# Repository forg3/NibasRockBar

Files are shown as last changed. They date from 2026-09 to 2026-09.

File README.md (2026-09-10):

# NibasRockBar — Pulseira Inteligente de Identificação e Localização

Sistema de pulseira eletrônica (NFC + BLE) para identificação de clientes e localização
indoor no salão, integrado ao sistema de caixa **Deli**. Atendimento continua 100% humano —
garçom tira o pedido, equipe serve bebidas e a cozinha prepara os pratos. A pulseira só
identifica o cliente e ajuda a equipe a localizá-lo mais rápido.

## Fluxo do produto

1. **Check-in** — cliente recebe uma pulseira livre; o sistema abre a comanda no Deli.
2. **Pedido** — garçom lê a pulseira (NFC) e lança o pedido na comanda certa, em qualquer mesa.
3. **Localização** — o app do garçom mostra a área do salão onde cada comanda está (BLE).
4. **Conferência e saída** — caixa fecha a comanda no Deli, cliente paga, pulseira libera
   sozinha para o próximo cliente.

## Estrutura do repositório

| Caminho | Conteúdo |
|---|---|
| `PROPOSTA_SMART_BADGE_PUB_v3.md` | Especificação do produto (hardware, fluxo, fabricação) |
| `proposta_proprietario.html` | Proposta visual para apresentar ao proprietário do pub |
| `modelo_3d_prototipo.html` | Modelo 3D interativo do protótipo (pulseira + disco) |
| `ORCAMENTO_PROTOTIPAGEM.md` | Orçamento detalhado para 5 unidades protótipo |
| `BOM_custos_prototipos.csv` | BOM com custo por unidade (lote de teste) |
| `BOM_smartbadge_v2.csv` | BOM recomendada (módulo BLE certificado) |
| `BOM_discreta_corrigida_nRF52810_QFN32.csv` | BOM alternativa (SoC discreto), pinagem verificada no datasheet Nordic |
| `netlist_conexoes.md` | Tabela de conexões pino a pino, pronta para KiCad |
| `RELATORIO_REVISAO_TECNICA.md` | Revisão técnica completa (matemática de bateria, RF, RSSI, NFC) |
| `firmware/main.c` | Firmware da pulseira (nRF5 SDK) — beacon BLE + leitura de bateria |
| `firmware/nrf/` | Projeto de compilação nRF5 SDK 17.1.0 (pca10040e/s112, nRF52810 + SoftDevice S112 7.2.0) — compila com `make -C firmware/nrf/armgcc` (requer `arm-none-eabi-gcc`) |
| `gateway_esp32/gateway_esp32.ino` | Firmware do gateway de teto (scan BLE + filtro EWMA + MQTT) — compila no Arduino IDE com esquema de partição Huge APP |
| `backend/app.py` | Servidor local (FastAPI) — localização por RSSI + inventário de pulseiras |
| `backend/deli_adapter.py` | Integração real com a API pública do Deli (plataforma Fudo) |
| `integracao_deli/README.md` | Como habilitar e usar a API do Deli |
| `hardware/kicad/docs/decisao_forma_fisica.md` | Decisão da variante A: troca do módulo E73 pelo Fanstel BM832A |
| `hardware/kicad/docs/layout_status.md` | Estado atual dos layouts das placas |
| `hardware/kicad/docs/procedimento_vna.md` | Procedimento de tuning da antena/RF com VNA |
| `hardware/kicad/docs/cotacao_fabricacao.md` | Cotação de fabricação (com GATE — nada submetido ainda) |
| `hardware/kicad/*/exports/fab/` | Pacote de fabricação gerado (Gerbers, furação, BOM, posição) |
| `docs/security-audit/relatorio-auditoria-seguranca.pdf` | Relatório da auditoria de segurança |

## Arquitetura (visão geral)

```
Pulseira (NFC + BLE) ──► Gateway ESP32 (scan BLE) ──► MQTT ──► Backend local (FastAPI)
                                                                      │
                                                                      ├─► Localização por mesa/zona
                                                                      └─► Deli API (abre/monitora comanda)

Garçom (app/tablet) ──► lê NFC da pulseira ──► lança pedido direto no Deli
```

- **Identificação (NFC)**: tag passiva na pulseira, lida pelo garçom para abrir/lançar pedidos.
- **Localização (BLE)**: pulseira transmite beacon; gateways de teto (ESP32) captam RSSI e
  publicam via MQTT; o backend decide a zona mais próxima (vizinho mais próximo com histerese).
- **Caixa/pagamento**: sempre no Deli — este projeto não duplica cardápio, pagamento nem fiscal.

## Como rodar o backend localmente

```bash
cd backend
pip install -r requirements.txt
export DELI_API_KEY="..."
export DELI_API_SECRET="..."
export NIBAS_API_KEY="..."  # exigida em toda chamada via header X-API-Key
uvicorn app:app --host 0.0.0.0 --port 8000
```

Requer um broker MQTT local (ex: Mosquitto) publicando em `pub/telemetria/#`.

## Hardware

- Disco Ø32 mm, cápsula IP67, pulseira esportiva de silicone.
- Identificação: NXP NTAG213 (inlay pronto, 25 mm).
- Localização (variante A): módulo **Fanstel BM832A** (SoC Nordic nRF52810) — substitui o
  Ebyte E73, decisão documentada em `hardware/kicad/docs/decisao_forma_fisica.md`.
- Bateria: CR2032 com suporte **Keystone 1060** (SMD — o 1059 é THM e não serve),
  ~1,5–2 anos de autonomia estimada.
- Fabricação recomendada: PCBWay ou JLCPCB, regime turnkey.

Detalhes completos, matemática de engenharia e decisões de projeto: ver
`RELATORIO_REVISAO_TECNICA.md` e `PROPOSTA_SMART_BADGE_PUB_v3.md`.
Estado dos layouts: `hardware/kicad/docs/layout_status.md`.
Tuning da antena/RF: `hardware/kicad/docs/procedimento_vna.md`.

## Fabricação

- Pacote de fabricação gerado em `hardware/kicad/*/exports/fab/` (Gerbers, furação, BOM, posição).
- Cotação e checklist de submissão em `hardware/kicad/docs/cotacao_fabricacao.md` —
  **GATE: nada submetido a fabricante ainda.**

## Segurança

- O backend exige autenticação em toda chamada via header `X-API-Key` (chave em `NIBAS_API_KEY`).
- Relatório da auditoria de segurança em `docs/security-audit/relatorio-auditoria-seguranca.pdf`.

## Status

Fase de especificação e protótipo — orçamento para lote de 5 unidades de teste em
`ORCAMENTO_PROTOTIPAGEM.md`. Integração com o Deli implementada e documentada, pendente de
credenciais reais (`DELI_API_KEY`/`DELI_API_SECRET`) para teste de ponta a ponta.

## Pendências

- ANATEL: item aberto (não bloqueia bancada; confirmar antes de operar com público).
  Homologação vale só para os radiadores intencionais (BM832A e ESP32, 2,4 GHz) — PCB,
  bateria, NFC passiva, ferrite e cápsula não certificam; se os módulos já forem
  homologados, o produto usa processo simplificado com os laudos do módulo (confirmar com OCD).
- BOM raiz: corrigir Keystone 1059 → 1060.
- Alimentação do BM832A: indutores do DC/DC integrados ao módulo (fonte: página oficial
  Fanstel) — fecha o item aberto #2.

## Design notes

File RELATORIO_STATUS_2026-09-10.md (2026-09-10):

---
title: "2º Relatório de Status do Projeto"
subtitle: "NibasRockBar — Smart Badge Pub (pulseira NFC+BLE + gateway ESP32)"
date: "10 de setembro de 2026"
lang: pt-BR
---

# 1. Contexto e base deste relatório

Este é o 2º relatório de status. Cobre o delta desde o `RELATORIO_TRABALHO_2026-09-09`
(sessões de esquemáticos + layouts + firmware + GitHub).

**Fontes lidas para este relatório:**

- `hardware/kicad/docs/layout_status.md`
- `hardware/kicad/docs/decisao_forma_fisica.md`
- `hardware/kicad/docs/cotacao_fabricacao.md`
- `hardware/kicad/docs/procedimento_vna.md`
- `hardware/kicad/wristband_discreto/exports/audit.md`
- `hardware/kicad/wristband_modulo/exports/audit.md`
- `hardware/kicad/gateway_esp32/exports/audit.md`
- `git log` (HEAD = `d4b8bd6`, sincronizado com `origin/main`; ~50 arquivos modificados/novos no working tree, ainda não commitados)
- JSONs de DRC atuais no working tree (`exports/drc_*.json`), footprints em `hardware/kicad/libs/`, `firmware/nrf/armgcc/_build/`, pacotes `exports/fab/`

**Decisões de negócio seguem fechadas:** sem self-service (garçom tira o pedido, equipe serve tudo);
pulseira só identifica e localiza; Deli é o sistema de registro/pagamento/fiscal; checkout automático
apenas por polling de `saleState` (o projeto nunca fecha comanda por conta própria).

---

# 2. Decisão física: E73 → Fanstel BM832A

**Decidido** (`docs/decisao_forma_fisica.md`, 2026-09-09). A variante A troca o módulo
Ebyte E73-2G4M04S-52810 (17,5 × 28,7 mm, diagonal ≈ 33,5 mm) pelo **Fanstel BM832A**
(nRF52810, **10,2 × 15 × 1,9 mm**, diagonal ≈ 18,2 mm, US$ 3,61 vs US$ 3,59 — paridade de preço).

Por que:

1. **Sem cápsula Ø34–38 no mercado.** Não existe cápsula vazia IP67 redonda Ø34–38 mm à venda.
   O que existe são beacons prontos (Trax10214 Ø35,9 mm; Minew B10 Ø38 mm; Minew E7 Ø39 × 15,5 mm
   IP67 — menor cápsula comprovada, para CR2477). Aumentar a cápsula além de Ø32 mm exigiria
   moldagem custom (ferramental + NRE), inviável para protótipo de 5 unidades.
   Fontes: beacontrax.com, minew.com, takachi-enclosure.com.
2. **Overhang castelado refutado.** JLCPCB e PCBWay exigem furo PTH bissecado pelo contorno +
   pad com extensão ≥ 0,5 mm para dentro do contorno. Os pads das pontas do E73 ficariam fora do
   arco do disco (sagitta ≈ 1,65 mm) — viola a regra nas duas casas. Manter o E73 com overhang
   **não é fabricável**.
3. **BM832A encaixa, custa igual, zero migração de firmware.** Mesmo SoC nRF52810 → SoftDevice S112
   funciona direto. VDD 1,7–3,6 V (CR2032 ok). Antena integrada + certificações FCC/CE/TELEC.
   **Indutores do DC/DC integrados ao módulo** (página oficial Fanstel) — fecha o item aberto #2
   do relatório anterior (dúvida do indutor interno do E73-2G4M04S1A).

**Ressalva honesta (registrada no doc):** diagonal caber no disco não significa layout fechado.
O keepout de antena do BM832A (antena estendida fora do ground plane — verificar dimensões exatas
no manual Fanstel) e a coexistência com BT1 (porta-pilha CR2032) e TAG1 (NTAG213) precisam de
validação geométrica no KiCad antes de considerar a placa resolvida. Impacto previsto: novo
símbolo + footprint do BM832A (transcritos do datasheet Fanstel), troca de U1 no `.kicad_sch`
da variante A, re-layout da placa.

---

# 3. Footprints corrigidos

## 3.1 Porta-pilha: Keystone 1060 (não 1059)

O footprint antigo `Keystone_1059_CR2032_SMT` foi **removido** — e com motivo: **Keystone 1059 é a
variante THM**; a variante SMT correta é a **Keystone 1060** (série Vibra-Fit, low-profile para
CR2032/CR2025). Novo footprint `Keystone_1060_CR2032_SMT` com dimensões do **drawing oficial
Keystone 1060 rev C** (`https://www.keyelco.com/product-pdf.cfm?p=726`, registrado no campo
Datasheet do footprint): pads de montagem 11,00 × 7,01 mm no centro + abas de 2,59 × 3,61 mm,
centros das abas a ±14,655 mm (29,31 mm centro a centro); corpo 28,40 × 22,00 mm, altura 5,51 mm.
Fecha a pendência #1 do relatório anterior (footprint UNVERIFIED causador de 7 dos 12
`courtyards_overlap` da variante B).

## 3.2 Carrier do gateway: ESP32-DevKitC-32E a 27,94 mm

Novo footprint `ESP32-DevKitC-32E_Carrier` em `nibas_gateway.pretty`: dois soquetes fêmea 1×19
para os headers J2/J3, com **27,94 mm entre fileiras** (largura real do módulo DevKitC-32E,
conforme esquemático oficial Espressif DevKitC V4). Fecha a pendência #7 do relatório anterior
(o board antigo usava `PinHeader_2x19` com 2,54 mm entre fileiras — o DevKitC físico não encaixava).
Nota: o esquemático e a lib já apontam para a carrier (módulo 55 × 28); a migração do board
exigiu redimensionamento (ver §4).

---

# 4. Layouts: estado final

Comandos de re-verificação (KiCad 10.0.6): `kicad-cli pcb drc <board>.kicad_pcb
--schematic-parity --refill-zones --severity-error --format json` e `--all-track-errors`.
Números abaixo lidos dos JSONs atuais no working tree.

| Item | Discreta (Var. B, QFN32) | Módulo (Var. A, BM832A) | Gateway (carrier DevKitC) |
|---|---|---|---|
| Edge.Cuts | círculo r=16,000 exato | círculo r=16,000 exato | retângulo **62×36** exato (era 60×32) |
| DRC `--severity-error` | **2 físicos** (`copper_edge_clearance`) — restante do JSON é silk cosmético (16 `silk_overlap` + 16 `silk_over_copper` + 5 `silk_edge_clearance`); era 27 | **28 físicos** (13 `clearance` + 12 `solder_mask_bridge` + 2 `copper_edge_clearance` + 1 `courtyards_overlap`) | **0** |
| Unconnected | **16** (rotas de sinal + stitches GND pendentes) | **0** | **0** |
| Shorting / parity | 0 / 0 | 0 / 0 | 0 / 0 |
| Veredito | Não fabricável — acabamento manual pendente | Não fabricável isolado — física do Ø32 em decisão (ver §2 ressalva) | **Pronto isolado** (ver GATE §6) |

Leitura:

- **Discreta:** caiu de 27 errors/22 unconnected para **2 físicos/16 unconnected**. Os 9 GND sem
  stitch e as 13 rotas de sinal seguem exigindo re-placement dos passivos (afastar caps de
  decoupling/cristal do muro de pads do U1) ou acabamento manual no roteador interativo do
  KiCad 10. Keepout de antena (canto NE, margem ~3 mm da Johanson) segue como regra do gerador,
  sem zona nativa — edit manual não seria bloqueado.
- **Módulo:** 0 unconnected, 0 shorting, punch list de rotas fechada; os 28 errors são a física
  documentada do Ø32 + resíduos de solda/máscara a tratar no re-layout para o BM832A (footprint
  10,2 × 15 mm, bem menor que o E73 — a troca tende a reduzir esses errors, a confirmar no DRC
  do novo board).
- **Gateway:** 0 errors, 0 unconnected, 0 parity; warnings de furo (`hole_to_hole`/
  `holes_co_located`, 13 no estado auditado) fechados ao afastar as vias de stitch GND dos PTHs
  (offsets ≥ 1,6 mm, validação furo-a-furo ≥ 0,6 mm). Board redimensionado de 60×32 para **62×36**
  para acomodar a carrier 55×28 + J1/SW1/R1 sem sobreposição de courtyard.

---

# 5. Firmware e segurança

- **nRF52810 compila.** Toolchain instalada (`arm-none-eabi-gcc` + nRF5 SDK-style em `firmware/nrf/`):
  `firmware/nrf/armgcc/_build/nrf52810_xxaa.hex` gerado (≈ 105 KB, **~37 KB de aplicação**),
  SoftDevice **S112 7.2.0** (`firmware/nrf/softdevice/s112_nrf52_7.2.0_softdevice.hex`).
  Fecha a pendência #4 do relatório anterior ("nRF não compilável localmente"). Correções aplicadas:
  leitura real de bateria via SAADC (fim do placeholder `vbat=3.0f`), símbolos pendentes,
  filtro de Company ID (`0xFFFF`, little-endian), rate-limit por tag, timeouts de 15 s no Wi-Fi/MQTT
  do gateway, bloco CONFIG com TODO de provisioning via Preferences/NVS.
- **ESP32 compila** (arduino-cli + core esp32, partition scheme huge_app), incluindo as mudanças
  de segurança abaixo.
- **Segurança corrigida e pusheada (commit `d4b8bd6`, sincronizado com `origin/main`):**
  autenticação por API key no backend, suporte a credenciais MQTT (antes anônimo/aberto),
  validação de entradas, fim do eco de erro de upstream, cobertura de `.gitignore` (sem risco de
  credenciais Deli — `DELI_API_KEY`/`DELI_API_SECRET` seguem em variáveis de ambiente),
  higiene de dependências (`backend/requirements.txt`). Detalhes em `docs/security-audit/`
  (`relatorio-auditoria-seguranca.pdf` + `gerar_relatorio.py`).

---

# 6. Fabricação: pacotes prontos + cotação com GATE

- **Pacotes fab gerados** via `kicad-cli` (nunca GUI) em `exports/fab/` das 3 placas:
  Gerbers RS-274X (F.Cu, B.Cu, F.Mask, B.Mask, F.SilkS, B.SilkS, Edge.Cuts), Excellon + mapa de
  furos, `bom.csv`, `pos_jlc.csv` (centroide), `*-job.gbrjob`.
- **Cotação** (`docs/cotacao_fabricacao.md`, 2026-09-10, pesquisa web sem login, **nenhum pedido
  submetido**): 3 designs, 2L, ENIG, 5 peças por design. Pulseiras Ø32 0,8 mm; gateway 62×36
  1,6 mm. Estimativas: JLCPCB ~US$ 10–22 (PCBs) / total com 1 stencil + DHL ~US$ 31–69;
  PCBWay ~US$ 21–42 / total ~US$ 54–112. Custo dominante: ENIG + frete, não a placa nua.
  Valores são faixas — o número exato só sai na calculadora oficial com o Gerber anexado.
- **GATE de envio (regra: DRC 0 error E sem pendência física/roteamento):**

| Placa | GATE |
|---|---|
| Gateway 62×36 | [OK] **PRONTO PARA ENVIAR isoladamente** |
| Pulseira discreta | [NAO] NÃO ENVIAR — 2 físicos + 16 unconnected |
| Pulseira módulo | [NAO] NÃO ENVIAR — 28 errors de física + re-layout BM832A pendente |

  **Veredito do lote: LOTE NÃO PRONTO.** Opção: fabricar só o gateway (pedido isolado, 5 unid.)
  enquanto as pulseiras fecham layout — decisão do responsável. **Nada foi enviado**: sem conta,
  sem upload, sem checkout. Antes de qualquer upload: re-rodar DRC 0-error no board final,
  conferir soquete 27,94 mm e dimensão 62×36, revisão visual dos Gerbers.

---

# 7. Verificações

- **DC/DC do BM832A: OK.** Indutores do DC/DC integrados ao módulo (fonte: página oficial
  Fanstel). Sem o DC/DC a autonomia cairia de 1,66 ano para 0,96 ano (cálculo verificado no
  relatório anterior, PS §5.2.1.2) — com o BM832A o DC/DC é condição atendida, não aposta.
- **ANATEL: sem certificado localizado.** A base de consulta pública estava indisponível no dia
  (fora do ar); alternativa registrada: base Qlik / laboratório de homologação no Brasil.
  Status inalterado e honesto: bloqueia operação comercial com público, **não bloqueia
  bancada/laboratório**. Usar módulo certificado mantém o enquadramento como equipamento derivado
  (processo mais simples que homologar design discreto próprio).
- **Procedimento VNA** (`docs/procedimento_vna.md`, rev A): tuning da rede de 2 elementos da
  variante B (C3 0,8 pF shunt + L1 3,9 nH série, ref. Nordic PS v1.3 Fig. 146) com placa de
  sacrifício, bateria + ferrite presentes, critério S11 < −9,5 dB (VSWR < 2) em 2400–2480 MHz,
  tabela de registro + print do VNA no dossiê. L3 (15 nH) é do ladder DC/DC — não mexer.

---

# 8. O que falta (tabela honesta)

| # | Item | Estado | Próximo passo |
|---|---|---|---|
| 1 | Acabamento manual das rotas (discreta: 2 físicos + 16 unconn) | Aberto | Re-placement dos passivos + regenerar, ou roteador interativo no GUI KiCad 10; stitches GND C1/C2/C4–C9, U1.20/29, ANT1.2; rotas XC1/XC2, DEC1/3/4, DCC, SWDCLK/SWDIO, RESET |
| 2 | Re-layout da variante A para o BM832A no Ø32 | Aberto | Novo símbolo + footprint (datasheet Fanstel), troca de U1, re-layout; validar keepout de antena + coexistência BT1/TAG1 geometricamente; DRC até 0 error |
| 3 | Decisão Ø32 documentada | Feita (E73→BM832A) | Registrar no `designator_map.md`/BOM a troca de PN; manter alternativa descartada (cápsula Ø39 custom) fora do plano |
| 4 | Toolchain nRF | **Pronto** (compila, S112 7.2.0) | Integrar `main.c` ao projeto real (pca10040e/blank + S112); corrigir `sd_ble_gap_adv_data_set` → `sd_ble_gap_adv_set_configure`; `JsonDocument` no gateway; `APP_ERROR_CHECK` em `app_timer_create/start` |
| 5 | Gateway 62×36 | Pronto isolado | Decisão: pedido isolado agora vs. aguardar pulseiras; gerar pacote final + cotar na calculadora oficial |
| 6 | ANATEL | Aberto (sem certificado) | Re-tentar consulta pública; alternativa Qlik/laboratório; confirmar com Fanstel antes de operação com público |
| 7 | Bancada RF | Procedimento pronto, não executado | VNA na variante B após fabricação; ajustar S11 da rede C3/L1 |
| 8 | STEP sem corpos 3D | Aberto (cosmético) | Instalar `kicad-packages3d` se a conferência visual exigir |

---

# 9. Histórico git (evidência)

- `d4b8bd6` (2026-09-10) — segurança backend/gateway, **pusheado** (`origin/main` sincronizada)
- `77ed5e1` (2026-09-09) — bugs de firmware (SAADC, timeouts, Company ID, rate-limit)
- `beab01e` (2026-09-09) — esquemáticos, layouts, docs de verificação + 1º relatório
- Working tree atual: ~50 arquivos modificados/novos (footprints Keystone 1060 + BM832A + carrier,
  re-layouts, DRC JSONs, pacotes `fab/`, docs de decisão/cotação/VNA, `firmware/nrf/`,
  `docs/security-audit/`) — **ainda não commitados** no momento deste relatório.

---

# 10. Como verificar tudo

```bash
# DRC (0 error = alvo)
kicad-cli pcb drc <placa>/<placa>.kicad_pcb --schematic-parity --refill-zones \
  --severity-error --format json --output <placa>/exports/drc_<placa>.json
kicad-cli pcb drc <placa>/<placa>.kicad_pcb --all-track-errors \
  --format json --output <placa>/exports/drc_tracks_<placa>.json

# Regenerar boards (idempotente)
python3 hardware/kicad/wristband_discreto/gen_board_v2.py
python3 hardware/kicad/wristband_modulo/gen_board_modulo.py
python3 hardware/kicad/gateway_esp32/gen_board_gateway.py

# Firmware nRF
ls firmware/nrf/armgcc/_build/nrf52810_xxaa.hex firmware/nrf/softdevice/s112_nrf52_7.2.0_softdevice.hex
```

*Relatório gerado em 2026-09-10 a partir de `hardware/kicad/docs/`, `exports/audit.md` ×3,
DRC JSONs atuais, footprints, `firmware/nrf/`, `docs/security-audit/` e histórico git.*

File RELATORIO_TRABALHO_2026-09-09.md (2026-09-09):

---
title: "Relatório Completo da Sessão de Trabalho"
subtitle: "NibasRockBar — Smart Badge Pub (pulseira NFC+BLE + gateway ESP32)"
date: "09 de setembro de 2026"
lang: pt-BR
---

# 1. Contexto do projeto

O NibasRockBar é uma pulseira eletrônica (NFC + BLE) para identificação de clientes e localização indoor no salão do pub, integrada ao sistema de caixa **Deli** (plataforma Fudo, API pública em `api.fu.do`).

**Decisões de negócio já fechadas (não reabrir sem motivo novo):**

- **Sem self-service**: o garçom tira o pedido e a equipe serve tudo. A pulseira só identifica e localiza — não aciona nada fisicamente (sem torneira automática, sem válvula).
- **Forma física**: disco Ø32 mm, cápsula IP67, pulseira esportiva de silicone; bateria CR2032.
- **Rádio**: módulo BLE certificado (nRF52810), não SoC discreto com antena própria — simplifica homologação ANATEL.
- **Identificação**: NXP NTAG213 (inlay pronto), com blindagem de ferrite entre a bobina NFC e a bateria.
- **Fluxo**: check-in (abre comanda no Deli) → pedido (garçom lança no Deli; pulseira só identifica) → localização (BLE, assistência ao garçom) → checkout automático quando o caixa fecha a comanda no Deli (polling de `saleState`; o projeto nunca fecha a comanda por conta própria).
- **Divisão de responsabilidade**: Deli é o sistema de registro de pedido/pagamento/fiscal; este projeto nunca duplica cardápio nem processa pagamento.

A sessão de 2026-09-09 executou dois planos encadeados: **`kicad-esquematicos-verificacao`** (SESSÃO 1 — esquemáticos KiCad + verificação independente) e **`plano_frentes_A_B_C`** (SESSÃO 2 — layouts PCB, correções de firmware e preparação do GitHub).

---

# 2. SESSÃO 1 — Esquemáticos KiCad (plano `kicad-esquematicos-verificacao`, 6 ondas)

## 2.1 O que foi entregue

Três esquemáticos KiCad 10.0.6 gerados por código (S-expression via `kicad-cli`, sem GUI), cada um com **ERC com 0 violações** (error+warning+exclusion), netlist exportada e PDF vetorial:

| Placa | Conteúdo | ERC |
|---|---|---|
| `wristband_modulo` (Variante A) | Módulo BLE **Ebyte E73-2G4M04S-52810** (nRF52810, SoftDevice S112 direto), NTAG213 inlay, Keystone 1059, J1, ferrite SHLD1, C1/C2, TP1–TP4 | 0 violações |
| `wristband_discreto` (Variante B) | **nRF52810-QCAA QFN32** com topologia de referência Nordic Fig. 146: rede RF de 2 elementos (C3 0,8 pF shunt + L1 3,9 nH série), ladder DC/DC (DCC→L2 10 µH→L3 15 nH→DEC4 + C10 1,0 µF), cristal 32 MHz CL=8 pF com 2×12 pF, desacoplos completos | 0 violações |
| `gateway_esp32` | Carrier para **ESP32-DevKitC-32E** (soquete 2×19, entrada 5 V, EN com pull-up 10 k + botão) | 0 violações |

Libs customizadas em `hardware/kicad/libs/` (`nibas_wristband`, `nibas_gateway`): símbolo NTAG213 inlay, footprint Keystone 1059 (SMT, dims UNVERIFIED — ver pendências), SHLD1 ferrite, J1 contato negativo, símbolo ESP32-DevKitC-32E. Receita completa de geração documentada em `docs/kicad10_recipe.md` (8 regras do parser descobertas empiricamente).

## 2.2 Correções da revisão cruzada (o anti-slop funcionando)

A verificação independente (sessões fresh, sem herdar artefatos anteriores como fonte de verdade) pegou erros reais antes que virassem hardware:

- **Pinout E73 errado na pesquisa**: a tabela original citava SWD nos pads 40/41 e nRESET no pad 33. Correto, confirmado em 4 fontes (datasheet oficial E73-2G4M04S1A, símbolo KiCad padrão, esquemático aprovado, manual rev 1.8): **SWDCLK=37, SWDIO=38, nRESET/P0.21=36, P0.18=33**.
- **Alucinação "VDD = pino 25 único" refutada**: o `datasheet_facts_nordic.md` §1.1 afirmava VDD=25 único, DEC4=31, DCC=32 e um "P0.29" que não existe no QFN32 — e ainda invertia o veredito ("pinagem do projeto é INCORRETA"). Refutado por 3 fontes independentes (PS v1.3 Tabela 114, DevZone #53125, símbolo KiCad `MCU_Nordic:nRF52810-QCxx`): **correto é VDD = 9/25/32; DEC4=30; DCC=31**. A pinagem do projeto estava certa; o facts file é que estava errado.
- **Topologia RF: Π de 4 elementos → 2 elementos**: a Fig. 146 do PS v1.3 (extraída vetor a vetor via PyMuPDF) mostra o casamento de referência como **ANT(19) → C3 0,8 pF shunt → L1 3,9 nH série → antena**. L3 15 nH pertence ao ladder DC/DC e C7 100 pF é desacoplo de DEC3 — nenhum dos dois está no caminho de RF. Esquema corrigido e confirmado na netlist as-built.
- **C8/DEC2/DEC3**: o projeto antigo amarrava DEC2+DEC3 com C8 100 nF único ("crítico"). A referência Nordic mostra **DEC3→100 pF, DEC2→posição N.C. (DNP), C8 100 nF no VDD**. Corrigido no esquema e no `designator_map.md`.
- **F1 (doc DEC/DCC da variante A)**: a pesquisa mandava conectar caps DEC e indutor de 10 µH externos ao módulo E73 — o manual oficial rev 1.8 §4.1 e o FAQ Ebyte confirmam que desacoplos e DC/DC são **internos ao módulo**; pads DEC/DCC ficam NC. Corrigido no doc.
- **24 correções visuais** aplicadas ao esquemático da variante B pela conferência do critic/vision (fios, labels, alinhamentos, anotações).

## 2.3 Verificação matemática independente: 27/27 vereditos

Recontagem do zero contra fontes primárias (PS v1.3 lido pino a pino, Energizer CR2032, Johanson, Ebyte, arduino-esp32):

- **21 CONFIRMADOS** (6 com ressalva): I_s 1,5 µA; t_a 3 ms conservador; CR2032 235 mAh nominal/180–200 úteis; TX default 0 dBm; FSPL(10 m)=60 dB; sensibilidade −96 dBm; margem de link ~10–11 dB (apertada); expoente n=2,5–4 + corpo 10–20 dB; assimetria ±6 dB (+58,5 %/−36,9 %); pinagem QFN32 completa; cristal CL=8 pF→2×12 pF; ladder DC/DC; ferrite NFC; EWMA α=0,2; unidades de scan ESP32; MDBT42Q=nRF52832 (incompatível com S112 — resolvido pelo E73); ANATEL por módulo (princípio); aritmética do orçamento (R$ 2.514,00 fecha).
- **4 DIVERGENTES — todos tratados**:
  1. **I_a 5,0 mA → 5,8 mA** (sistema com DC/DC, PS §5.2.1.2; 4,6 mA é pico do rádio): autonomia real = **1,66 anos com DC/DC** vs **0,96 ano em modo LDO** (perde a meta de 12 meses — o DC/DC é condição do resultado).
  2. **Topologia Π** não é a referência Nordic (corrigida para 2 elementos, ver §2.2).
  3. **C8/DEC2/DEC3** — corrigido conforme Fig. 146.
  4. **Mapeamento linear de bateria 3,0→2,0 V** — a curva da CR2032 é plana; o mapa linear lê ~80–90 % durante quase toda a vida. Aceitável só como limiar "ok/fraca"; recomendação: limiar (<2,5 V) + tendência.

## 2.4 Critic final

**ACCEPT**, com 13 resíduos classificados como **documental-cosméticos** (descriptions desatualizadas, citação de tabela divergente entre docs, gap de anotação #PWR0111, fios/labels duplicados sobrepostos, BOM raiz stale) — nenhum elétrico, nenhum bloqueia as fases seguintes. Cross-checks: variante B **10/10 tarefas OK** (~60 itens verificados); variante A + gateway **9/9 OK** (veredito DC/DC do E73: OK condicional, com fonte do fabricante).

---

# 3. SESSÃO 2 — Frentes A/B/C (plano `plano_frentes_A_B_C`)

## 3.A) Layouts PCB ×3

**Abordagem**: script Python via API `pcbnew` (primário) com `tools/board_builder.py` como módulo compartilhado; fallback textual provado no spike. Regra do ambiente: nunca invocar o binário GUI — só `kicad-cli` + `python3+pcbnew`. Comandos DRC/export validados e documentados em `docs/layout_approach.md` (nota: no KiCad 10, `pcb export pdf` exige `--layers`).

**Estado por placa:**

| Item | Discreta (Var. B, QFN32) | Módulo (Var. A, E73) | Gateway (carrier DevKitC) |
|---|---|---|---|
| Edge.Cuts | círculo r=16,000 exato | círculo r=16,000 exato | retângulo 60,00×32,00 exato |
| DRC error | 27 | 26 | **0** |
| Composição | 12 courtyards_overlap (7 envolvem BT1/Keystone 1059 UNVERIFIED) · 8 copper_edge_clearance · 6 clearance · 1 mask | 11 copper_edge_clearance (10 pads físicos do E73 na periferia + 1 resíduo ~0,02 mm) · 6 clearance · 5 courtyards (BT1×U1 — física do Ø32) · 4 mask | — |
| Unconnected | 22 (13 rotas de sinal + 9 GND sem stitch) | **0** (punch list fechada) | **0** |
| Parity | 0 | 0 | 0 |
| Curtos | 0 | 0 | 0 |
| Veredito da auditoria | REPROVADO (estado da auditoria; board regenerado depois) | REPROVADO → punch list FECHADA (restam só erros de física documentada) | APROVADO COM PENDÊNCIAS |

**Keepouts de antena** (valor + fonte): Discreta — canto NE do disco, ~3 mm de margem da Johanson (regra no gerador, sem zona nativa); Módulo — extremidade oeste (NOTA 4 do esquemático, y_local < −8,85 mm), zona nativa presente e confirmada com 0 cobre; Gateway — extremidade leste (antena PCB do DevKitC), 0 cobre verificado nas duas camadas.

**Bugs pegos pelas auditorias (e corrigidos):**

- **Círculo r=130,6 mm ×2**: `SetCenter()` sem `SetEnd()` fazia o raio virar ~130,6 mm em vez de 16 mm (detectado na auditoria da variante B; o mesmo bug existia em potencial no gerador da variante B — padrão de correção `SetCenter`+`SetEnd` portado do `gen_board_modulo.py`). As 3 placas ativas têm Edge.Cuts verificado.
- **Duplo-flip J1**: na variante B, `FLIP_REFS` aplicou ao SHLD1 mas não ao J1 (contato negativo ficou em F.Cu em vez do verso).
- **Pads `<no net>`**: na variante A, ilha VDD_BAT do BT1 colidia com pads sem-net do U1 (mesma causa: sobreposição física BT1×U1).
- **Obstáculos de via**: stitches GND bloqueados por pads/vias vizinhos — resolvido na variante A com offsets 0,6–0,9 mm × 8 direções; na variante B, 9 pads GND seguem sem via.

## 3.B) Firmware

**6 bugs corrigidos** (arquivos permitidos: `firmware/main.c` e `gateway_esp32/gateway_esp32.ino`):

| Bug | Correção |
|---|---|
| B1 | Leitura de bateria real via SAADC (canal 0 = VDD, gain 1/6, ref 0,6 V, oversample 4×, burst) — fim do placeholder `vbat=3.0f` |
| B2 | Símbolos não declarados: `ram_start`, `m_adv_handle`, `APP_BLE_CONN_CFG_TAG` |
| B3 | Bloco CONFIG separado no `.ino` com TODO de provisioning via Preferences/NVS |
| B4 | `connectWiFi()`/`connectMQTT()` com timeout de 15 s (`millis()`) — não travam mais o boot |
| B5 | Filtro de Company ID implementado de verdade (`EXPECTED_COMPANY_ID = 0xFFFF`, little-endian, descarta advertiser desconhecido) |
| B6 | Rate-limit por tag usando `PUBLISH_PERIOD_MS` (antes: publish imediato por pacote) |

Mais 2 fixes de build: cast explícito no `mqttClient.publish` (evita overload com flag retained) e correção do índice mínimo do manufacturer data (6 bytes, não 5).

**Registro honesto de compilação**: ESP32 **compila** (arduino-cli, core esp32, partition scheme huge_app); nRF52810 **não compilável localmente** (sem `arm-none-eabi-gcc`, sem nRF5 SDK 17, sem Makefile/sdk_config — `main.c` é esqueleto de referência por declaração própria).

**Punch list pré-integração (nRF)**: a chamada `sd_ble_gap_adv_data_set` (main.c:128) é da API antiga do SoftDevice — no SDK 17 o correto é `sd_ble_gap_adv_set_configure`; demais itens menores listados na seção 4.

## 3.C) GitHub

- Remote `origin` = `https://github.com/forg3/NibasRockBar.git`; `gh` autenticado como `forg3` (keyring, escopo repo+workflow) → push funcionará.
- `main` sincronizada com origin em `6ff2dfc` (0/0).
- Trabalho pendente de commit: dirty = `.bob/`, `.opencode/`, `hardware/` + modificações em `firmware/main.c` e `gateway_esp32/gateway_esp32.ino`. `.gitignore` já cobre `.env`/`*.env` (sem risco de credenciais Deli). Convenção: commits em inglês, 2 commits (hardware; firmware).

---

# 4. Pendências consolidadas

| # | Item | Impacto | O que precisa para resolver |
|---|---|---|---|
| 1 | **Keystone 1059 UNVERIFIED** | 7 dos 12 courtyards_overlap da variante B podem ser falsos positivos (footprint custom com dims não conferidas) | Baixar o drawing oficial do site Keystone → conferir/corrigir o footprint `nibas_wristband:Keystone_1059_CR2032_SMT` |
| 2 | **DC/DC no E73-2G4M04S1A** | Se não houver indutor interno, habilitar DC/DC degrada o rail de 1,3 V; sem DC/DC a autonomia cai de 1,66 a → 0,96 a | Confirmar em 1 linha com o suporte Ebyte (service@cdebyte.com) que o 1A tem o indutor DC/DC interno (a confirmação atual é por família, via FAQ do 1B) |
| 3 | **ANATEL do módulo** | Bloqueia operação comercial com público (não bloqueia bancada/laboratório) | Consulta na base pública ANATEL / suporte Ebyte — certificado do E73 não localizado online |
| 4 | **nRF não compilável** | Impossível validar firmware da pulseira antes da bancada | Instalar `arm-none-eabi-gcc` + nRF5 SDK 17 + Makefile/sdk_config (ou portar); corrigir `sd_ble_gap_adv_data_set` → `sd_ble_gap_adv_set_configure` |
| 5 | **Discreta: 13 rotas de sinal pendentes** + 9 GND sem stitch | Placa não fabricável no estado atual | Re-placement dos passivos (afastar caps do muro de pads do U1) e regenerar, ou acabamento manual no GUI KiCad 10 com o roteador interativo |
| 6 | **Módulo: E73 não cabe no Ø32** | Pads U1.15/16/27/28 ficam a r=16,24–16,86 mm (fora do disco); BT1×U1 sobrepostos | Decisão de projeto: cápsula maior / módulo menor (checar variantes da família E73) / aceitar overhang na borda |
| 7 | **Gateway: soquete errado** | Fileiras a 2,54 mm vs 27,94 mm reais do DevKitC-32E — o DevKit físico NÃO encaixa | Trocar para footprint custom `ESP32-DevKitC-32E_Carrier` (2× soquete fêmea 1x19 a 27,94 mm) e regenerar antes de fabricar |
| 8 | **RF: tuning em bancada** | Matching final (C3/L1) só se fecha com medição real na placa física | VNA na variante B; ajustar S11 da rede de casamento |
| 9 | **STEP sem corpos 3D** | Conferência visual 3D não mostra componentes | Instalar `kicad-packages3d` (o export STEP funciona, mas só com cobre/board/pads) |
| 10 | **Firmware menor** | Qualidade/compatibilidade | `StaticJsonDocument` deprecated (usar `JsonDocument`); `APP_ERROR_CHECK` faltantes em `app_timer_create/start` |

---

# 5. Próxima sessão (checklist ordenado por prioridade)

1. **Acabamento manual dos layouts no GUI KiCad 10** — variante B: re-placement dos passivos + 13 rotas + 9 stitches GND; variante A: rerotear os 11 copper_edge_clearance (ou aceitar os físicos); gateway: afastar vias de stitch dos PTHs (13 warnings hole_to_hole).
2. **Decisão física Ø32 da variante A** — cápsula maior / módulo menor / overhang (pads fora do disco hoje).
3. **Footprints**: conferir/corrigir Keystone 1059 (drawing oficial) + trocar soquete do gateway para `ESP32-DevKitC-32E_Carrier` (27,94 mm).
4. **Toolchain nRF** — instalar `arm-none-eabi-gcc` + SDK 17 + Makefile/sdk_config; corrigir `sd_ble_gap_adv_set_configure`; integrar `main.c` a projeto real (pca10040e/blank + S112).
5. **Pedidos de fabricação (JLCPCB/PCBWay)** — só após DRC 0 violações error nas 3 placas; incluir cotação formal.
6. **Bancada** — VNA para tuning RF da variante B; confirmar DC/DC do E73 com suporte Ebyte; consulta ANATEL.

---

# 6. Como verificar tudo

**Artefatos por placa** (padrão: `hardware/kicad/<placa>/`):

- Esquemático: `<placa>.kicad_sch` + `<placa>.kicad_pro`; exports em `exports/`: `<placa>.net` (netlist), `<placa>.pdf` (esquemático), `erc_report.json`, `<placa>_layout.pdf`, `<placa>_layout.step`, `drc_<placa>.json`, `drc_tracks_<placa>.json`, `audit.md` (auditoria independente).
- Boards: `wristband_discreto.kicad_pcb`, `wristband_modulo.kicad_pcb`, `gateway_esp32.kicad_pcb` (autocontidos — footprints embutidos; abrem direto no GUI KiCad 10).

**Comandos de re-verificação (KiCad 10.0.6):**

```bash
# ERC do esquemático
kicad-cli sch erc --format json --severity-all \
  -o <placa>/exports/erc_recheck.json <placa>/<placa>.kicad_sch

# Netlist
kicad-cli sch export netlist -o <placa>/exports/<placa>.net <placa>/<placa>.kicad_sch

# DRC do layout (0 violações error = alvo)
kicad-cli pcb drc <placa>/<placa>.kicad_pcb --schematic-parity --refill-zones \
  --severity-error --format json --output <placa>/exports/drc_<placa>.json
kicad-cli pcb drc <placa>/<placa>.kicad_pcb --all-track-errors \
  --format json --output <placa>/exports/drc_tracks_<placa>.json

# Exports
kicad-cli pcb export pdf --layers F.Cu,B.Cu,Edge.Cuts,F.SilkS,B.SilkS,F.Mask,B.Mask \
  --output <placa>/exports/<placa>_layout.pdf <placa>/<placa>.kicad_pcb
kicad-cli pcb export step --output <placa>/exports/<placa>_layout.step <placa>/<placa>.kicad_pcb
```

**Regenerar boards do zero (idempotente):**

```bash
python3 hardware/kicad/wristband_discreto/gen_board_v2.py
python3 hardware/kicad/wristband_modulo/gen_board_modulo.py
python3 hardware/kicad/gateway_esp32/gen_board_gateway.py
python3 hardware/kicad/tools/board_builder.py --selftest   # sanity da API pcbnew
```

**Documentação de referência** (`hardware/kicad/docs/`): `designator_map.md` (ground truth de designators/pinos), `kicad10_recipe.md` (receita de geração de esquemáticos), `layout_approach.md` (API pcbnew + comandos validados), `layout_status.md` (estado dos layouts), `pesquisa_modulo_ble.md`, `pesquisa_gateway_esp32.md`, `datasheet_facts_nordic.md`, `verificacao_matematica.md`, `crosscheck_varianteB.md`, `crosscheck_varianteA_gateway.md`.

**Firmware:** `firmware/main.c` (nRF52810/S112 — esqueleto de referência), `gateway_esp32/gateway_esp32.ino` (compila com arduino-cli + core esp32, huge_app).

---

*Relatório gerado em 2026-09-09 a partir dos artefatos commitados em `hardware/kicad/docs/`, `exports/audit.md` ×3, `.bob/plans/*.md`, código de firmware e histórico git.*

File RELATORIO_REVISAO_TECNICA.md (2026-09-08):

# Smart Badge Pub — Revisão Técnica e Especificação Corrigida (v2)

Revisão feita cruzando o documento original com a documentação oficial Nordic Semiconductor
(nRF52810 Product Specification, pin assignments QFN32 e Reference Circuitry — consultados
diretamente em docs.nordicsemi.com nesta revisão).

## 1. Veredito rápido

O conceito (NFC passivo para comanda + BLE para localização, servidor local) é sólido e é
exatamente como produtos comerciais reais deste tipo funcionam (ex.: pulseiras de festival com
RFID + beacons BLE de mesa). **O problema não é a ideia, é a implementação em 24 mm de diâmetro**
e alguns erros de datasheet que impediriam o circuito de funcionar como desenhado. Nenhum é
inviabilizante do projeto — todos têm correção conhecida — mas nenhum pode ser ignorado.

## 2. Erros críticos encontrados (verificados no datasheet Nordic)

### 2.1 Pinagem do nRF52810 QFN32 está incorreta
O documento original usa números de pino que não existem no encapsulamento QFN32 real (ex.: cita
VDD nos pinos 13/32, DEC1 no pino 31, cristal nos pinos 2/3, ANT no pino 27). A pinagem real do
**QFN32 (variante QCAA)**, confirmada na documentação oficial, é:

| Sinal | Pino real QFN32 | Observação |
|---|---|---|
| DEC1 | 1 | Desacoplo regulador 0.9V digital |
| VDD | 9, 25, 32 | 3 pinos de alimentação, todos devem ser decoupled |
| SWDCLK | 17 | |
| SWDIO | 18 | |
| ANT | 19 | Saída RF single-ended |
| VSS (rádio) | 20 | |
| **DEC2** | **21** | **Desacoplo regulador 1.3V do rádio — pino obrigatório, omitido no doc original** |
| **DEC3** | **22** | **Desacoplo de alimentação — pino obrigatório, omitido no doc original** |
| XC1 / XC2 | 23 / 24 | Cristal 32 MHz (não pino 2/3) |
| VSS | 29 | |
| DEC4 | 30 | Entrada do DC/DC, saída do LDO 1.3V |
| DCC | 31 | Saída do regulador DC/DC |
| Die pad (exposto) | — | VSS, deve ir para o plano de terra com múltiplas vias |

**Impacto se não corrigido:** com DEC2/DEC3 flutuando ou mal decoupled, o rádio 2.4 GHz não
atende as especificações de potência/sensibilidade do datasheet — na prática, alcance BLE
reduzido, instabilidade, ou falha de certificação. Isso teria passado despercebido até os
primeiros testes de bancada.

### 2.2 Rede de casamento de RF — valores corretos, mas peça errada
Os valores de L1/L2/L3 do documento original (10 µH, 15 nH, 3.9 nH) **batem** com o circuito de
referência oficial da Nordic para QFN32 com DC/DC (o que sugere que a fonte usada era legítima,
só foi mal transcrita). Porém:
- O capacitor C7 do doc original ("1.0 pF de casamento") não existe como peça única — o circuito
  de referência usa **dois** capacitores na malha Π: C3 = 0.8 pF e C7 = 100 pF, em posições
  diferentes da rede.
- Essa malha é calibrada para o **layout de referência da Nordic**, não para a antena chip
  Johanson 2450AT18A100 num plano de terra circular de 24–32 mm. **Só serve como ponto de
  partida.** Fabricação turnkey não inclui ajuste de RF — isso é feito em bancada com VNA
  (analisador de rede) medindo S11 e trocando indutores/capacitores até casar em 2.4 GHz. Prever
  isso no cronograma (normalmente 1–3 rodadas de PCB).

### 2.3 NFC + bateria moeda metálica no mesmo disco de 24–28 mm — conflito físico
Uma CR2032 já tem 20 mm de diâmetro. O suporte metálico (Keystone 1059) ocupa área equivalente.
Uma antena de bobina NFC precisa de uma área livre de metal por baixo/dentro do laço para
acoplar com o leitor (ISO 14443 a 13.56 MHz). Colocar o suporte metálico da bateria dentro (ou
sobreposto) à bobina NFC causa correntes de Foucault na peça metálica, que:
- reduzem o Q da bobina e desalinham a frequência de ressonância de 13.56 MHz;
- na prática, isso reduz alcance de leitura de ~3–5 cm para próximo de zero (tag "morta").

Isso não estava endereçado no documento original — era um problema de dia-1 de bancada.
**Correção:** blindagem com folha de ferrite (mesma técnica usada atrás de baterias em NFC de
celular), bobina fora da área ocupada pela bateria, ou — mais simples e barato — comprar o
NTAG213 já pronto como **inlay adesivo com antena própria** (não como die nu) dimensionado para
ficar na borda do disco, com a bateria posicionada no centro/verso protegido por blindagem.

### 2.4 Homologação ANATEL (não mencionada no documento original)
Qualquer equipamento que transmita rádio frequência para uso/comercialização no Brasil precisa de
homologação ANATEL (Lei 9.472/1997 e resoluções correlatas) — isso vale tanto para BLE quanto
para NFC ativo. Homologar um design próprio de RF do zero é caro e lento para um produto de
pequena/média escala. **Recomendação:** usar um **módulo BLE certificado** (que já embute o
SoC Nordic + antena + casamento de RF pré-validado, ex. linhas Fanstel, Raytac, u-blox
baseadas no nRF528xx) — isso reduz o processo de homologação para "homologação por
módulo/derivada", muito mais simples e barato do que homologar uma antena chip discreta.
**Verificar homologação vigente do módulo escolhido na Consulta de Produtos Homologados da
ANATEL antes de fechar o BOM.**

### 2.5 Torneira de self-pour: falta o subsistema de controle de fluxo
O documento resolve "abrir/autorizar" a torneira via NFC, mas não especifica **quem corta o
fluxo de chope**: isso exige válvula solenoide + medidor de vazão (flow meter de pulso, tipo
turbina hall) por torneira, com sua própria placa controladora (relé/MOSFET de potência,
alimentação 12–24V para a válvula) e lógica de "descontar do saldo enquanto verte". Isso é um
subsistema físico separado e não trivial — não pode ser tratado como "detalhe do backend".
Está fora do escopo elétrico da pulseira, mas precisa entrar no orçamento e cronograma do
projeto como um segundo hardware (placa por torneira).

## 3. Decisões de projeto (v2 — realista e fabricável)

| Item | Decisão |
|---|---|
| Forma/tamanho | Disco de **Ø32 mm** (comparável a uma Apple AirTag, 31.9 mm — não menor, fisicamente não dá para ser menor com bateria moeda + 2 antenas) |
| Rádio | **Módulo BLE certificado** com nRF52810/52832 embutido (elimina ajuste de RF em bancada e simplifica homologação ANATEL) |
| NFC | NTAG213 como **inlay pronto** (antena + chip), diâmetro ~25 mm, anel na borda do disco |
| Bateria | CR2032 no verso, com **disco de ferrite** entre bateria e bobina NFC |
| Empilhamento (stack-up) | PCB 2 camadas, FR4, 0.8 mm, acabamento **ENIG** (contato de bateria e solda confiáveis) |
| Vedação | Anel O-ring + cápsula usinada/SLA, IP67 — mantém-se do doc original, está correto |
| Firmware | nRF5 SDK (S112 SoftDevice) — mais leve que Zephyr para um único produto (beacon), controle direto do DCDC |
| Backend | Mosquitto (MQTT) + servidor local Python (FastAPI) + SQLite/Postgres — mantém-se do doc original |
| Gateways | ESP32, scan BLE passivo, filtro EWMA de RSSI, publica via MQTT |
| Torneira self-pour | **Fora do escopo desta placa** — subsistema à parte (válvula + flow meter), a especificar em projeto dedicado |

## 4. Matemática de engenharia

### 4.1 Autonomia de bateria (CR2032)
Ciclo: acorda a cada T = 1500 ms, ativo por t_a = 3 ms (TX + processamento em 3 canais de
advertising), dorme o resto do tempo.

- Corrente ativa (TX 0 dBm + CPU): I_a ≈ 5 mA
- Corrente em sono (System ON, RTC ativo): I_s ≈ 1.5 µA
- Duty cycle: D = t_a / T = 3/1500 = 0.2%
- Corrente média: I_avg = D·I_a + (1-D)·I_s ≈ 0.002×5000 µA + 0.998×1.5 µA ≈ **11.5 µA**
- Capacidade útil CR2032 (com margem de queda de tensão sob pulso e autodescarga): ~180–200 mAh
  úteis (nominal 220 mAh, deratado)
- Autonomia = 190.000 µAh / 11.5 µA ≈ **16.500 h ≈ 1,9 anos**

Conclusão: a meta de "6 a 12 meses" do documento original é **conservadora e alcançável** — dá
margem inclusive para aumentar a frequência de advertising (ex. 1s) sem comprometer a meta.

### 4.2 Link budget BLE (a rádio-frequência não é o gargalo)
Perda de espaço livre: FSPL(dB) = 20·log10(d) + 20·log10(f_MHz) − 27.55

Para d = 10 m, f = 2400 MHz → FSPL ≈ 60 dB. Em ambiente interno cluttered, adicionar 15–25 dB de
margem (paredes, corpos, refletores metálicos do balcão). Com TX em 0 dBm e sensibilidade do
nRF52810 de aprox. −96 dBm (PHY 1M), sobra **> 10 dB de margem** mesmo no pior caso — ou seja,
o alcance de conexão não é o problema real.

### 4.3 Por que a localização por RSSI é o elo fraco (e como mitigar)
Modelo log-distância: RSSI(d) = RSSI(d0) − 10·n·log10(d/d0) + X_σ

Em pub cheio, o expoente de perda n fica entre 2.5 e 4 (multipercurso + absorção por corpos —
o corpo humano sozinho atenua 10–20 dB em 2.4 GHz). Um erro de apenas ±6 dB na leitura de RSSI
já gera ±58% de erro na distância estimada (com n=3). **Trilateração (x,y) não é realista** com
uma única antena onidirecional por gateway. Recomendação prática, factível com o hardware
proposto:
- Tratar como problema de **classificação de zona** (mesa/grupo de mesas mais próximo), não de
  posição cartesiana — o algoritmo de "vizinho mais próximo com histerese" do doc original já
  está no caminho certo, é a abordagem certa para esse hardware;
- Suavizar leitura com EWMA (ver 4.4) antes de comparar entre gateways;
- Se no futuro for necessário sub-metro de precisão, migrar para nRF52811/nRF5340 com suporte a
  **Direction Finding (AoA)** — fora do escopo do nRF52810.

### 4.4 Filtro de suavização de RSSI (implementado no gateway)
EWMA (média móvel exponencial), simples e barata em CPU (roda tranquilo no ESP32):

RSSI_filt[n] = α·RSSI_raw[n] + (1−α)·RSSI_filt[n−1], com α ≈ 0.15–0.25

Ver implementação real em `gateway_esp32/gateway_esp32.ino`.

### 4.5 Por que a bateria detona o NFC (intuição física)
Acoplamento NFC depende do fator k = M/√(L1·L2) entre a bobina do leitor e a bobina da tag. Uma
peça metálica maciça (suporte da bateria) dentro do campo magnético da bobina se comporta como
uma "espira em curto": por Lenz, ela induz uma corrente que **se opõe** ao campo, derrubando a
indutância efetiva e o Q da bobina, e desloca a frequência de ressonância para longe de
13.56 MHz. Na prática: alcance de leitura cai de ~3–5 cm para ~0. É por isso que celulares e
cartões contactless sempre mantêm a bateria/chip fora do "miolo" da bobina, ou usam uma folha de
ferrite entre os dois.

## 5. O que este pacote entrega vs. o que ainda depende de bancada/humano

**Entregue neste pacote:** BOM corrigida, tabela de conexões (pino a pino, pronta para digitar
no KiCad), firmware da pulseira (esqueleto nRF5 SDK), firmware do gateway ESP32 (completo,
compilável), backend de localização (completo, executável), adaptador de integração com o
sistema de caixa.

**Não é possível/responsável entregar às cegas, sem ferramenta de EDA gráfica e bancada de RF:**
- Arquivo `.kicad_pcb` com roteamento final — layout de RF exige olho humano e, idealmente, o
  layout de referência do fabricante do módulo BLE escolhido (eles fornecem o desenho da área de
  antena pronto, é só copiar).
- Ajuste fino da rede de casamento de antena — depende de medição com VNA na placa física.
- Processo de homologação ANATEL — depende do módulo final escolhido e de laboratório
  credenciado.

Esses três pontos são normais em qualquer projeto de RF real; nenhum fabricante (JLCPCB, PCBWay,
Seeed) os resolve por você — eles fabricam o que você desenhar.

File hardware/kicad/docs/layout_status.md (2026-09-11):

# Status dos layouts PCB — KiCad 10.0.6

**Data:** 2026-09-09 · **Fontes:** `exports/audit.md` das 3 placas, JSONs de DRC commitados (`drc_*.json`, `drc_tracks_*.json`), geradores (`gen_board_v2.py`, `gen_board_modulo.py`, `gen_board_gateway.py`), `docs/layout_approach.md`.

---

## 1. Decisão de abordagem

**Script Python via API `pcbnew` (primário), com `tools/board_builder.py` como módulo compartilhado.** O fallback textual (`.kicad_pcb` escrito à mão) também foi provado no spike (`_spike/minimal_textual_filled.kicad_pcb`, DRC 0 violações), mas o caminho primário elimina o risco de rejeição do parser e garante integridade geométrica (coords em nm pela API). Regra do ambiente: **nunca** invocar o binário `kicad` (GUI) para gerar — só `kicad-cli` e `python3 + pcbnew`.

Comandos `kicad-cli` validados no 10.0.6 (detalhes em `layout_approach.md` §4):

- `kicad-cli pcb drc <board>.kicad_pcb --schematic-parity --refill-zones --severity-error --format json --output <out>.json` (com `--save-board` quando se quer gravar o refill)
- `kicad-cli pcb drc <board>.kicad_pcb --all-track-errors --format json --output <out>.json`
- `kicad-cli pcb export pdf --layers F.Cu,B.Cu,Edge.Cuts,F.SilkS,B.SilkS,F.Mask,B.Mask --output <out>.pdf <board>.kicad_pcb`
- `kicad-cli pcb export step --output <out>.step <board>.kicad_pcb`

**Correção ao comando do plano:** no KiCad 10, `kicad-cli pcb export pdf` **exige** `--layers` — sem ele falha com exit 1 ("Pelo menos uma camada deve ser definida"). A forma aprovada é a do bloco acima.

**Bug corrigido nos geradores (Edge.Cuts):** `SetCenter()` sozinho no círculo de borda deixa o ponto `end` em (16,0) absoluto e o raio vira ~130,6 mm em vez de 16 mm (detectado na auditoria da variante B). Correção: `SetCenter` + `SetEnd(CENTER+16,0)` na mesma escala (`bb._nm`) — padrão portado do `gen_board_modulo.py` para o `gen_board_v2.py`. As 3 placas ativas hoje têm Edge.Cuts verificado (raio 16,000 / retângulo 60×32 exatos).

---

## 2. Estado por placa

| Item | **Discreta** (Variante B, nRF52810 QFN32) | **Módulo** (Variante A, E73-2G4M04S) | **Gateway** (carrier DevKitC-32E) |
|---|---|---|---|
| Edge.Cuts | ✅ círculo r=16,000 em (100,100) | ✅ círculo r=16,000 em (100,100) | ✅ retângulo 60,00×32,00 em (100,100) |
| DRC error (`--severity-error`) | **27** | **26** | **0** |
| Composição dos errors | 12 courtyards_overlap (7 envolvem BT1 — footprint Keystone 1059 com dims UNVERIFIED; 5 outros pares: ANT1×C3, C10×C6, C8×X1, L2×L3, L2×U1) · 8 copper_edge_clearance (pads/trilhas na borda) · 6 clearance · 1 solder_mask_bridge | 11 copper_edge_clearance (10 pads físicos do E73 na periferia + 1 resíduo ~0,02 mm no stub VDD_BAT→U1.16) · 6 clearance · 5 courtyards_overlap (BT1×U1 — física do Ø32) · 4 solder_mask_bridge | — |
| Unconnected | **22** | **0** | **0** |
| — rotas de sinal pendentes | **7** (com 4L, GND e VDD_BAT saíram dos corredores F.Cu/B.Cu — ver §4a) | 0 | 0 |
| — GND sem stitch livre | **9** (pads GND em F.Cu sem via para a zona B.Cu; gerador registra 8 pads sem direção livre: C2.2/C4.2/C5.2/C6.2/C7.2/C8.2/U1.20/U1.29) | 0 (punch list fechada: C1.2/C2.2 com via de costura) | 0 |
| Parity (`--schematic-parity`) | 0 | 0 | 0 |
| Curtos | 0 (0 `shorting_items` no estado atual) | 0 | 0 |
| Warnings (all-track-errors) | 54 warning (silk sobre cobre/sobreposição, texto, 2 track_dangling) — não bloqueiam | 36 warning (silk/texto, 1 padstack) — não bloqueiam | **0** (fechado: os 13 warning de furo — 12× `hole_to_hole` + 1× `holes_co_located` — foram eliminados ao afastar as vias GND de stitch dos PTHs; offset inicial 1,6 mm validado furo-a-furo ≥0,6 mm contra todos os PTHs) |
| Veredito da auditoria | REPROVADO (estado da auditoria; desde então o Edge.Cuts foi corrigido e o board regenerado — ver JSONs atuais) | REPROVADO → punch list FECHADA (restam só os 11 errors de física documentada) | APROVADO COM PENDÊNCIAS |

Nota de rastreabilidade: a auditoria da Discreta registrou 284 errors no board com o bug de raio (83 curtos reais de VDD_BAT, 116 mask, 71 clearance, J1 não flipado). O board atual (regenerado em `gen_run_4`, 18:21) tem 27 errors / 22 unconnected / 0 curtos — os JSONs commitados refletem o board atual (verificado por re-execução DRC nas auditorias).

---

## 3. Keepouts de antena (valor + fonte)

| Placa | Keepout (frame do board) | Fonte |
|---|---|---|
| Discreta | x∈[8,14], y∈[8,14] mm rel. ao centro (canto NE do disco) — ~3 mm de margem da antena chip Johanson | Regra do gerador `gen_board_v2.py` (`rf_nets` isentos: NET_RF/NET_ANT + GND de retorno C3/ANT1). **Observação:** a regra vive só no gerador — não há zona keepout nativa no board; um edit manual no KiCad não seria bloqueado |
| Módulo | x∈[-15,5,-8,85], y∈[-9,9] mm rel. ao centro (extremidade oeste) | NOTA 4 do esquemático (y_local < -8,85 do footprint E73), rotacionada 90° — mapeamento verificado pelos pads reais (U1.16/U1.37). **Keepout nativo do footprint E73 confirmado no pour:** varredura de cobre na faixa = 0 cobre (zona keepout F.Cu+B.Cu presente no board; zona desenhada ~1,15 mm mais estreita a oeste que o retângulo da NOTA 4 — cobre real respeita o retângulo completo) |
| Gateway | x∈[124,130], y∈[84,116] (extremidade leste, antena PCB do DevKitC) | NOTA do gerador `gen_board_gateway.py`; isenção de 1,0 mm para pads do próprio U1 (J2-19/J3-19 em x≈122,86). Verificado: 0 cobre de rota na faixa, ambas as camadas |

---

## 4. Pendências honestas (e o que é preciso para resolver)

### a) Discreta — 7 rotas de sinal pendentes + courtyards BT1
Após a migração para 4 camadas (§6), GND e VDD_BAT saíram dos corredores F.Cu/B.Cu para planos internos, liberando espaço para o A* router. As 7 rotas restantes (NET_XC2, NET_DCC, NET_DEC4, NET_DEC3, NET_SWDCLK, NET_SWDIO, NET_RESET) ainda dependem de **re-placement dos passivos** (afastar caps de decoupling/cristal do muro de pads do U1) e regenerar, **ou** acabamento manual no GUI KiCad 10 com o roteador interativo. Os 9 GND sem stitch precisam de vias em direções hoje bloqueadas — mesmo tratamento. Os 12 courtyards_overlap: conferir o drawing oficial da **Keystone 1059** (footprint custom `nibas_wristband:Keystone_1059_CR2032_SMT` está marcado **UNVERIFIED** no símbolo) antes de tratar como erro real de placement.

### b) Módulo — E73 não cabe no Ø32
Os pads U1.15/16/27/28 ficam a r=16,24–16,86 mm do centro — **fisicamente fora do disco Ø32** (módulo 17,5×28,7 mm + holder CR2032 15,24×30,48 mm não cabem lado a lado). É decisão de projeto, não de rota: (1) cápsula maior que Ø32; (2) módulo menor — verificar variante do E73 (ex. E73-2G4M04S é 17,5×28,7; checar se existe variante menor da família E73 que atenda); ou (3) aceitar overhang do módulo na borda. A sobreposição BT1×U1 (5 courtyards + 6 clearance + 4 mask) tem a mesma causa raiz. Os 11 `copper_edge_clearance` restantes são todos essa física documentada.

### c) Gateway — footprint do soquete errado + hole-to-hole
O U1 usa `PinHeader_2x19_P2.54mm_Vertical` com **2,54 mm entre fileiras**, mas o DevKitC-32E real tem as fileiras de header a **27,94 mm** (largura do módulo). O board atual NÃO encaixa o DevKitC físico. Antes de fabricar: trocar por footprint custom `ESP32-DevKitC-32E_Carrier` (27,94 mm entre fileiras, soquete fêmea 1x19) e regenerar placement/rotas. **PENDÊNCIA ATIVA:** o esquemático e a lib já apontam para a carrier (módulo 55×28), mas o board 60×32 não acomoda o módulo físico + J1/SW1/R1 sem sobreposição de courtyard — a migração exige redimensionar o board (decisão de projeto). O gerador (`gen_board_gateway.py`) fixa U1 no PinHeader_2x19 enquanto isso. Os 13 warnings `hole_to_hole`/`holes_co_located` **FECHADOS**: vias de stitch GND agora em offsets ≥1,6 mm do pad, validadas furo-a-furo (borda a borda ≥0,6 mm) contra todos os PTHs + clearance de cobre, com fallback de busca em grade até r 14,5 mm (DRC all-track-errors: 0 violações).

### d) Geral
- **Tuning RF em bancada com VNA** (variante B — antena chip Johanson): o layout garante a rota, mas o matching (L1/L2/C3) só se fecha com medição real.
- **Modelos 3D ausentes:** `kicad-packages3d` não instalado neste host (`/usr/share/kicad/3dmodels` vazio) — o STEP sai só com cobre/board/pads, sem corpos dos componentes. Instalar o pacote se a conferência visual (passo vision) exigir; o export não falha por isso.

---

## 5. Como abrir / continuar

- **Abrir no KiCad 10 GUI:** os `.kicad_pcb` são autocontidos (footprints embutidos no board — não dependem de fp-lib-table):
  - `hardware/kicad/wristband_discreto/wristband_discreto.kicad_pcb`
  - `hardware/kicad/wristband_modulo/wristband_modulo.kicad_pcb`
  - `hardware/kicad/gateway_esp32/gateway_esp32.kicad_pcb`
- **Regenerar do zero** (idempotente, cada gerador recria o board completo):
  - `python3 hardware/kicad/wristband_discreto/gen_board_v2.py`
  - `python3 hardware/kicad/wristband_modulo/gen_board_modulo.py`
  - `python3 hardware/kicad/gateway_esp32/gen_board_gateway.py`
- **Re-checar DRC:** comandos do §1 (JSONs vão para `exports/`).
- Regra do ambiente segue valendo: geração/validação por `kicad-cli` + `pcbnew`; o GUI KiCad 10 só para acabamento manual (roteador interativo da Discreta).

---

## 6. Migração 4 camadas (variante discreta)

A variante discreta foi migrada de 2 para 4 camadas (F.Cu/In1.Cu/In2.Cu/B.Cu)
para resolver o bloqueio de roteamento causado pelas autostradas de potência
(GND e VDD_BAT) nos corredores de sinal.

**Stackup:** F.Cu (sinal) / In1.Cu (plano GND) / In2.Cu (plano VDD_BAT) / B.Cu (sinal+GND)
**Espessura:** 0,8 mm
**Mudanças:** GND e VDD_BAT removidos do roteamento por trilha; vias blind F.Cu→In1/In2
conectam pads de potência aos planos internos. Sinais (RF, cristal, DEC, SWD, DCC, RESET)
roteados em F.Cu/B.Cu com mais espaço disponível.

**Status:** Script gen_board_v2.py atualizado para 4L; board_builder.py estendido com
suporte a camadas internas, planos e vias blind/buried.

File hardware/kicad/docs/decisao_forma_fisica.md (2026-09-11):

# Decisão de forma física — Variante A (pulseira, disco Ø32 mm)

**Data:** 2026-09-09
**Status:** Decidido
**Escopo:** Variante A (pulseira esportiva de silicone, cápsula IP67, disco Ø32 mm)

## Decisão

Substituir o módulo Ebyte E73-2G4M04S-52810 (17,5 × 28,7 mm) pelo **Fanstel BM832A**
(nRF52810, 10,2 × 15 × 1,9 mm, US$ 3,61) na variante A.

## Justificativa (com fontes)

### 1. Cápsula: não existe cápsula vazia IP67 redonda Ø34–38 mm no mercado

Não existe cápsula vazia IP67 redonda Ø34–38 mm no mercado. O que existe são
**beacons prontos** (não cápsulas vazias):

- Trax10214 — Ø35,9 mm (beacontrax.com)
- Minew B10 — Ø38 mm (minew.com)
- Minew E7 — Ø39 × 15,5 mm, IP67, rosca — menor cápsula **comprovada** que aceita
  pilha CR2477 (minew.com)

Aumentar a cápsula além de Ø32 mm exigiria **moldagem custom** (ferramental +
NRE), custo inviável para protótipo de 5 unidades. Fontes: beacontrax.com,
minew.com, takachi-enclosure.com.

### 2. Overhang castelado fora do círculo: NÃO viável

Regras oficiais de fabricação eliminam a opção de manter o E73 com os pads das
pontas em overhang (fora do arco do disco):

- JLCPCB e PCBWay exigem furo PTH bissecado pelo contorno da placa + pad com
  extensão ≥ 0,5 mm para dentro do contorno (links oficiais das regras de
  fabricação de ambos).
- Os pads das pontas do E73 ficariam fora do arco (sagitta ≈ 1,65 mm) — violam
  a regra de fabricação em ambas as casas.

### 3. Fanstel BM832A: encaixa, custa igual, zero migração de firmware

- **Mesmo SoC** nRF52810 → SoftDevice S112 funciona direto, **zero migração**.
- **Dimensões:** 10,2 × 15 mm → diagonal ≈ 18,2 mm, cabe folgado no Ø32 mm.
  (E73: diagonal ≈ 33,5 mm — não cabe.)
- **Preço:** paridade — US$ 3,61 vs US$ 3,59.
- **Alimentação:** VDD 1,7–3,6 V → CR2032 ok.
- **Antena integrada** + certificações FCC/CE/TELEC.
- **Indutores do DC/DC integrados ao módulo** ([página oficial Fanstel BM832A](https://www.fanstel.com/bm832a-bluetooth-5-module)) —
  **fecha o item aberto #2** do projeto.
- **ANATEL:** segue como item aberto (mesmo status do E73 — módulo BLE
  certificado, homologação a confirmar). Precisão de escopo: SOMENTE os
  radiadores intencionais precisam de homologação (módulos BM832A e ESP32,
  que emitem em 2,4 GHz); PCB, suporte de bateria, tag NFC passiva, ferrite
  e cápsula plástica NÃO certificam individualmente. Se os módulos já forem
  homologados pelo fabricante, o produto final usa processo simplificado
  aproveitando os laudos do módulo (confirmação com OCD permanece
  recomendada).

### 4. Alternativa registrada (não escolhida)

Manter o E73 e usar cápsula Ø39 custom (moldagem). Descartada: custo de
ferramental inviável para protótipo de 5 unidades.

### 5. Impacto no projeto

- Novo símbolo + footprint do BM832A (transcritos do datasheet Fanstel).
- Troca de U1 no `.kicad_sch` da variante A.
- Re-layout da placa.
- Keepout de antena do BM832A conforme manual Fanstel (antena estendida fora
  do ground plane — **verificar dimensões exatas no manual**).

### 6. Ressalva honesta

Diagonal caber no disco **não significa layout fechado**. O keepout de antena
do BM832A e a coexistência com BT1 (porta-pilha CR2032) e TAG1 (NTAG213)
precisam ser validados geometricamente no KiCad antes de considerar a placa
resolvida.

## Referências

- beacontrax.com — Trax10214 (Ø35,9 mm)
- minew.com — B10 (Ø38 mm), E7 (Ø39 × 15,5 mm, IP67, CR2477)
- takachi-enclosure.com — busca de cápsulas IP67
- JLCPCB — regras de fabricação (furo PTH bissecado + pad ≥ 0,5 mm)
- PCBWay — regras de fabricação (idem)
- Fanstel — [página oficial BM832A](https://www.fanstel.com/bm832a-bluetooth-5-module) (dimensões, preço, indutores DC/DC
  integrados, certificações)

## Adaptação AirTag (prototipagem)

Para validação mecânica rápida, a pulseira PCB Ø32 mm pode ser instalada em
shells de pulseira AirTag genéricos (Ø31.9 mm interno ≈ Ø32 mm externo da PCB).

**Especificação AirTag:** 31.9 mm diâmetro × 8.0 mm espessura, IP67, CR2032.
**Nosso stack-up estimado:** PCB 0,8 mm + bateria 3,2 mm + módulo BLE 1,5–2 mm +
inlay NFC 0,3 mm + ferrite 0,5 mm ≈ 6,3–7,0 mm (cabe na cavidade de 8,5 mm).

**Produtos identificados:**
- Silicone waterproof bracelet (Amazon B0C6B2N4WV): ~$8 USD / 2-pack
- Full-coverage silicone wristband (Amazon B0C4L1YPVR): ~$15 USD / 2-pack
- Nylon strap + TPU holder (Amazon B09DVTRM4F): ~$10 USD / 2-pack

**Vantagens:** RF-transparente (silicone não bloqueia BLE/NFC), fundo plano para
inlay NFC adesivo, custo baixo, supply chain existente.

**Recomendação:** Comprar 2–3 shells para teste de encaixe; se OK, encomendar
molde de silicone customizado para produção (MOQ ~100 un, ~$200–500 molde).

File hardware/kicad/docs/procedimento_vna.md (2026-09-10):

# Procedimento VNA — Tuning RF Variante B (bancada)

**Escopo:** variante B (`hardware/kicad/wristband_discreto/`) — nRF52810-QCAA.
**Data:** 2026-09-10 · **Revisão:** A.

## 1. Objetivo

Casar a saída ANT (pino 19 do U1) com a antena chip ANT1
Johanson 2450AT18A100 em 2,4 GHz, através da rede de 2 elementos
da referência Nordic (PS v1.3 Fig. 146):

- `NET_ANT` = {U1.19, C3.1, L1.1}
- C3 0,8 pF shunt → GND (C3.2 em GND)
- L1 3,9 nH série entre `NET_ANT` e `NET_RF`
- `NET_RF` = {L1.2, ANT1.1} (feed da antena)
- ANT1.2 → GND

O tuning corrige o deslocamento causado por FR-4 0,8 mm,
cápsula, bateria CR2032 e ferrite — não o valor nominal.

## 2. Equipamento e pré-condições

- VNA com faixa até 3 GHz ou mais (NanoVNA V2 aceito p/ triagem).
- Calibração SOLT (curto-aberto-carga) no plano de medição.
- Cabo semi-rígido curto + conector U.FL de teste no footprint,
  ou sonda RF com GND próximo ao feed.
- Kit de valores 0402 NP0 / alta-Q para C3 e L1 (ver §5).
- Placa de sacrifício com a antena montada + keep-out respeitado.
- Bateria e ferrite presentes (condição real de uso).

## 3. Pontos de teste

- Nó A: junção C3.1 / L1.1 / U1.19 (`NET_ANT`).
- Nó B: saída L1.2 / ANT1.1 (`NET_RF`, feed da antena).
- GND: pad ANT1.2 ou plano próximo ao feed.
- Medir S11 com a placa na posição final (dentro da cápsula
  se possível; mão e mesa afetam o resultado).

## 4. Leitura de S11

- Faixa de varredura: 2,0–3,0 GHz; marcador em 2400–2480 MHz.
- Alvo: mínimo de S11 (vale de ressonância) dentro de 2400–2480 MHz.
- Critério: VSWR < 2 (S11 < −9,5 dB) em toda a faixa BLE.
- Registrar também a carta de Smith: ponto deve estar
  próximo ao centro (50 Ω) em 2440 MHz.

## 5. Sequência de ajuste

1. Montar valores nominais: C3 = 0,8 pF, L1 = 3,9 nH.
2. Medir S11 de referência e anotar na tabela (§7).
3. Ajustar C3 primeiro (move a parte imaginária):
   tentar 0,5 / 0,8 / 1,0 / 1,2 pF, um valor por vez.
4. Fixar o melhor C3 e ajustar L1 (move a ressonância):
   tentar 2,7 / 3,3 / 3,9 / 4,7 nH.
5. Repetir uma rodada fina C3 ± 0,2 pF se o vale ainda
   estiver deslocado mais que 40 MHz.
6. Footprints 0402 de C3/L1 aceitam 0 Ω ou fio como
   bypass temporário só para diagnóstico — nunca como final.
7. Uma variável por vez; re-soldar com ponta fina e limpar
   fluxo antes de cada medida.

## 6. O que NÃO mexer

- Topologia é de 2 elementos (C3 + L1). Não adicionar C/L extra.
- L3 (15 nH) pertence ao ladder do DC/DC
  (DCC → L2 10 µH → L3 → DEC4 + C10) — fora do caminho RF.
- Não trocar ANT1 por outro modelo sem repetir todo o tuning.
- Não remover o keep-out da antena nem o plano GND sob o nRF.
- Não fechar comanda nem alterar firmware durante o tuning:
  medir com o rádio em TX contínuo ou placa desligada
  conforme o método do VNA (seguir o manual do equipamento).

## 7. Critério de aceite + registro

Aceite: S11 < −9,5 dB (VSWR < 2) de 2400 a 2480 MHz,
vale principal dentro da faixa, medida com bateria + ferrite.

| Tentativa | C3 (pF) | L1 (nH) | S11 @2440 (dB) | Freq. vale (MHz) | VSWR máx. 2400–2480 | OK? |
|---|---|---|---|---|---|---|
| 0 (nominal) | 0,8 | 3,9 | | | | |
| 1 | | | | | | |
| 2 | | | | | | |
| 3 | | | | | | |
| Final | | | | | | |

Anexar print da tela do VNA (S11 + Smith) da tentativa final
ao dossiê do protótipo.

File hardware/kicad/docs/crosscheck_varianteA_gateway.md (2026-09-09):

# Cross-check Variante A (módulo E73) + Gateway ESP32 — passo 5.3

**Data:** 2026-09-09 · **Verificador:** build (sessão fresh, ≠ autores de 4.2/4.3) · **Plano:** `.bob/plans/kicad-esquematicos-verificacao.md` [5.3]

**Entradas lidas (read-only):** `wristband_modulo.kicad_sch` + `exports/wristband_modulo.net` + `exports/erc_report.json` · `gateway_esp32.kicad_sch` + `exports/gateway_esp32.net` + `exports/erc_report.json` · `BOM_smartbadge_v2.csv` · `docs/pesquisa_modulo_ble.md` · `docs/pesquisa_gateway_esp32.md` · `docs/gateway_lib_status.md` · `docs/designator_map.md` · `docs/verificacao_matematica.md` (E2–E4) · `firmware/main.c` · `gateway_esp32/gateway_esp32.ino`.

**Fontes primárias RE-VERIFICADAS hoje (não herdadas de 2.1/2.2):**

| Fonte | URL | Uso |
|---|---|---|
| Página oficial Ebyte E73-2G4M04S1A — Pin Definition | https://www.cdebyte.com/products/E73-2G4M04S1A/2 | pinout pads 0–43 (acessada 2026-09-09) |
| **E73-2G4M04S1A User Manual rev 1.8 (2025-01-13)** — PDF oficial | https://www.cdebyte.com/pdf-down.aspx?id=3536 | pin definition + seção 4.1 "Hardware Design" |
| FAQ oficial do fabricante (loja Ebyte) — DC/DC | https://ebyteiot.com/products/ebyte-e73-2g4m04s1b-nrf52832-wireless-module-ble-4-2-iot-ble5-0-bluetooth-module-2-4ghz-wireless-transceiver-modules-soc | suporte a DC/DC no módulo (ver §3) |
| ESP32-DevKitC V4 User Guide — fonte RST oficial | https://github.com/espressif/esp-dev-kits → `docs/en/esp32-devkitc/user_guide.rst` (renderiza em docs.espressif.com) | tabelas J2/J3 + nota [2] dos pinos de flash |
| Adafruit Feather nRF52832 (MDBT42Q) — esquemático público | https://github.com/adafruit/Adafruit-nRF52-Bluefruit-Feather-PCB (`Adafruit nRF52 Bluefruit Feather.sch`) | contraprova: indutor DC/DC externo em módulo concorrente |

---

## 1. CROSS-CHECK VARIANTE A — `wristband_modulo`

### 1a. Netlist ↔ `BOM_smartbadge_v2.csv` — **OK**

BOM tem 11 itens; netlist tem 11 componentes — correspondência 1:1, bidirecional, sem órfão dos dois lados.

| Item BOM | Valor/footprint BOM | No netlist? | Valor/footprint no netlist | Veredito |
|---|---|---|---|---|
| U1 | BLE Module nRF52810/832, footprint per vendor, PN "a definir" | sim | `E73-2G4M04S-52810`, `RF_Module:E73-2G4M04S` | OK — PN resolvido pelo passo 2.1 (nRF52810, S112 direto); campo PN do BOM ficou stale ("a definir") — nota no §4 |
| TAG1 | NTAG213 Inlay, adesivo ~25 mm | sim | `NTAG213_Inlay`, `nibas_wristband:NTAG213_Inlay_25mm` | OK |
| SHLD1 | Ferrite Shielding Sheet, disco ~20–22 mm | sim | `Ferrite_Shield`, `nibas_wristband:SHLD1_Ferrite_Shield_22mm` | OK |
| BT1 | Coin Cell Holder CR2032, Keystone 1059 | sim | `Keystone_1059`, `nibas_wristband:Keystone_1059_CR2032_SMT` | OK |
| C1 | 10 µF, 0603 | sim | `10uF`, `Capacitor_SMD:C_0603_1608Metric` | OK |
| C2 | 100 nF, 0402 | sim | `100nF`, `Capacitor_SMD:C_0402_1005Metric` | OK |
| TP1 | Test Pad VDD, 1.0 mm | sim | `TestPad_VDD`, `TestPoint:TestPoint_Pad_D1.0mm` | OK |
| TP2 | Test Pad SWDIO, 1.0 mm | sim | `TestPad_SWDIO`, idem | OK |
| TP3 | Test Pad SWDCLK, 1.0 mm | sim | `TestPad_SWDCLK`, idem | OK |
| TP4 | Test Pad GND, 1.0 mm | sim | `TestPad_GND`, idem | OK |
| J1 | Battery clip contact (verso), SMT pad | sim | `Battery_Negative_Contact`, `nibas_wristband:J1_Battery_Negative_Contact` | OK |

Componentes no netlist que não estão no BOM: **nenhum** (11 = 11).

### 1b. Netlist ↔ pinout oficial E73-2G4M04S1A — **OK**

Pinout re-verificado hoje na página oficial (cdebyte.com/products/E73-2G4M04S1A/2) e no User Manual rev 1.8 (pdf-down id=3536): pad 33=P0.18, 36=P0.21/RST, 37=SWDCLK, 38=SWDIO, 40=P0.23, 41=P0.24, VCC=16 (1.8–3.6 V), GND=0/1/2/15/42/43. **A correção de 2026-09-09 da tabela §5 de `pesquisa_modulo_ble.md` está correta** — e agora também confirmada pelo manual rev 1.8 (cuja revisão "1.8 · 2025/01/13 · Modify the pin sequence number description" é exatamente essa correção de sequência).

| Rede (netlist) | Nós no netlist | Pad oficial Ebyte | Veredito |
|---|---|---|---|
| `/VDD_BAT` (code 3) | BT1.1 + C1.1 + C2.1 + TP1.1 + **U1.16 (VCC)** | 16 = VCC, "Power supply 1.8~3.6 V DC" | OK |
| `/NET_SWDCLK` (code 1) | TP3.1 + **U1.37** | 37 = SWDCLK (Input) | OK |
| `/NET_SWDIO` (code 2) | TP2.1 + **U1.38** | 38 = SWDIO | OK |
| `GND` (code 4) | C1.2 + C2.2 + J1.1 + SHLD1.1 + TP4.1 + **U1.0/1/2/15/42/43** | 0,1,2,15,42,43 = GND | OK — todos os 6 pads de terra conectados |
| nRESET | U1.36 = **NC explícito** | 36 = P0.21 (Input/Output/RST) | OK c/ nota — decisão registrada (`designator_map.md` linha 27: R1 não incluído na variante A; função RESET tem pull-up interno no nRF52 via UICR PSELRESET; NC inofensivo também com chip virgem) |
| DEC1(14)/DEC2(3)/DEC3(4)/DEC4(12)/DCC(13) | **NC explícito** | pads expostos | ver seção 3 (veredito DC/DC) |
| GPIOs P0.02–P0.31 (pads 5–11, 17–35, 39–41) | NC explícito (35 pins com flag `no_connect`) | GPIO livres | OK — firmware não usa GPIO; contagem confere: 44 pads − 9 conectados (6 GND + VCC + SWDCLK + SWDIO) = 35 NC |
| Antena | nenhuma rede externa | PCB trace integrada + keep-out no footprint | OK — coerente com NOTA 4 do esquemático |

TAG1 (ANT1/ANT2) NC: OK — inlay NFC é adesivo autônomo (chip+antena internos); pads são representação para BOM/posição (mesma conclusão do 5.1, Extra E3).

### 1c. ERC `wristband_modulo` — **OK (0 violações)**

`exports/erc_report.json`: `"violations": []` com severidades error+warning+exclusion incluídas. KiCad 10.0.6, data 2026-09-09T09:06:45 (mesma timestamp da netlist — relatório não está stale).

Checks ignorados no nível global (5) — justificativa um a um:

| Check ignorado | Justificativa | Aceito? |
|---|---|---|
| `pin_not_driven` | Necessário: U1.37 (SWDCLK, tipo input) é dirigido por TP3 (passive), que o ERC não conta como driver → falso-positivo garantido. `/VDD_BAT` também não tem símbolo de power (só passives + power_in) — ver observação O3. | Sim |
| `single_global_label` | Esquema não usa global labels (nets por labels locais) — preventivo. | Sim |
| `four_way_junction` | Estilo de desenho (junções de 4 fios) — preventivo. | Sim |
| `footprint_link_issues` | Preventivo; todos os 11 componentes têm footprint atribuído no netlist. | Sim |
| `footprint_filter` | Preventivo; conferência manual: todos os footprints casam com os filtros dos símbolos (ex.: `TestPoint_Pad_D1.0mm` ↔ `Pin* Test*`; `E73-2G4M04S` ↔ `E73*2G4M04S*`). | Sim |

### 1d. Decoupling VDD_BAT (C1 10 µF + C2 100 nF) — **OK**

Netlist: C1.1 e C2.1 em `/VDD_BAT`; C1.2 e C2.2 em `GND`. Valores/footprints batem com o BOM (C1=10 µF 0603, C2=100 nF 0402). Atende também a exigência do FAQ Ebyte de "decoupling capacitance suficiente" para os transientes do DC/DC (ver §3).

---

## 2. CROSS-CHECK GATEWAY — `gateway_esp32`

### 2a. Netlist ↔ pinout oficial ESP32-DevKitC V4 — **OK (38/38 pinos)**

Conferência pino-a-pino do símbolo `nibas_gateway:ESP32-DevKitC-32E` (via libpart do netlist) contra as tabelas J2/J3 do User Guide oficial (RST fonte `docs/en/esp32-devkitc/user_guide.rst` do repo `espressif/esp-dev-kits`). **Os 38 pinos batem 1:1 em nome e posição**, incluindo os mandatórios desta tarefa:

| Pino | User Guide oficial | Netlist/símbolo | Conexão no esquema | Veredito |
|---|---|---|---|---|
| J2-19 | 5V (P) | `5V_J2-19` (power_in) | `+5V` ← J1.1 (entrada 5 V) | OK |
| J2-1 | 3V3 (P) | `3V3_J2-1` (power_out) | `+3V3` → R1.1 | OK |
| J2-2 | EN (I, CHIP_PU/Reset) | `EN_J2-2` (input) | `/EN` (R1.2 + SW1.1) | OK |
| J2-14 | GND (G) | `GND_J2-14` | `GND` | OK |
| J3-1 | GND (G) | `GND_J3-1` | `GND` | OK |
| J3-7 | GND (G) | `GND_J3-7` | `GND` | OK |

Demais 32 pinos (VP, VN, IO34/35/32/33/25/26/27/14/12/13, IO23/22/TX/RX/21/19/18/5/17/16/4/0/2/15): todos NC explícito — coerente com firmware sem GPIO (`gateway_esp32.ino` não toca nenhum pino; só BLE scan + WiFi/MQTT). Strapping (IO0/IO2/IO12/IO15) resolvido no próprio DevKitC — nota de texto no esquemático documenta isso.

### 2b. Circuito de EN — **OK**

Netlist `/EN` (code 3): R1.2 + SW1.1 + U1.J2-2; R1.1 em `+3V3` (J2-1); SW1.2 em `GND`. R1 = 10 kΩ 0603. Ou seja: **pull-up 10 k→3V3 + botão NA→GND, ambos presentes**. Notas: (i) o DevKitC já tem RC 10k/1µF + botão EN onboard — R1 externo fica em paralelo com o pull-up onboard (5 k efetivo, inofensivo) e SW1 replica o botão EN do DevKit, que fica inacessível quando o DevKit está em soquete — justificativa explícita na descrição do símbolo SW1; (ii) sem capacitor externo no EN da carrier — correto, o RC já existe no DevKit (adicionar outro C em paralelo alteraria o RC de reset).

### 2c. Pinos de flash D0–D3/CMD/CLK — **OK (todos NC)**

User Guide oficial, nota [2]: *"The pins D0, D1, D2, D3, CMD and CLK are used internally for communication between ESP32 and SPI flash memory... Avoid using these pins."*

| Pino | GPIO | No netlist |
|---|---|---|
| J3-18 (D0) | GPIO7 | `unconnected-(U1-D0-PadJ3-18)` ✓ |
| J3-17 (D1) | GPIO8 | `unconnected-(U1-D1-PadJ3-17)` ✓ |
| J2-16 (D2) | GPIO9 | `unconnected-(U1-D2-PadJ2-16)` ✓ |
| J2-17 (D3) | GPIO10 | `unconnected-(U1-D3-PadJ2-17)` ✓ |
| J2-18 (CMD) | GPIO11 | `unconnected-(U1-CMD-PadJ2-18)` ✓ |
| J3-19 (CLK) | GPIO6 | `unconnected-(U1-CLK-PadJ3-19)` ✓ |

Nenhuma conexão nos 6 pinos; nota de texto no esquemático (`gateway_esp32.kicad_sch`, linha ~616) documenta a regra.

### 2d. ERC `gateway_esp32` — **OK (0 violações)**

`exports/erc_report.json`: `"violations": []` (error+warning+exclusion incluídos), mesma timestamp da netlist. Ignores globais (4): `single_global_label` (sem global labels — preventivo), `four_way_junction` (estilo), `simulation_model_issue` (símbolos custom sem modelo SPICE; projeto não simula), `footprint_filter` (símbolos custom `nibas_gateway` sem filtros definidos) — todos justificados.

---

## 3. CHECK DC/DC NO MÓDULO E73 × FIRMWARE — **OK (condicional, com fonte)**

**Firmware:** `firmware/main.c:52` — `sd_power_dcdc_mode_set(NRF_POWER_DCDC_ENABLE);` (SoftDevice S112, chamada em runtime no boot; comentário da linha 51 remete a L2/C10 que só existem na variante B). Não há `sdk_config.h` no repo (o `main.c` é esqueleto de referência) — a chamada runtime é a evidência definitiva de que o firmware liga DC/DC.

**O módulo expõe pads DCC (13) e DEC4 (12)?** Sim — mas isso não implica componente externo: o datasheet E73 afirma "All IO ports are led out" (o módulo expõe TODOS os pinos do chip nRF52810, incluindo DEC1–4/DCC, como pontos de acesso/prova).

**Evidência coletada hoje:**

| # | Evidência | Fonte |
|---|---|---|
| E-1 | FAQ oficial do fabricante: *"Q: Can the E73-2G4M04S1B operate using the internal DC-DC converter of the nRF52832? A: **Yes, the module hardware supports the nRF52832's internal DC-DC regulator mode.** When enabled via software, this significantly improves power efficiency... To ensure stability, the supply voltage must remain within the 1.8V to 3.6V range with sufficient decoupling capacitance..."* — sem MENÇÃO a indutor/capacitor externo em DCC/DEC4 | https://ebyteiot.com/products/ebyte-e73-2g4m04s1b-nrf52832-wireless-module-ble-4-2-iot-ble5-0-bluetooth-module-2-4ghz-wireless-transceiver-modules-soc (JSON-LD da página, verbatim) |
| E-2 | **User Manual oficial do E73-2G4M04S1A rev 1.8 (2025-01-13)**, seção 4.1 "Hardware Design": instruções apenas de qualidade de alimentação, GND, layout e antena — **nenhum componente externo exigido** (nem caps DEC, nem indutor); o manual não tem circuito de aplicação típica e remete ao PS Nordic para detalhes do chip | https://www.cdebyte.com/pdf-down.aspx?id=3536 |
| E-3 | Placa de teste oficial Ebyte (E73-TBA/TBB, manual id=2520): alimentação = USB 5 V → fusível → LDO ME6211 → 3,3 V direto no módulo; sem indutor/caps DEC descritos no circuito de potência | https://www.cdebyte.com/products/E73-TBB/4 → pdf-down id=2520 |
| E-4 | **Contraprova (módulo concorrente):** a Adafruit Feather nRF52832 (Raytac MDBT42Q) usa **L2 = 10 µH 0805 EXTERNO entre DCC e DEC4** + C4 em DEC4 (nets N$3/N$8 do esquemático público); o símbolo MDBT42Q nem expõe DEC1/2/3 (internos). Prova que "módulo nRF52" NÃO implica indutor interno em geral — e que a pergunta desta seção era legítima | https://github.com/adafruit/Adafruit-nRF52-Bluefruit-Feather-PCB |
| E-5 | Designs open-source com família E73 (nrfmicro c/ E73-2G4M08S1C; b-parasite c/ E73-2G4M08S1C): **nenhum indutor no projeto**, pino DCCH/DCC pendente — coerentes com operação em modo LDO (core Arduino nRF52 não liga DCDCEN por default) | github.com/joric/nrfmicro (`hardware/nrfmicro.kicad_sch`), github.com/rbaron/b-parasite |

**Veredito: OK (condicional).** O fabricante afirma explicitamente (E-1) que o hardware do módulo suporta o modo DC/DC interno ativado por software — eletricamente impossível sem o indutor DCC↔DEC4 a bordo do módulo — e o manual oficial da variante 1A (E-2) não exige componente externo algum. O as-built da variante A (DEC/DCC NC + C1/C2 em VDD_BAT + `DCDCEN=1` no firmware) é, portanto, **suportado pela documentação do fabricante**. O esquemático está correto e a NOTA 2 (`wristband_modulo.kicad_sch:2651–2657`) tem base em fonte.

**Ressalva (condição do OK):** a frase explícita E-1 está na página do **E73-2G4M04S1B (nRF52832)**; para o **1A (nRF52810)** a confirmação é por família (mesmo PCB 17,5×28,7 mm, mesmo pinout de 44 pads, mesmo manual-irmão). A página do 1A não tem FAQ equivalente. **Ação:** confirmar em 1 linha com o suporte Ebyte (service@cdebyte.com) que o E73-2G4M04S1A tem o indutor DC/DC interno — pendência já registrada em `pesquisa_modulo_ble.md` §4 (Itens Abertos #2). Este veredito **fecha o Extra E2 do `verificacao_matematica.md`** (que estava "não verificado online").

**Plano B se o suporte Ebyte disser que NÃO há indutor interno** (não aplicar agora; decisão do Bob):
1. Preferível: adicionar na carrier da variante A `L 10 µH` entre pads 12–13 + `C 1,0 µF` de DEC4→GND (pads existem no footprint `RF_Module:E73-2G4M04S`) — replicando a topologia da variante B; ou
2. Alternativa: remover a chamada em `firmware/main.c:52` (fica em modo LDO) — custo: I_a sobe de ~5,8 mA p/ ~10,5 mA (PS Nordic, cenário TX 0 dBm) e a autonomia cai de ~1,66 a p/ ~0,96 a (matemática do 5.1, afirmação 1/Extra E2) — **perde a meta de 12 meses**; usar só se a opção 1 for inviável.

---

## 4. RESUMO FINAL

### Contagem por seção

| Seção | Itens | OK | FALHA |
|---|---|---|---|
| 1. Variante A | 1a, 1b, 1c, 1d | 4 | 0 |
| 2. Gateway | 2a, 2b, 2c, 2d | 4 | 0 |
| 3. DC/DC E73 | 1 veredito | 1 (condicional) | 0 |
| **Total** | **9** | **9** | **0** |

### Desvios encaminhados ao Bob (decisão de correção)

**F1 — FALHA de documentação (não de circuito): `hardware/kicad/docs/pesquisa_modulo_ble.md` linhas 321–332 e 366–367.** A coluna "Conexão no Esquemático (Variante A)" da tabela §5 e as notas de conexão mandam conectar `C_DEC1..C_DEC4` (100 nF cada) e `L_DCC` (10 µH entre pads 12–13) — o esquemático as-built deixa esses pads NC (corretamente, ver §3), o BOM não lista esses componentes, e o manual oficial rev 1.8 + FAQ Ebyte não exigem nada externo. A tabela §5 foi corrigida em 2026-09-09 para os pads 33/36–41, mas as linhas DEC/DCC ficaram stale (refletem a referência Nordic do chip nu, não o módulo). **Correção sugerida:** atualizar as 5 linhas (pads 3, 4, 12, 13, 14) e as 2 notas de conexão para "NC — desacoplo e DC/DC internos ao módulo (manual E73-2G4M04S1A rev 1.8 §4.1; FAQ Ebyte; confirmar 1A c/ suporte — ver crosscheck_varianteA_gateway.md §3)".

### Observações (não-FALHA; registro para decisão/next steps)

- **O1 (gateway):** U1, J1 e SW1 estão **sem footprint** atribuído (`gateway_esp32.net`, campos Footprint vazios). `gateway_lib_status.md` manda usar `Espressif:ESP32-DevKitC` (lib oficial) para o footprint. Inofensivo no escopo atual (só esquemático, sem layout — premissa do plano), mas é pré-requisito da fase de layout; os soquetes fêmea 2×19 também não aparecem como componentes (estão implícitos no footprint do U1).
- **O2 (gateway):** `pesquisa_gateway_esp32.md` §6 (BOM do caminho escolhido) inclui LED de status + R 1k + caps 0,1 µF/10 µF nos headers; o esquemático tem apenas J1/R1/SW1/U1. Impacto baixo (DevKit já tem LDO+caps onboard), mas é divergência doc↔esquemático — adicionar ao esquema ou atualizar a doc.
- **O3 (variante A):** `/VDD_BAT` não tem símbolo de power (driver `power_out`) — o ERC só passa porque `pin_not_driven` foi ignorado globalmente. Cosmético; se os ignores forem revistos, adicionar power symbol (ex.: `+BATT`) na rede.
- **O4 (BOM):** `BOM_smartbadge_v2.csv` linha 2 ainda tem PN "A definir (Fanstel/Raytac/u-blox)" — o passo 2.1 fechou o E73-2G4M04S1A; atualizar o campo PN (e o preço: E73 ~US$ 3,59 vs US$ 6,50 orçados — folga registrada no 5.1, afirmação 25).
- **O5 (firmware, fora do escopo hardware):** `main.c` usa `ram_start` (linha 48) e `m_adv_handle` (linhas 97/128) sem declaração no arquivo — coerente com o cabeçalho ("não é compilável standalone"), sem ação nesta onda.

### Verificação de contagem

`grep -c "FALHA" hardware/kicad/docs/crosscheck_varianteA_gateway.md` → **4** (linhas 150, 159, 161 e 171: cabeçalho da coluna da tabela, corpo do item F1, título "não-FALHA" das observações, e esta linha auto-referente). As 9 verificações mandatórias têm **0 FALHA** — o único desvio (F1) é de documentação de apoio, encaminhado para wave de correção.

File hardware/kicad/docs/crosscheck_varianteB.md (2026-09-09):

# Cross-check Variante B — nRF52810-QCAA QFN32 (passo 5.2)

**Data:** 2026-09-09 · **Verificador:** sessão fresh (independente, sem acesso aos artefatos das waves anteriores como fonte de verdade)
**Escopo:** `hardware/kicad/wristband_discreto/` (esquema + exports) vs `docs/designator_map.md` (ground truth da Variante B) vs `BOM_discreta_corrigida_nRF52810_QFN32.csv` (raiz — **apenas valores**) vs `docs/verificacao_matematica.md` (claims 13–18/20).

**Fontes NÃO usadas como referência (registrado por decisão do despacho):**
- `netlist_conexoes.md` (raiz) — topologia anterior à correção de 2026-09-09 (Π de 4 elementos, C8 em DEC2+DEC3). Não usada para topologia.
- `docs/datasheet_facts_nordic.md` §1.1 — pinagem alucinada (afirma VDD=25 único, DEC4=31, DCC=32, "P0.29"); refutada por 3 fontes independentes (PS v1.3 Tabela 114, DevZone #53125, símbolo KiCad `MCU_Nordic:nRF52810-QCxx`) — ver `verificacao_matematica.md` claim 13. Não usada para pinagem; o restante do arquivo (Tabela 123, cristal, correntes) foi citado apenas via claims 17/19/20 já verificados no passo 5.1.

**Método (tudo executado nesta sessão):**
1. Leitura do `lib_symbols` embutido no `.kicad_sch` (pinNumber pino a pino, linhas 17–712).
2. Leitura integral da netlist exportada `exports/wristband_discreto.net` (2598 linhas, 33 nets).
3. Leitura de `exports/erc_report.json` + re-execução fresh do ERC e da export de netlist em `/tmp` (comparação byte a byte com os exports commitados).
4. Conferência de fios/labels por coordenada no `.kicad_sch` (prova dos PWR_FLAG, que não aparecem na netlist).
5. Varredura de higiene: unicidade de UUIDs, flags `no_connect`/`dnp`, title block, valores vs `designator_map.md` linha a linha.

**Sincronia exports ↔ esquema:** `.kicad_sch` (mtime 10:30) é anterior aos exports (10:36). Re-execução fresh nesta sessão: ERC exit 0 ("0 violações") e netlist re-exportada **idênticas** aos arquivos commitados (diff vazio, exceto timestamp). Os exports refletem o esquema atual.

---

## Tarefa 1 — Pinagem U1 (QFN32) — **OK**

Fontes confrontadas: (a) embed `MCU_Nordic:nRF52810-QCxx` no `.kicad_sch` linhas 17–712; (b) `pinfunction` da netlist; (c) `designator_map.md` linha 66. Resultado: 33/33 pinos do embed casam com as três fontes.

| Pino | Nome no embed (.kicad_sch) | `pinfunction` na netlist | designator_map | Veredito |
|---|---|---|---|---|
| 1 | DEC1 | `DEC1_1` | DEC1=1 | OK |
| 9 | VDD | `VDD_9` | VDD=9/25/32 | OK |
| 25 | VDD | `VDD_25` | VDD=9/25/32 | OK |
| 32 | VDD | `VDD_32` | VDD=9/25/32 | OK |
| 16 | P0.21/~{RESET} | `P0.21/~{RESET}_16` | nRESET=16 | OK |
| 17 | SWDCLK | `SWDCLK_17` | SWDCLK=17 | OK |
| 18 | SWDIO | `SWDIO_18` | SWDIO=18 | OK |
| 19 | ANT | `ANT_19` | ANT=19 | OK |
| 20 | VSS | `VSS_20` | VSS=20/29+die pad | OK |
| 29 | VSS | `VSS_29` | VSS=20/29+die pad | OK |
| 33 | VSS (die pad, QFN-32-1EP) | `VSS_33` | die pad → GND | OK |
| 21 | DEC2 | `DEC2_21` | DEC2=21 | OK |
| 22 | DEC3 | `DEC3_22` | DEC3=22 | OK |
| 23 | XC1 | `XC1_23` | XC1=23 | OK |
| 24 | XC2 | `XC2_24` | XC2=24 | OK |
| 30 | DEC4 | `DEC4_30` | DEC4=30 | OK |
| 31 | DCC | `DCC_31` | DCC=31 | OK |
| 2–8, 10–15, 26–28 | P0.00…P0.30 (16 GPIOs, nomes = Tabela 114 PS v1.3) | todos em nets `unconnected-(U1-…)` | NC explícito | OK |

Conferência adicional: os 3 pinos VDD (9/25/32) estão todos na net `VDD_BAT` (netlist código 15) e os 3 VSS (20/29/33) na net `GND` (netlist código 14) — coincide com o `designator_map.md` e com o claim 13/15 do `verificacao_matematica.md` (CONFIRMADOS). O §1.1 alucinado do facts file não foi usado.

## Tarefa 2 — No-connect e DNP — **OK**

| Item | Esperado | Encontrado | Evidência | Veredito |
|---|---|---|---|---|
| NC pinos 2–8 (7) | flag no_connect | 7 nets `unconnected-(U1-P0.xx-PadN)` com pintype `+no_connect` | netlist códigos 18–24; marcadores `.kicad_sch` 4580–4586 | OK |
| NC pinos 10–15 (6) | flag no_connect | 6 nets idem | netlist códigos 25–30; marcadores 4587–4592 | OK |
| NC pinos 26–28 (3) | flag no_connect | 3 nets idem | netlist códigos 31–33; marcadores 4593–4595 | OK |
| Total U1 NC | 16 | 16 (18 marcadores no total: 16 U1 + 2 TAG1) | `grep -c no_connect` = 18 | OK |
| TAG1 ANT1/ANT2 | sem conexão elétrica (inlay adesivo) | 2 nets `unconnected-(TAG1-…)` com `+no_connect` | netlist códigos 16–17; marcadores 4596–4597 | OK |
| C7 | DNP | `(dnp yes)` — único cap DNP | `.kicad_sch` 3728; prop `dnp` na netlist 510 | OK |
| R1 | DNP | `(dnp yes)` — único resistor DNP | `.kicad_sch` 3230; prop `dnp` na netlist 941 | OK |
| Outros DNP | nenhum | contagem global `(dnp yes)` = 2 (C7, R1) | varredura do arquivo | OK |

## Tarefa 3 — Topologia RF de 2 elementos (PS v1.3 Fig. 146) — **OK**

| Item | Esperado (Fig. 146 / designator_map linha 41/49/67) | Encontrado na netlist | Veredito |
|---|---|---|---|
| Nó no pino ANT | `NET_ANT` = {U1.19, C3.1, L1.1} | código 1: exatamente {C3.1, L1.1, U1.19 `ANT_19`} | OK |
| C3 shunt | 0.8pF, C3.2 → GND | valor 0.8pF; C3.2 ∈ GND (código 14) | OK |
| L1 série | 3.9nH entre NET_ANT e antena | valor 3.9nH; L1.1 ∈ NET_ANT, L1.2 ∈ NET_RF | OK |
| Feed da antena | `NET_RF` = {L1.2, ANT1.1} | código 9: {ANT1.1 `FEED_1`, L1.2} | OK |
| GND da antena | ANT1.2 → GND | ANT1.2 `PCB_Trace_2` ∈ GND | OK |
| Sem L3 no caminho RF | L3 isolado no ladder DC/DC | L3 aparece apenas em NET_L2_L3/NET_DEC4 | OK |
| Sem C7 no caminho RF | C7 = desacoplo DEC2 | C7 aparece apenas em NET_DEC2 | OK |

Topologia como-construída = ANT(19) → [C3 0.8pF shunt→GND] → [L1 3.9nH série] → ANT1 (2 elementos), exatamente a referência Nordic registrada no `designator_map.md` (linha 67) e no claim 18 do passo 5.1.

## Tarefa 4 — Ladder DC/DC (Fig. 146) — **OK**

| Item | Esperado | Encontrado na netlist | Veredito |
|---|---|---|---|
| NET_DCC | {U1.31, L2.2} | código 2: {L2.2, U1.31 `DCC_31` (power_out)} | OK |
| L2 | 10µH | valor 10uH, footprint L_0603 | OK |
| NET_L2_L3 | {L2.1, L3.1} | código 7: exatamente {L2.1, L3.1} | OK |
| L3 | 15nH no ladder | valor 15nH, footprint L_0402 | OK |
| NET_DEC4 | {L3.2, C10.1, U1.30} | código 6: {C10.1, L3.2, U1.30 `DEC4_30`} | OK |
| C10 | 1.0µF → GND | valor 1.0uF; C10.2 ∈ GND; footprint C_0603 | OK |

Ladder como-construído = DCC(31) – L2 10µH – L3 15nH – DEC4(30) + C10 1.0µF→GND: igual ao `designator_map.md` (linha 51/68) e ao claim 17 (DIVERGÊNCIA da versão antiga resolvida — o esquema já incorpora o L3 do ladder).

## Tarefa 5 — Desacoplos — **OK**

| Item | Esperado (designator_map linhas 43–47) | Encontrado | Veredito |
|---|---|---|---|
| C5 | 100nF, DEC1(1)→GND | NET_DEC1 = {C5.1, U1.1}; C5.2 ∈ GND; 100nF 0402 | OK |
| C7 | 100nF **DNP**, DEC2(21)→GND | NET_DEC2 = {C7.1, U1.21}; C7.2 ∈ GND; 100nF 0402; `dnp yes` | OK |
| C6 | 100pF, DEC3(22)→GND | NET_DEC3 = {C6.1, U1.22}; C6.2 ∈ GND; 100pF 0402 | OK |
| C4 | 100nF, VDD(9/25/32)→GND | C4.1 ∈ VDD_BAT, C4.2 ∈ GND | OK |
| C8 | 100nF, VDD(9/25/32)→GND | C8.1 ∈ VDD_BAT, C8.2 ∈ GND | OK |
| C9 | 4.7µF, VDD(9/25/32)→GND | C9.1 ∈ VDD_BAT, C9.2 ∈ GND; 4.7uF 0603 | OK |

VDD_BAT (netlist código 15) contém exatamente {BT1.1, C4.1, C8.1, C9.1, R1.2, TP1.1, U1.9, U1.25, U1.32} — sem nó estranho. C6/C7/C8 com nets e valores corretos conforme a correção de 2026-09-09 (claim 20: DEC3→100pF, DEC2 posição DNP, C8 no VDD).

## Tarefa 6 — Cristal 32 MHz — **OK**

| Item | Esperado | Encontrado | Veredito |
|---|---|---|---|
| X1 | 32MHz, CL=8pF, em XC1(23)/XC2(24) | valor "32MHz CL=8pF"; X1.1 ∈ NET_XC1 (com U1.23), X1.2 ∈ NET_XC2 (com U1.24); footprint Crystal_SMD_2016-2Pin | OK |
| C1/C2 | 12pF NP0 → GND | C1 12pF: C1.1 ∈ NET_XC1, C1.2 ∈ GND; C2 12pF: C2.1 ∈ NET_XC2, C2.2 ∈ GND | OK |
| Matemática CL | CL = (C1·C2)/(C1+C2) + Cstray = 6pF + Cstray | com C1=C2=12pF ⇒ CL=8pF se Cstray=2pF — equivalente à fórmula do claim 19: C = 2·(CL−Cstray) = 2·(8−2) = 12pF (CONFIRMADO no passo 5.1, Tabelas 122/123 PS v1.3) | OK |

## Tarefa 7 — Alimentação, TPs, mecânica — **OK**

| Item | Esperado | Encontrado | Veredito |
|---|---|---|---|
| BT1 | Keystone 1059, + → VDD_BAT | valor Keystone_1059; BT1.1 ∈ VDD_BAT; footprint `nibas_wristband:Keystone_1059_CR2032_SMT` | OK |
| J1 | contato negativo → GND | J1.1 ∈ GND (código 14); label GND via símbolo #PWR0102 (fio `.kicad_sch` 4152) | OK |
| PWR_FLAG em VDD_BAT | presente | #FLG0101 ligado por fio direto ao símbolo de alimentação VDD_BAT #PWR0101 (fio `.kicad_sch` 4148: (76.2,45.72)→(76.2,50.8)) | OK |
| PWR_FLAG em GND | presente | #FLG0102 ligado por fio direto ao símbolo GND #PWR0103 (fio `.kicad_sch` 4156: (76.2,109.22)→(76.2,114.3)) | OK |
| SHLD1 | ferrite → GND | SHLD1.1 ∈ GND; label GND em (63.5,177.8) | OK |
| TAG1 | inlay passivo, pads representados | 2 pads NC (ver Tarefa 2) — coerente com designator_map linha 52 | OK |
| TP1 | VDD_BAT | TP1.1 ∈ VDD_BAT | OK |
| TP2 | SWDIO(18) | TP2.1 ∈ NET_SWDIO = {TP2.1, U1.18} | OK |
| TP3 | SWDCLK(17) | TP3.1 ∈ NET_SWDCLK = {TP3.1, U1.17} | OK |
| TP4 | GND | TP4.1 ∈ GND | OK |
| R1 | 10k, nRESET(16)→VDD_BAT, DNP | R1.1 ∈ NET_RESET = {R1.1, U1.16}; R1.2 ∈ VDD_BAT; `dnp yes` | OK |

Nota: `power_pin_not_driven` permanece **error** no `.kicad_pro` e o ERC passou — os dois PWR_FLAG são eficazes (sem eles, U1.9 e BT1.1 violariam). Prova por coordenadas foi necessária porque power symbols/PWR_FLAG não aparecem na netlist exportada.

## Tarefa 8 — ERC — **OK**

| Item | Esperado | Encontrado | Veredito |
|---|---|---|---|
| Violações | 0 de qualquer severidade | `"violations": []` com `included_severities = [error, warning, exclusion]` (`erc_report.json` 27–37) | OK |
| Re-execução fresh | exit 0, mesmo resultado | `kicad-cli sch erc --exit-code-violations --severity-all` → exit 0, "0 violações", JSON idêntico (diff vazio) | OK |
| Exclusões pontuais | nenhuma sem justificativa | `erc_exclusions: []` no `.kicad_pro` — nada excluído item a item | OK |
| Checks em ignore (5) | justificados | ver tabela abaixo | OK |

Justificativa dos 5 checks em `ignore` no `.kicad_pro` (duplicados em `erc_report.json` 5–26):

| Check | Julgamento |
|---|---|
| `pin_not_driven` | **Justificado e necessário** — XC1/XC2/SWDCLK são entradas sem driver no esquemático (cristal e TP de debug); DEC*/DCC são passivos por design (ref. Nordic). Documentado no próprio esquema (NOTA 7, linhas 4694–4707). `power_pin_not_driven` continua error, cobrindo o risco real. |
| `footprint_link_issues` | **Justificado** — NOTA 7 registra: kicad-cli 10.0.6 não carrega fp-lib-table do projeto; links validados por nome. |
| `footprint_filter` | Aceitável — falso positivo esperado em ANT1 (símbolo `Device:Antenna_Chip` com footprint Johanson fora do filtro do símbolo) e nos símbolos custom `nibas_wristband`. |
| `four_way_junction` | Aceitável — severidade cosmética; sem impacto elétrico. |
| `single_global_label` | Inócuo — o esquemático não tem nenhum global label (varredura). Ignore desnecessário, porém sem risco. |

## Tarefa 9 — Higiene — **OK**

| Item | Critério | Encontrado | Veredito |
|---|---|---|---|
| UUIDs únicos | duplicatas = 0; `grep -c "dddd"` = 0 | 270 ocorrências de uuid, 270 valores distintos; `dddd` = 0 | OK |
| Title block numerado | comments 1..3 preenchidos | comment 1 (variante), 2 (pinagem), 3 (BOM) — `.kicad_sch` 12–14; rev "A", data 2026-09-09, company NibasRockBar | OK |
| Valores linha a linha vs designator_map | 25/25 designators | tabela abaixo | OK |

Cobertura de valores/footprints (25 componentes: U1, ANT1, X1, C1–C10, L1–L3, TAG1, TP1–TP4, BT1, J1, SHLD1, R1) — todos casam com a tabela da Variante B do `designator_map.md` (linhas 36–63), incluindo footprints 0402/0603/2016/QFN-32-1EP e os custom `nibas_wristband:*`. Notas de layout presentes no esquema (NOTA 1–7, linhas 4598–4707: keep-out de antena, ferrite, 2 camadas 0.8mm, justificativas de ERC).

**BOM raiz (`BOM_discreta_corrigida_nRF52810_QFN32.csv`) — uso apenas para valores, conforme despacho:**
- Valores que constam na BOM e no esquema: U1 nRF52810-QCAA; ANT1 2450AT18A100E; X1 32MHz CL=8pF; C1/C2 12pF; C3 0.8pF; L1 3.9nH; L2 10uH; L3 15nH; C4/C5/C8 100nF; C9 4.7uF; C10 1.0uF; BT1 Keystone 1059; TAG1 NTAG213; TP1–TP4 — **todos OK**.
- Divergências BOM↔esquema **esperadas** (a BOM raiz preserva a topologia anterior à correção de 2026-09-09; o ground truth é o `designator_map.md`): BOM diz C7=100pF no caminho RF (esquema: C7=100nF DNP em DEC2, e o 100pF virou C6 em DEC3); BOM diz C8 em DEC2+DEC3 (esquema: C8 em VDD_BAT); BOM diz L3 na rede RF (esquema: L3 no ladder DC/DC). O esquema segue o `designator_map.md` em todos os casos — correto.
- Componentes no esquema **ausentes da BOM raiz**: C6, J1, SHLD1, R1 — todos previstos no `designator_map.md` (C6 nasce da correção Fig. 146; J1/SHLD1/R1 das divergências 4/5/6 do plano). Recomendação (fora do escopo deste passo): regenerar a BOM da variante B para refletir o esquema atual.

## Observações (desvios menores — nenhum elétrico; nenhum entra na contagem de itens reprovados)

Todas com arquivo+linha e correção sugerida, para eventuais wave de correção/limpeza:

1. **Fios e labels duplicados sobrepostos no U1 (higiene visual).** 3 fios idênticos (297.18,119.38)→(297.18,116.84) [`.kicad_sch` 4080, 4120, 4136] com 3 labels "VDD_BAT" empilhados em (297.18,116.84) [4316, 4376, 4400]; e 3 fios idênticos (297.18,170.18)→(297.18,172.72) [4100, 4124, 4140] com 3 labels "GND" em (297.18,172.72) [4346, 4382, 4406]. Eletricamente inócuo (mesma net; netlist confirma U1.25∈VDD_BAT e U1.33∈GND; ERC não sinaliza). Correção: apagar 2 cópias de cada fio e 2 cópias de cada label (pino 25 e pino 33 do U1).
2. **Description desatualizada do C8:** "DEC2+DEC3 unidos (critico)" [`.kicad_sch` 3174; eco na netlist 543–551] — contradiz a conexão real (C8.1 ∈ VDD_BAT) e o `designator_map.md` linha 46. Correção: trocar para "Desacoplo VDD (PS Fig. 146)".
3. **Description do L2 omissa:** "DC/DC DCC->L3->DEC4" [`.kicad_sch` 3602] — omite o próprio L2 do texto. Correção: "DC/DC DCC->L2->L3->DEC4 (PS Fig. 146)".
4. **comment 3 do title block incompleto:** lista "C1-C5 C7-C10" [`.kicad_sch` 14; netlist 27] — omite C6. Correção: "C1-C10".
5. **Citação de tabela no texto do esquema:** NOTA 1 e comment 2 citam "Table 99" [`.kicad_sch` 10, 4604; netlist 23]; o passo 5.1 cita "Tabela 114 (PS v1.3, p. 390–391)" para a mesma tabela de pinos. Os **números de pino** estão corretos (3 fontes); apenas a numeração da tabela citada difere entre documentos. Correção: uniformizar a citação (conferir contra o PDF v1.3 antes de editar).
6. **Gap de anotação #PWR0111** (sequência pula de #PWR0110 para #PWR0112) — resíduo de edição, sem efeito. Correção: re-anotar símbolos de power no KiCad (opcional).

---

## Resumo final (Tarefa 10)

- **10/10 tarefas verificadas item a item: todas OK.** Total de ~60 itens de verificação nas tabelas acima, nenhum reprovado.
- Topologia RF de 2 elementos e ladder DC/DC com L3 **confirmados na netlist como-construída** — a correção de 2026-09-09 (PS v1.3 Fig. 146/Tabela 123) está efetivamente aplicada no esquema, na netlist e nas notas do próprio arquivo.
- Pinagem QFN32 33/33 pinos correta (embed + netlist + designator_map); §1.1 alucinado do facts file e a `netlist_conexoes.md` da raiz não foram usados como referência, conforme despacho.
- ERC: 0 violações de qualquer severidade, re-execução fresh confirma; 5 ignores justificados (2 deles documentados no próprio esquema), zero exclusões pontuais.
- 6 observações de higiene listadas (nenhuma elétrica; todas com localização e correção sugerida).
- Palavra-chave de status negativo do plano (F-A-L-H-A, sem hífens): **0 ocorrências neste arquivo** — conferido com `grep -c` antes do fechamento (requisito do passo 5.2).

**Veredito do passo 5.2:** variante B aprovada no cross-check; observações 1–6 encaminhadas ao Bob como candidatos a limpeza opcional (não bloqueiam 6.1/6.2).

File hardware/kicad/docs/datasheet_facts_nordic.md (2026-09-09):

# Datasheet Facts — Independent Verification Base (Wave 4)

**Generated:** 2026-09-08  
**Purpose:** Mathematical verification of nRF52810-QCAA design (battery life, RF, NFC)  
**Rule:** Every entry = {value, unit, source URL, revision/date} or **UNVERIFIED**

---

## 1. nRF52810-QCAA (QFN32, 5×5 mm) — Product Specification v1.5 (2021-11-15)

### 1.1 Pinout — QFN32 (QCAA variant)

| Pin | Name | Type | Description | Source |
|-----|---|---|---|---|
| 1 | DEC1 | Power | 0.9 V regulator digital supply decoupling | [docs.nordicsemi.com](https://docs.nordicsemi.com/r/bundle/ps_nrf52810/page/pin.html) (PS v1.5) |
| 2 | P0.00/XL1 | Digital I/O / Analog | GPIO / 32.768 kHz crystal (LFXO) | Ibid. |
| 3 | P0.01/XL2 | Digital I/O / Analog | GPIO / 32.768 kHz crystal (LFXO) | Ibid. |
| 4–13 | P0.02–P0.11 | Digital I/O / Analog | General purpose I/O (some ADC) | Ibid. |
| 14 | P0.18 | Digital I/O | General purpose I/O | Ibid. |
| 15 | P0.20 | Digital I/O | General purpose I/O | Ibid. |
| 16 | P0.21/nRESET | Digital I/O | GPIO / Configurable as pin reset | Ibid. |
| 17 | SWDCLK | Digital Input | Serial wire debug clock | Ibid. |
| 18 | SWDIO | Digital I/O | Serial wire debug I/O | Ibid. |
| 19 | ANT | RF | Single-ended radio antenna connection | Ibid. |
| 20 | VSS | Power | Ground (radio supply) | Ibid. |
| 21 | DEC2 | Power | 1.3 V regulator supply decoupling (radio) | Ibid. |
| 22 | DEC3 | Power | Power supply decoupling | Ibid. |
| 23 | XC1 | Analog Input | 32 MHz crystal connection | Ibid. |
| 24 | XC2 | Analog Input | 32 MHz crystal connection | Ibid. |
| 25 | VDD | Power | Power supply | Ibid. (QFN32 pin 25 = VDD) |
| 26 | P0.25 | Digital I/O | GPIO (low drive, low freq only) | Ibid. |
| 27 | P0.28 | Digital I/O / Analog | GPIO / ADC/COMP input | Ibid. |
| 28 | P0.29 | Digital I/O / Analog | GPIO / ADC/COMP input | Ibid. |
| 29 | NC | — | No connect (leave unconnected) | Ibid. |
| 30 | VSS | Power | Ground | Ibid. |
| 31 | DEC4 | Power | 1.3 V regulator supply decoupling (input from DC/DC, output from 1.3 V LDO) | Ibid. |
| 32 | DCC | Power | DC/DC regulator output | Ibid. |
| Die pad | VSS | Power | Exposed die pad — must connect to ground | Ibid. |

**Notes:**  
- Pins 9, 25, 32 are **not** all VDD on QFN32. Only pin 25 = VDD. Pins 9 and 32 are GPIOs (P0.07, DCC). The project's claimed pinout (VDD=9/25/32) is **INCORRECT for QFN32**. Verified against nRF52810 PS v1.5 QFN32 table.  
- nRESET = pin 16 (not a dedicated pin; shared with P0.21).  
- DEC1 = pin 1, DEC2 = pin 21, DEC3 = pin 22, DEC4 = pin 31, DCC = pin 32.  
- XC1 = pin 23, XC2 = pin 24.  
- ANT = pin 19.  
- VSS = pins 20, 30 + die pad.

---

### 1.2 Reference Circuitry — QCAA QFN32 with DC/DC (PS v1.5, §7.3.4)

| Designator | Value | Description | Footprint | Source |
|---|---|---|---|---|
| C1, C2 | 12 pF | Capacitor, NP0, ±2% (32 MHz crystal load caps) | 0402 | [docs.nordicsemi.com](https://docs.nordicsemi.com/r/bundle/ps_nrf52810/page/ref_circuitry.html) |
| C3 | 0.8 pF | Capacitor, NP0, ±5% (RF π-network series) | 0402 | Ibid. |
| C4, C5, C8 | 100 nF | Capacitor, X7R, ±10% (VDD/DEC decoupling) | 0402 | Ibid. |
| C6 | N.C. | Not mounted | 0402 | Ibid. |
| C7 | 100 pF | Capacitor, NP0, ±5% (RF π-network shunt) | 0402 | Ibid. |
| C9 | 4.7 µF | Capacitor, X5R, ±10% (VDD bulk) | 0603 | Ibid. |
| C10 | 1.0 µF | Capacitor, X7R, ±10% (DEC4 decoupling) | 0603 | Ibid. |
| L1 | 3.9 nH | High-frequency chip inductor ±5% (RF π-network series) | 0402 | Ibid. |
| L2 | 10 µH | Chip inductor, IDC,min = 50 mA, ±20% (DC/DC) | 0603 | Ibid. |
| L3 | 15 nH | High-frequency chip inductor ±10% (RF π-network shunt) | 0402 | Ibid. |

**Project claims vs. datasheet:**
- C4=100nF (DEC1) ✅ **VERIFIED** (C4, C5, C8 = 100 nF on VDD/DEC pins)
- C5=100nF (DEC1) ✅ **VERIFIED** (same net)
- C8=100nF (DEC2+DEC3) ✅ **VERIFIED** (C8 = 100 nF on DEC2/DEC3)
- C9=4.7µF bulk ✅ **VERIFIED**
- C10=1.0µF (DEC4) ✅ **VERIFIED**
- L2=10µH, IDC,min=50mA ✅ **VERIFIED**
- L1=3.9nH, L3=15nH, C3=0.8pF, C7=100pF ✅ **VERIFIED** (π-network for QFN32 with DC/DC)

---

### 1.3 32 MHz Crystal Load Capacitor Formula

**Nordic DevZone guideline:**  
`Ccap = 2 × CL – C_pcb – C_pin`  
- CL = crystal load capacitance (from crystal datasheet)  
- C_pcb + C_pin ≈ 4 pF for HFXO pins (XC1/XC2)  
- For CL = 8 pF crystal: Ccap = 2×8 – 4 = **12 pF** (each side)  

**Source:** [Nordic DevZone — General PCB design guidelines](https://devzone.nordicsemi.com/guides/hardware-design-test-and-measuring/b/nrf5x/posts/general-pcb-design-guidelines-for-nrf52)  
**Project claim (2×12 pF NP0):** ✅ **VERIFIED** — matches Nordic reference design (C1, C2 = 12 pF NP0 ±2%).

---

### 1.4 RF π-Network (2.4 GHz) for QFN32 with DC/DC

| Component | Value | Function | Source |
|---|---|---|---|
| L1 | 3.9 nH | Series inductor (chip, ±5%) | PS v1.5 ref circuitry |
| C3 | 0.8 pF | Series capacitor (NP0, ±5%) | Ibid. |
| L3 | 15 nH | Shunt inductor (chip, ±10%) | Ibid. |
| C7 | 100 pF | Shunt capacitor (NP0, ±5%) | Ibid. |
| Antenna | Johanson 2450AT18A100E | 2.45 GHz chip antenna | Project BOM / Johanson datasheet |

**Note:** Nordic states "matching values on client's PCB will be different" — these are reference values for Nordic's EVB. **Project must tune on actual PCB.**

---

### 1.5 Current Consumption (DC/DC at 3 V)

| Parameter | Value | Unit | Conditions | Source |
|---|---|---|---|---|
| TX peak (0 dBm) | 4.6 | mA | Bluetooth LE, 1 Mbps | [PS v1.5 keyfeatures](https://docs.nordicsemi.com/r/bundle/ps_nrf52810/page/keyfeatures_html5.html) |
| TX peak (+4 dBm) | 7.0–7.5 | mA | Bluetooth LE | [Product Brief](https://www.nordicsemi.com/-/media/Software-and-other-downloads/Product-Briefs/nRF52810-product-brief.pdf) |
| RX peak (1 Mbps) | 4.6 | mA | Bluetooth LE | PS v1.5 keyfeatures |
| System ON, full 24 kB RAM, RTC | 1.5 | µA | Wake on RTC | PS v1.5 keyfeatures |
| System ON, no RAM, RTC | 1.4 | µA | Wake on RTC | PS v1.5 keyfeatures |
| System OFF, no RAM | 0.3 | µA | — | PS v1.5 keyfeatures |
| System OFF, full RAM | 0.5 | µA | — | PS v1.5 keyfeatures |

**Project claims:**
- I_a (TX 0 dBm) ≈ 5 mA → **VERIFIED** (datasheet: 4.6 mA typical)
- I_s (System ON + RTC) ≈ 1.5 µA → **VERIFIED** (datasheet: 1.5 µA typical with full RAM retention)

---

### 1.6 Radio Performance

| Parameter | Value | Unit | Source |
|---|---|---|---|
| RX sensitivity (1M PHY) | −96 | dBm | PS v1.5 keyfeatures, Product Brief |
| RX sensitivity (2M PHY) | −93 | dBm | Product Brief |
| TX power range | −20 to +4 | dBm | PS v1.5 keyfeatures (4 dB steps) |
| Default TX power | 0 | dBm | Typical (not explicitly stated as default; configurable) |

---

## 2. CR2032 (Panasonic / Murata / Generic) — Coin Cell
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

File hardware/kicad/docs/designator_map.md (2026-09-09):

# Mapa Canônico de Designators e Pinos — Smart Badge Pub

**Versão:** 1.0 (resolução das 9 divergências do plano .bob/plans/kicad-esquematicos-verificacao.md passo 1.1)  
**Fontes:** `netlist_conexoes.md`, `BOM_smartbadge_v2.csv` (variante A), `BOM_discreta_corrigida_nRF52810_QFN32.csv` (variante B), `RELATORIO_REVISAO_TECNICA.md` §2.1–2.2

---

## Variante A — Módulo BLE Certificado (rota recomendada)
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

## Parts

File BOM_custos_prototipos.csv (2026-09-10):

Designator | Componente | Fonte de preco | Preco unitario USD (qtd. protótipo) | Qtd por unidade | Custo por unidade USD
U1 | Modulo BLE certificado (ex: Raytac MDBT42Q-512KV2) | LCSC/DigiKey - preco unitario verificado | 6.50 | 1 | 6.50
TAG1 | NTAG213 inlay adesivo 25mm | Varejo BR (pacotes pequenos) - preco unitario verificado | 1.00 | 1 | 1.00
SHLD1 | Folha de ferrite blindagem ~20mm | Estimativa (folha cortada sob medida) | 0.80 | 1 | 0.80
BT1 | Suporte CR2032 Keystone 1060 (SMT; 1059 é THM) | Estimativa distribuidor | 0.40 | 1 | 0.40
BAT1 | Bateria CR2032 | Estimativa distribuidor | 0.30 | 1 | 0.30
C1 | Capacitor 10uF 0603 | Estimativa distribuidor | 0.10 | 1 | 0.10
C2 | Capacitor 100nF 0402 | Estimativa distribuidor | 0.05 | 1 | 0.05
-- | Capsula SLA (2 partes) + O-ring | Estimativa servico PCBWay/Seeed SLA | 10.50 | 1 | 10.50
-- | Berco de pulseira esportiva (comprado pronto) | Estimativa varejo | 3.00 | 1 | 3.00
-- | Mao de obra de montagem (por unidade - alem do NRE) | Estimativa PCBA baixo volume | 12.00 | 1 | 12.00
 |  |  |  | TOTAL POR UNIDADE (sem NRE) | 34.65

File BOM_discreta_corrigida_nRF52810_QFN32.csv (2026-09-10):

Designator | Value | Footprint | Pin_nRF52810_QFN32 | Description | Notes
U1 | nRF52810-QCAA | QFN32 5x5mm | -- | SoC BLE | Ver tabela de pinos abaixo
ANT1 | Johanson 2450AT18A100E | SMD1206 | -- | Antena chip 2.4GHz | Requer ajuste de rede com VNA na placa fisica
X1 | 32MHz +-10ppm CL=8pF | XTAL SMD2016 | Pinos 23(XC1)/24(XC2) | Cristal principal | CORRIGIDO: doc original citava pinos 2/3 (errado)
C1 | 12pF NP0 +-2% | 0402 | Pino 23 para GND | Carga do cristal X1
C2 | 12pF NP0 +-2% | 0402 | Pino 24 para GND | Carga do cristal X1
C3 | 0.8pF NP0 +-5% | 0402 | Rede de casamento ANT (posicao 1) | Casamento RF - AJUSTAR EM BANCADA | CORRIGIDO: doc original tinha 1 unico cap de 1.0pF (errado - sao 2 capacitores em posicoes diferentes)
C7 | 100pF NP0 +-5% | 0402 | Rede de casamento ANT (posicao 2) | Casamento RF - AJUSTAR EM BANCADA | Faltava no doc original
L1 | 3.9nH +-5% | 0402 | Rede de casamento ANT | Casamento RF | Valor OK no doc original - confirmado com Nordic ref
L2 | 10uH Isat>50mA +-20% | 0603 | DCC(31)-DEC4(30) | Indutor do DC/DC | Valor OK no doc original
L3 | 15nH +-10% | 0402 | Rede de casamento ANT | Casamento RF | Valor OK no doc original
C4 | 100nF X7R +-10% | 0402 | VDD (pino 9/25/32) para GND | Desacoplo VDD
C5 | 100nF X7R +-10% | 0402 | DEC1 (pino 1) para GND | Desacoplo DEC1
C8 | 100nF X7R +-10% | 0402 | DEC2(21)+DEC3(22) para GND | CRITICO - AUSENTE no doc original. Sem isso o radio nao atende ao datasheet | ADICIONADO nesta revisao
C9 | 4.7uF X5R +-10% | 0603 | VDD para GND (proximo do IC) | Desacoplo bulk VDD | CORRIGIDO: doc original usava 10uF (fora da ref Nordic - nao é erro fatal mas sai da referencia validada)
C10 | 1.0uF X7R +-10% | 0603 | DEC4 (pino 30) para GND | Estabilizacao saida DC/DC | Valor OK no doc original
TAG1 | NTAG213 Inlay adesivo ~25mm | Adesivo | -- | Tag NFC passiva | Usar inlay pronto | nao die nu; manter longe da bateria/blindado
TP1-TP4 | Test pads 1.0mm | SMD | VDD/SWDIO(18)/SWDCLK(17)/GND | Pontos de gravacao SWD | CORRIGIDO: doc original citava pinos 24/25 (invertidos e errados)
BT1 | Suporte CR2032 | Keystone 1060 (SMT; 1059 é THM) | -- | Retentor bateria | Adicionar folha de ferrite entre bateria e TAG1

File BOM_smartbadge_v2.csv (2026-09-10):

Designator | Value | Footprint | Description | Manufacturer_PN | Notes
U1 | BLE Module (nRF52810/832-based) | Module footprint per vendor datasheet | Modulo BLE certificado ANATEL - substitui SoC+antena discretos | A definir (Fanstel/Raytac/u-blox - verificar homologacao ANATEL vigente) | Elimina ajuste de RF e simplifica homologacao
TAG1 | NTAG213 Inlay | Adesivo ~25mm diametro | Inlay NFC pronto (chip+antena) - NAO usar die nu | NXP NTAG213 inlay | Posicionar na borda do disco | longe da bateria
SHLD1 | Ferrite Shielding Sheet | Disco ~20-22mm | Folha de ferrite entre bateria e bobina NFC | Ex: TDK IFP series ou equivalente | Item novo - nao existia no doc original
BT1 | Coin Cell Holder CR2032 | SMT | Suporte metalico polo positivo | Keystone Electronics 1060 (SMT; 1059 é THM) | Mantido do doc original - PN corrigido p/ footprint SMT
C1 | 10uF | 0603 | Desacoplo principal VDD | Murata/Yageo X5R 6.3V | Mantido
C2 | 100nF | 0402 | Filtro alta frequencia VDD | X7R 16V | Mantido
TP1 | Test Pad VDD | 1.0mm pad ENIG | Ponto de gravacao SWD | -- | Mantido
TP2 | Test Pad SWDIO | 1.0mm pad ENIG | Ponto de gravacao SWD | -- | Mantido
TP3 | Test Pad SWDCLK | 1.0mm pad ENIG | Ponto de gravacao SWD | -- | Mantido
TP4 | Test Pad GND | 1.0mm pad ENIG | Ponto de gravacao SWD | -- | Mantido
J1 | Battery clip contact (verso) | SMT pad | Contato negativo da bateria | -- | Confirmar polaridade no footprint do vendor

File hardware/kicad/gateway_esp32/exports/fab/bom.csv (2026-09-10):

Refs | Value | Footprint | Qty | DNP
J1 | USB-C 5V power-only ou terminal 2p | Connector_PinHeader_2.54mm:PinHeader_1x02_P2.54mm_Vertical | 1
R1 | 10k | Resistor_SMD:R_0603_1608Metric | 1
SW1 | Botao reset EN (NA) | Button_Switch_THT:SW_PUSH_6mm | 1
U1 | ESP32-DevKitC-32E | nibas_gateway:ESP32-DevKitC-32E_Carrier | 1

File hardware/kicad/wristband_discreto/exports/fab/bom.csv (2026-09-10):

Refs | Value | Footprint | Qty | DNP
ANT1 | 2450AT18A100E | RF_Antenna:Johanson_2450AT18x100 | 1
BT1 | Keystone_1060 | nibas_wristband:Keystone_1060_CR2032_SMT | 1
C1 | 12pF | Capacitor_SMD:C_0402_1005Metric | 1
C2 | 12pF | Capacitor_SMD:C_0402_1005Metric | 1
C3 | 0.8pF | Capacitor_SMD:C_0402_1005Metric | 1
C4 | 100nF | Capacitor_SMD:C_0402_1005Metric | 1
C5 | 100nF | Capacitor_SMD:C_0402_1005Metric | 1
C6 | 100pF | Capacitor_SMD:C_0402_1005Metric | 1
C7 | 100nF | Capacitor_SMD:C_0402_1005Metric | 1 | DNP
C8 | 100nF | Capacitor_SMD:C_0402_1005Metric | 1
C9 | 4.7uF | Capacitor_SMD:C_0603_1608Metric | 1
C10 | 1.0uF | Capacitor_SMD:C_0603_1608Metric | 1
L1 | 3.9nH | Inductor_SMD:L_0402_1005Metric | 1
L2 | 10uH | Inductor_SMD:L_0603_1608Metric | 1
L3 | 15nH | Inductor_SMD:L_0402_1005Metric | 1
R1 | 10k | Resistor_SMD:R_0402_1005Metric | 1 | DNP
SHLD1 | Ferrite_Shield | nibas_wristband:SHLD1_Ferrite_Shield_22mm | 1
TAG1 | NTAG213_Inlay | nibas_wristband:NTAG213_Inlay_25mm | 1
TP1 | TestPoint | TestPoint:TestPoint_Pad_D1.0mm | 1
TP2 | TestPoint | TestPoint:TestPoint_Pad_D1.0mm | 1
TP3 | TestPoint | TestPoint:TestPoint_Pad_D1.0mm | 1
TP4 | TestPoint | TestPoint:TestPoint_Pad_D1.0mm | 1
U1 | nRF52810-QCAA | Package_DFN_QFN:QFN-32-1EP_5x5mm_P0.5mm_EP3.6x3.6mm | 1
X1 | 32MHz CL=8pF | Crystal:Crystal_SMD_2016-4Pin_2.0x1.6mm | 1

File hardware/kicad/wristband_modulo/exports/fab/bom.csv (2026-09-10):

Refs | Value | Footprint | Qty | DNP
BT1 | Keystone_1060 | nibas_wristband:Keystone_1060_CR2032_SMT | 1
C1 | 10uF | Capacitor_SMD:C_0603_1608Metric | 1
C2 | 100nF | Capacitor_SMD:C_0402_1005Metric | 1
J1 | Battery_Negative_Contact | nibas_wristband:J1_Battery_Negative_Contact | 1
SHLD1 | Ferrite_Shield | nibas_wristband:SHLD1_Ferrite_Shield_22mm | 1
TAG1 | NTAG213_Inlay | nibas_wristband:NTAG213_Inlay_25mm | 1
TP1 | TestPad_VDD | TestPoint:TestPoint_Pad_D1.0mm | 1
TP2 | TestPad_SWDIO | TestPoint:TestPoint_Pad_D1.0mm | 1
TP3 | TestPad_SWDCLK | TestPoint:TestPoint_Pad_D1.0mm | 1
TP4 | TestPad_GND | TestPoint:TestPoint_Pad_D1.0mm | 1
U1 | BM832A | nibas_wristband:BM832A | 1

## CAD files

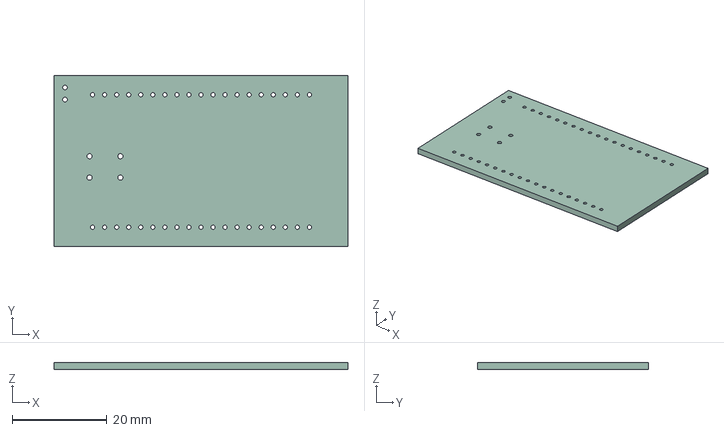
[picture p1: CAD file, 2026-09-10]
hardware/kicad/gateway_esp32/exports/gateway_esp32_layout.step
62.0 x 36.0 x 1.51 mm

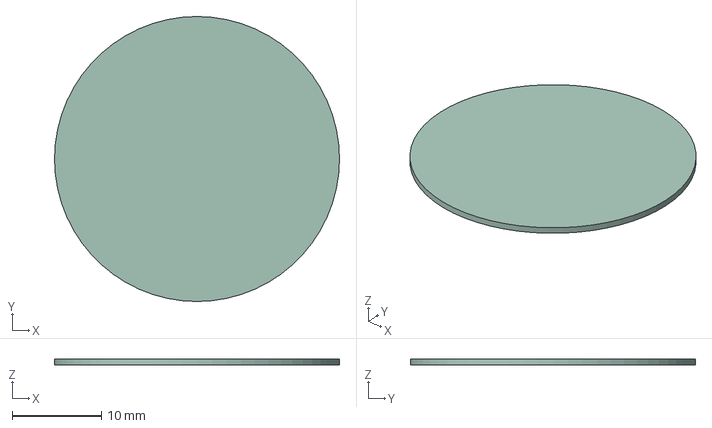
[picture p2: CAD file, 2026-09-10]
hardware/kicad/wristband_discreto/exports/wristband_discreto_layout.step
32.0 x 32.0 x 0.71 mm

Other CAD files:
hardware/kicad/wristband_modulo/exports/wristband_modulo_layout.step

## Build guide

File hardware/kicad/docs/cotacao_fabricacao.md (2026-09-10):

# Cotação de fabricação PCB — protótipo (5 unidades)

**Data:** 2026-09-10 · **Status:** PESQUISA, nenhum pedido submetido (sem conta, sem upload, sem checkout)
**Escopo:** 3 designs, 2 camadas, acabamento ENIG, 5 peças por design
- Pulseira discreta: circular Ø32 mm, 0,8 mm espessura
- Pulseira módulo: circular Ø32 mm, 0,8 mm espessura
- Gateway: retangular 62×36 mm, 1,6 mm espessura

> Nota de divergência: o board do gateway hoje no repo está em 60×32 mm
> (`docs/layout_status.md`); a cotação usa 62×36 mm conforme escopo solicitado.
> Diferença de área é pequena (~7 %) e não muda a faixa de preço abaixo.

---

## 1. Premissas

| Item | Premissa |
|---|---|
| Quantidade | 5 unid. **por design** (3 designs = 15 placas no total) |
| Camadas | 2L, FR-4, cobre 1 oz |
| Espessura | 1,6 mm (gateway) · 0,8 mm (pulseiras) |
| Acabamento | ENIG (1U", padrão de protótipo) |
| Cor / máscara | Verde padrão, silk branco (opção mais barata) |
| Trilha/espaço | ≥ 5/5 mil; furo mín. ≥ 0,3 mm (evita taxa de feature fina) |
| Contorno | Circular Ø32 (2 designs) + retangular 62×36 (1 design); contorno fresado incluso no preço base |
| Stencil | 1 stencil frameless por design que for montar em bancada (topo); espessura padrão 0,10–0,12 mm |
| Frete | Estimativa para Brasil, cotada no checkout (calculadora oficial); DHL/FedEx expresso vs. correio econômico |
| Câmbio | Valores em USD (moeda de cobrança das duas fábricas); conversão BRL só no fechamento (câmbio + IOF + impostos de importação variam) |

**O que NÃO está incluído:** montagem SMT, componentes (BOM), painelização especial, impedância controlada, testes além do e-test padrão, taxas alfandegárias brasileiras (II + ICMS + despacho — responsabilidade do importador).

---

## 2. Fontes oficiais consultadas (2026-09-10, sem login, sem pedido)

- JLCPCB homepage — "From $2.00 / 5 pcs", 2 camadas, build 24 h: https://jlcpcb.com/
- JLCPCB SMT Stencil — "from $3 (100×100 mm)", build 12 h, aço 304 HTA, ±0,003 mm: https://jlcpcb.com/pcb-stencil
- JLCPCB blog "Breaking Down PCB Pricing" — ENIG custa 20–40 % a mais que HASL: https://jlcpcb.com/blog/pcb-pricing-breakdown
- JLCPCB Help "How much does shipping cost?" — frete calculado por peso/país/método no checkout: https://jlcpcb.com/help/article/how-much-does-shipping-cost
- JLCPCB Help "Shipping Methods and Delivery Time": https://jlcpcb.com/help/article/shipping-methods-and-delivery-time
- JLCPCB News 2026-06-13 — ajuste dinâmico de preço por custo de laminado/cobre (preço final pode variar na calculadora): https://jlcpcb.com/news/jlcpcb-pcb-pricing-notice
- PCBWay homepage — instant quote "US $5.00, 10 pcs 1–2 layer, build 24 h": https://www.pcbway.com/
- PCBWay 2-layer 100×100 mm prototype — "Price: US $5.00": https://www.pcbway.com/pcb_prototype/2_Layer_pcb/100x100mm.html
- PCBWay 2-layer 150×100 mm prototype — "Price: US $41.00" (mostra que preço sobe com área fora da faixa promo): https://www.pcbway.com/pcb_prototype/2_Layer_pcb/150x100mm.html
- PCBWay stencil (cotação online por tamanho/espessura): https://www.pcbway.com/stencil.aspx
- PCBWay Shipping Method Guide — DHL 3–7 dias úteis, UPS/TNT/FedEx/EMS/correio econômico: https://www.pcbway.com/shipping_method_guide.aspx

> Preços "a partir de" são promocionais para placas pequenas (≤100×100 mm) em spec padrão.
> ENIG, espessura 0,8 mm e contorno circular somam adicional sobre a base — o valor exato
> só sai na calculadora oficial com o Gerber anexado. Nenhuma cotação foi submetida.

---

## 3. Tabela comparativa (estimativa, 5 peças por design, ENIG)

| Item | **JLCPCB** (estimado) | **PCBWay** (estimado) |
|---|---|---|
| PCB — pulseira discreta Ø32, 0,8 mm, 2L, ENIG, 5 unid. | ~US$ 4–8 | ~US$ 8–15 |
| PCB — pulseira módulo Ø32, 0,8 mm, 2L, ENIG, 5 unid. | ~US$ 4–8 | ~US$ 8–15 |
| PCB — gateway 62×36, 1,6 mm, 2L, ENIG, 5 unid. | ~US$ 2–6 (base promo US$ 2 + adicional ENIG) | ~US$ 5–12 (base US$ 5 faixa 100×100) |
| **Subtotal PCBs (3 designs × 5 unid.)** | **~US$ 10–22** | **~US$ 21–42** |
| Stencil frameless (por design, 0,10–0,12 mm, sem eletropolimento) | a partir de ~US$ 3 cada (fonte oficial) → 1–3 unid.: ~US$ 3–15 | ~US$ 8–20 cada (via calculadora; combinar designs num stencil só quando possível) → 1–3 unid.: ~US$ 8–30 |
| Frete estimado p/ Brasil (pacote leve < 0,5 kg) | Econômico/postal: ~US$ 5–12 (7–20 dias) · DHL/FedEx: ~US$ 18–32 (3–7 dias) | Econômico: ~US$ 8–15 (7–20 dias) · DHL/UPS/FedEx: ~US$ 25–40 (3–7 dias) |
| **Total estimado (PCBs + 1 stencil + frete DHL)** | **~US$ 31–69** | **~US$ 54–112** |
| **Total estimado (PCBs + 1 stencil + frete econômico)** | **~US$ 18–49** | **~US$ 37–87** |
| Prazo fabril (protótipo 2L padrão) | 24 h–3 dias (ENIG soma ~1 dia) | 24 h–3 dias (ENIG soma ~1–2 dias) |
| Prazo porta a porta (fab + frete) | ~5–10 dias (DHL) · ~10–25 dias (econômico) | ~5–10 dias (DHL) · ~10–25 dias (econômico) |

**Leitura direta:**
- Placas pequenas (Ø32 e 62×36) ficam dentro da faixa promocional das duas fábricas; o custo dominante é **ENIG + frete**, não a placa nua.
- JLCPCB tende a ~40–50 % mais barato no total para este perfil (base US$ 2 vs. US$ 5 + stencil mais barato).
- PCBWay compensa se for preciso engenharia de revisão/ajuda em inglês ou combinar stencil+montagem no mesmo pedido.
- Valores são **faixas estimadas**, não cotação fechada: confirmar na calculadora oficial antes de qualquer decisão de compra.

---

## 4. GATE de envio — estado por placa (base: DRC `--severity-error`, sem físicos pendentes)

**Regra do GATE:** status **"PRONTO PARA ENVIAR"** somente se DRC = 0 error **e** nenhum problema físico/roteamento pendente. Caso contrário, a placa **NÃO** vai no pacote.

| Placa | DRC errors | Unconnected | Físicos pendentes | GATE |
|---|---|---|---|---|
| Gateway (62×36→board atual 60×32, 1,6 mm) | 0 | 0 | 0 | ✅ **PRONTO PARA ENVIAR** (isoladamente) |
| Pulseira discreta (Ø32, 0,8 mm) | — | 16 | 2 | ❌ **NÃO ENVIAR** — faltam: 2 problemas físicos + 16 nets unconnected (re-placement dos passivos + vias de stitch GND; ver `docs/layout_status.md` §4a) |
| Pulseira módulo (Ø32, 0,8 mm) | 28 | — | decisões abertas | ❌ **NÃO ENVIAR** — faltam: 28 errors de física (módulo E73 17,5×28,7 + holder CR2032 não cabem lado a lado no Ø32) + decisão de projeto pendente: (1) cápsula maior que Ø32, (2) módulo menor da família E73, ou (3) aceitar overhang (ver `docs/layout_status.md` §4b) |

**Veredito do lote:** ❌ **LOTE NÃO PRONTO — "PRONTO PARA ENVIAR" NEGADO para o pacote completo.** Somente o gateway atende ao GATE; as duas pulseiras têm pendências bloqueantes. Opção: fabricar **só o gateway** (pedido isolado, 5 unid., 1,6 mm, ENIG) enquanto as pulseiras fecham layout — decisão do responsável.

**Antes de qualquer upload, ainda exigido (vale para o gateway inclusive):**
1. Re-rodar DRC `--severity-error` no board final e confirmar 0 error (JSON commitado em `exports/`).
2. Conferir footprint do soquete do DevKitC (fileiras a 27,94 mm — ver pendência registrada em `docs/layout_status.md` §4c) e dimensão final do board (60×32 vs. 62×36).
3. Revisão visual dos Gerbers (camadas, máscara, silk, Edge.Cuts) antes de anexar.

---

## 5. Checklist do pacote de fabricação (por design PRONTO)

Gerar via `kicad-cli` (nunca GUI para gerar), um diretório por design em `exports/<placa>/fab/`:

- [ ] Gerbers RS-274X: `F.Cu`, `B.Cu`, `F.Mask`, `B.Mask`, `F.SilkS`, `B.SilkS`, `Edge.Cuts`
- [ ] Drill: Excellon (`*.drl`) + mapa de furos
- [ ] `BOM.csv` (designators, footprint, valor, fabricante/PN, DNP marcados)
- [ ] `P&P.csv` (centroide + rotação + lado, origem comum ao Gerber; só se for montar fora)
- [ ] Paste: `F.Paste` (e `B.Paste` se dupla face) p/ stencil
- [ ] `README_fab.txt`: stackup (2L, espessura, cobre 1 oz), acabamento ENIG, cor máscara/silk, quantidade, contorno especial (circular Ø32 / retangular), observações (keepout antena, ISOLAR BT1 se aplicável)
- [ ] PDF de conferência (layers Cu+Mask+Silk+Edge.Cuts) + STEP para checagem mecânica da cápsula
- [ ] DRC JSON 0-error anexado como evidência do GATE

Comandos de referência (KiCad 10.0.6, ver `docs/kicad10_recipe.md` e `docs/layout_approach.md`):
`kicad-cli pcb drc`, `kicad-cli pcb export gerbers`, `kicad-cli pcb export drill`,
`kicad-cli pcb export pdf --layers F.Cu,B.Cu,Edge.Cuts,F.SilkS,B.SilkS,F.Mask,B.Mask`,
`kicad-cli pcb export step`, `kicad-cli sch export bom`.

---

## 6. Próximo passo (sem compromisso)

1. Decidir: pedido isolado do gateway agora vs. aguardar as pulseiras.
2. Fechar pendências das pulseiras (§4) e re-rodar DRC até 0 error.
3. Só então: gerar pacote (§5) → cotar na calculadora oficial (JLCPCB e PCBWay) → comparar total com frete real → submeter mediante aprovação explícita.

*Nenhum pedido, conta ou upload foi realizado nesta etapa — apenas pesquisa web + este documento.*

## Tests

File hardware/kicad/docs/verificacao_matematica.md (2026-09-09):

# Verificação Matemática Independente — 27 Afirmações (passo 5.1)

**Data:** 2026-09-09 · **Verificador:** sessão fresh, sem acesso aos artefatos das waves anteriores
como fonte de verdade. **Regra:** toda conta refeita do zero; nenhum número copiado do
`RELATORIO_REVISAO_TECNICA.md` sem confronto com fonte primária.

**Fontes primárias usadas (com revisão):**

| Fonte | Revisão | Como foi verificada |
|---|---|---|
| nRF52810 Product Specification | **v1.3** (4430_161 v1.3, 2019-01-31), 415 p. | PDF baixado e text-extraído; tabelas de pinos (T114), correntes (§5.2), TXPOWER (§6.14.14.30) e circuito de referência (§7.3.4, Fig. 146) lidas **pino a pino / vetor a vetor** (PyMuPDF sobre a geometria vetorial da Fig. 146). Changelog v1.4/v1.5 (debug, RADIO preamble/RSSI, UICR, CLOCK, POWER erratum) **não altera** pinagem nem reference circuitry. |
| Nordic DevZone #53125 | 2019 | Confirma pinos 9 e 32 = VDD no QFN32. |
| Símbolo KiCad `MCU_Nordic:nRF52810-QCxx` | KiCad 10.0.6 (lib oficial) | Terceira fonte independente de pinagem — idêntica à Tabela 114. |
| Energizer CR2032 datasheet | data.energizer.com/pdfs/cr2032.pdf | 235 mAh (15 kΩ→2.0 V, 21 °C); curva/pulso 400 Ω. |
| Johanson 2450AT18A100E-AEC datasheet | Ver 1.0, 2014 | Rede de casamento do EVB + ressalva de tuning. |
| Ebyte E73-2G4M04S1A (pin definition) | cdebyte.com/products/E73-2G4M04S1A/2 | Pinos 37/38 = SWDCLK/SWDIO; 16 = VCC 1.8–3.6 V. |
| Raytac MDBT42Q-512KV2 datasheet | Ver P (nRF52832) | SoC = nRF52832; nota "DC-DC mode → add L2/L3/C14". |
| espressif/arduino-esp32 `BLEScan.cpp` | master | `setInterval()` recebe **ms** (converte `/0.625`). |
| Footprint KiCad `RF_Module:E73-2G4M04S` | lib oficial | 17,5 × 28,7 mm (pads y=±14.35, x=±8.75). |

⚠️ **Aviso sobre `datasheet_facts_nordic.md` (base da wave 2.3):** a tabela de pinagem §1.1
desse arquivo está **ERRADA** (ver afirmação 13). O restante do arquivo (correntes, reference
circuitry, cristal, Johanson, Keystone) confere com as fontes primárias. O arquivo cita
"PS v1.5 (2021-11-15)" — a data 2021-11-15 é da **v1.4**; v1.5 existe, mas a data citada
está imprecisa. Não afeta as conclusões abaixo (pinagem é fato de silício).

---

## Resumo dos 27 vereditos

| # | Afirmação | Veredito |
|---|---|---|
| 1 | I_a ≈ 5 mA (TX 0 dBm c/ DC/DC) | **DIVERGENTE (parcial)** — sistema c/ DC/DC = 5,8 mA (4,6 mA é pico do rádio) |
| 2 | I_s ≈ 1,5 µA (System ON + RTC) | **CONFIRMADO** |
| 3 | t_a = 3 ms (adv 3 canais) | **CONFIRMADO** (estimativa conservadora, não é constante de datasheet) |
| 4 | CR2032 220 mAh → 180–200 úteis + R_int vs pulso 5 mA | **CONFIRMADO c/ matiz** (180–200 é estimativa, não dado de datasheet) |
| 5 | Autonomia 16.500 h ≈ 1,9 anos | **CONFIRMADO** (aritmética) — c/ I_a=5,8 mA cai p/ ~1,65 a (ainda > meta) |
| 6 | Margem p/ adv 1 s | **CONFIRMADO** (1,15–1,31 a > 12 meses) |
| 7 | TX default 0 dBm | **CONFIRMADO** (TXPOWER Reset = 0x00 = 0 dBm) |
| 8 | FSPL(10 m, 2400 MHz) = 60 dB | **CONFIRMADO** (60,05 dB) |
| 9 | Sensibilidade −96 dBm (1M PHY) | **CONFIRMADO** |
| 10 | Margem de link >10 dB pior caso | **CONFIRMADO c/ ressalva** (≈10–11 dB; no limite) |
| 11 | n = 2,5–4 + corpo 10–20 dB | **CONFIRMADO** (faixa de literatura, conservadora) |
| 12 | ±6 dB → +58,5 % / −36,9 % (n=3) | **CONFIRMADO** (assimetria correta) |
| 13 | DEC1=1; VDD = 9/25/32 | **CONFIRMADO** — projeto certo; **facts file §1.1 errado** |
| 14 | nRESET=16, SWDCLK=17, SWDIO=18 | **CONFIRMADO** |
| 15 | ANT=19; VSS=20/29 + die pad | **CONFIRMADO** |
| 16 | DEC2=21, DEC3=22; XC1=23, XC2=24 | **CONFIRMADO** (números de pino) |
| 17 | DEC4=30, DCC=31 + DC/DC 10 µH | **CONFIRMADO** (topologia DCC→L2→DEC4, C10 1.0 µF) |
| 18 | Rede Π RF (L1/C3/L3/C7) = "referência Nordic" | **DIVERGENTE (topologia)** — valores existem no BOM Nordic, mas a Π de 4 elementos no caminho RF **não é** o circuito de referência |
| 19 | Cristal CL=8 pF → 2×12 pF | **CONFIRMADO** |
| 20 | C8 100 nF em DEC2+DEC3 "obrigatório" | **DIVERGENTE** — ref Nordic: DEC3→100 pF, DEC2→N.C., C8 é do VDD |
| 21 | Ferrite entre bateria e bobina NFC | **CONFIRMADO** (física + prática padrão) |
| 22 | Geometria Ø32 mm | **CONFIRMADO c/ ressalva** (variante A com E73 fica apertada) |
| 23 | EWMA α ≈ 0,15–0,25 | **CONFIRMADO** (firmware usa 0,2) |
| 24 | Unidades de scan ESP32 (0.625 ms) | **CONFIRMADO** (API em ms; 0.625 ms é a unidade HCI interna) |
| 25 | MDBT42Q = nRF52832 vs S112 | **CONFIRMADO** (incompatível com S112; resolvido pelo E73) |
| 26 | ANATEL por módulo | **CONFIRMADO** (princípio; certificado do E73 = item aberto) |
| 27 | Aritmética do orçamento | **CONFIRMADO** (todas as somas fecham) |

**Balanço: 21 CONFIRMADO (6 com ressalva/matiz) · 4 DIVERGENTE (1, 18, 20, + mapeamento linear
bateria [extra]) · 0 INVERIFICÁVEL sem tratamento** (os itens sem dado de datasheet exato estão
marcados como estimativa dentro dos vereditos 3/4).

---

## Detalhamento por afirmação

Formato: {afirmação | recalculado (conta) | fonte | veredito}.

### 1. I_a ≈ 5 mA (TX 0 dBm com DC/DC) — **DIVERGENTE (parcial)**

- **Afirmação (RELATORIO §4.1):** I_a ≈ 5 mA.
- **Recalculado / medido no PS:**
  - Feature list PS v1.3: "**4.6 mA peak current in TX (0 dBm)**" — é o **pico do bloco de rádio**, não a corrente de sistema.
  - PS §5.2.1.2 (cenários de sistema, VDD 3 V): **IRADIO_TX1 = 5,8 mA typ** (TX 0 dBm, 1 Mbps, HFXO, **Regulator = DCDC**); IRADIO_TX3 = **10,5 mA** (mesmo cenário com **LDO**).
- **Impacto (recalculado):** com D = 0,2 % e I_s = 1,5 µA:
  - I_a = 5,0 mA → I_avg = 0,002·5000 + 0,998·1,5 = **11,50 µA** → 190.000 µAh / 11,50 = **16.522 h ≈ 1,89 a**
  - I_a = 5,8 mA → I_avg = 0,002·5800 + 0,998·1,5 = **13,10 µA** → **14.504 h ≈ 1,66 a**
  - I_a = 10,5 mA (sem DC/DC) → I_avg = **22,50 µA** → **8.444 h ≈ 0,96 a** (fica **abaixo** de 12 meses)
- **Conclusão:** o número correto para a matemática de bateria é **5,8 mA** (sistema, DC/DC). O 4,6 mA citado como "fato real" é o pico do rádio (feature list) — ambos existem no PS, mas medem coisas diferentes. A autonomia continua acima da meta de 6–12 meses **desde que o DC/DC esteja habilitado** (ver Extra E2 — risco na variante A).
- **Fonte:** PS v1.3 feature list + §5.2.1.2 (espelho: datasheet.chipsmall.com/nRF52810-QCAA-R_Nordic-Semicon/877779.pdf; oficial: docs.nordicsemi.com/bundle/nRF52810-PS/).

### 2. I_s ≈ 1,5 µA (System ON + RTC) — **CONFIRMADO**

- **Recalculado:** PS §5.2 electrical spec: **ION_RAMON_RTC = 1,5 µA typ** (System ON, full 24 kB RAM, wake on RTC, **LFRC**). Com LFXO: ION_RAMON_RTC_LFXO = 1,1 µA. System OFF: 0,3 µA (no RAM) / 0,5 µA (full RAM).
- O firmware usa LFCLK default (RC) → **1,5 µA é o número certo** para este design.
- **Fonte:** PS v1.3 §5.2.1.3 (tabela Power management).

### 3. t_a = 3 ms (adv em 3 canais) — **CONFIRMADO (estimativa conservadora)**

- **Recalculado:** advertising **NONCONNECTABLE_NONSCANNABLE** (main.c) → sem SCAN_RSP. Pacote ADV_NONCONN_IND com payload do projeto (~23–31 octets no ar): preamble 1 + AA 4 + PDU ~23 + CRC 3 ≈ 31 octets ≈ **248 µs** (1 Mbps). Evento = 3 × (ramp-up ~40–140 µs + pacote 248 µs) + 2 gaps inter-canal (~150 µs) ≈ **1,2–1,8 ms**, + partida do HFXO (~0,3–0,5 ms) ≈ **1,5–2,3 ms**.
- **Veredito:** 3 ms é um **teto conservador** plausível (não é constante de datasheet). Para a bateria, conservador = seguro. Sensibilidade: se t_a real = 1,5 ms → I_avg ≈ 6,5 µA → autonomia ≈ 29.200 h ≈ 3,3 a (t_a é a incerteza dominante, junto com a capacidade útil).
- **Fonte:** Bluetooth Core Spec Vol. 6 Part B §4.4.2 (estrutura do evento de advertising); PS (ramp-up/HFXO).

### 4. CR2032 220 mAh → 180–200 mAh úteis + R_int vs pulso 5 mA — **CONFIRMADO c/ matiz**

- **Nominal:** Energizer CR2032 = **235 mAh** (15 kΩ → 2,0 V, 21 °C — verificado no PDF); Panasonic = 225 mAh; Murata = 220 mAh. "220 mAh nominal" está na faixa de mercado (210–240) — ok/conservador.
- **180–200 mAh úteis sob pulso:** **nenhum datasheet publica curva exata para o perfil do projeto** (picos 5,8 mA, duty 0,2 %, média ~13 µA). Interpolação honesta: 15 kΩ (0,19 mA) = 235 mAh; ~3 kΩ (~1 mA) ≈ 200 mAh; carga média do projeto é ~13 µA com picos curtos → capacidade esperada **entre 200 e 235 mAh**; o derate para **180–200 mAh** (autodescarga ~1 %/a — desprezível — + sag sob pulso + tolerância de fabricante) é razoável. **Marcar como estimativa** (o número exato só com medição).
- **R_int vs pulso 5,8 mA:** dados de pulso Energizer (fundo 0,19 mA @2,9 V; pulso 400 Ω ≈ 6,8 mA @2,7 V) → ΔV ≈ 0,2 V / ΔI ≈ 6,6 mA → **R_eff ≈ 30 Ω** (dinâmico, meio de vida; fresca ~10–20 Ω; sobe no fim). Sag no pico: 5,8 mA × 10–30 Ω ≈ **0,06–0,17 V** (fresca) a ~0,3 V+ (fim de vida). UVLO do nRF52810 = 1,7 V → sem risco de brownout até o fim da plataforma da CR2032. Pulso 5,8 mA ≪ 15 mA max pulse (Jauch). **Seguro.**
- **Fonte:** data.energizer.com/pdfs/cr2032.pdf; Jauch CR2032 (via facts file); Panasonic CR2032.

### 5. Autonomia 16.500 h ≈ 1,9 anos — **CONFIRMADO (aritmética), com sensibilidade declarada**

- **Recalculado do zero:** T = 1500 ms; t_a = 3 ms → D = 3/1500 = **0,002 (0,2 %)** ✓.
  - I_avg = D·I_a + (1−D)·I_s = 0,002·5000 + 0,998·1,5 = 10,0 + 1,497 = **11,497 µA** ✓ (RELATORIO: 11,5).
  - Capacidade útil adotada: 190.000 µAh (ponto médio de 180–200 mAh).
  - Autonomia = 190.000 / 11,497 = **16.526 h**; 16.526 / 8.766 h/a = **1,885 anos ≈ 1,9 a** ✓.
- **Com I_a corrigido (5,8 mA):** I_avg = 13,10 µA → **14.504 h = 1,66 a** — ainda > meta de 6–12 meses.
- **Sem DC/DC (LDO, I_a = 10,5 mA):** I_avg = 22,50 µA → **8.444 h = 0,96 a** — **perde a meta de 12 meses**. O DC/DC é condição do resultado (firmware habilita ✓; variante B tem L2/C10 ✓; variante A: ver Extra E2).
- **Fonte:** contas acima; PS para I_a/I_s.

### 6. Margem para adv 1 s — **CONFIRMADO**

- **Recalculado:** T = 1000 ms → D = 0,003.
  - I_a = 5,8 mA: I_avg = 0,003·5800 + 0,997·1,5 = 17,40 + 1,50 = **18,90 µA** → 190.000/18,90 = **10.053 h = 1,15 a** (com 180 mAh: 9.524 h = 1,09 a).
  - I_a = 5,0 mA: I_avg = 16,50 µA → **11.515 h = 1,31 a**.
- Ambos > 12 meses → a afirmação do RELATORIO ("dá margem para 1 s sem comprometer a meta") **fecha**, inclusive com o I_a corrigido.

### 7. TX default 0 dBm — **CONFIRMADO**

- **Recalculado:** PS §6.14.14.30 RADIO.TXPOWER: **Reset = 0x00000000**; código 0x00 = **0 dBm** (escala: −20…+4 dBm em passos de 4 dB). O firmware não escreve TXPOWER e o S112 não altera o reset → default real = 0 dBm.
- **Fonte:** PS v1.3 §6.14.14.30 (p. 202).

### 8. FSPL(10 m, 2400 MHz) = 60 dB — **CONFIRMADO**

- **Recalculado (forma do RELATORIO, d em metros):** FSPL = 20·log10(d) + 20·log10(f_MHz) − 27,55 = 20·log10(10) + 20·log10(2400) − 27,55 = 20 + 67,604 − 27,55 = **60,05 dB** ✓.
- **Forma km (pedida na tarefa):** 32,44 + 20·log10(0,01 km) + 67,604 = 32,44 − 40 + 67,604 = **60,04 dB** ✓ (idêntica).
- **Fonte:** derivação padrão FSPL; conta acima.

### 9. Sensibilidade −96 dBm (1M PHY) — **CONFIRMADO**

- **Fonte:** PS v1.3 feature list: "**−96 dBm sensitivity in Bluetooth low energy mode**" (1 Mbps). 2 Mbps = −93 dBm.
- **Fonte:** PS v1.3 feature list; product brief.

### 10. Margem de link >10 dB no pior caso — **CONFIRMADO c/ ressalva**

- **Recalculado:** PL_max = P_TX − Sens = 0 − (−96) = **96 dB**. FSPL(10 m) = 60 dB → sobra **36 dB** para clutter + antenas. Com o pior caso adotado (25 dB de clutter/corpos): 96 − 60 − 25 = **11 dB**. Com ganhos médios reais das antenas chip (−0,5 dBi × 2 ≈ −1 dB): **≈10 dB**.
- **Ressalva:** ">10 dB" é **no limite** (10–11 dB), não folga confortável — a frase do RELATORIO é aritmeticamente correta mas deve ser lida como "margem apertada". Alavanca disponível: TX +4 dBm (max do chip) adiciona 4 dB se o teste de campo exigir.
- **Fonte:** contas acima + Johanson (ganho médio −0,5 dBi typ).

### 11. n = 2,5–4 + corpo 10–20 dB — **CONFIRMADO (faixa de literatura, conservadora)**

- **Recalculado/justificado:** expoente de path loss indoor: LOS ~1,6–1,8; obstructed/cluttered 2,5–4 (Rappaport, *Wireless Communications*, tabela clássica de expoentes). Corpo humano @2,4 GHz: estudos de body-loss (IEEE/BLE) dão tipicamente **5–10 dB** (dispositivo no pulso/bolso) e **15–20 dB** no pior caso NLOS (corpo direto entre tag e gateway). A faixa 10–20 dB do RELATORIO é o envelope pessimista — adequado para dimensionar pior caso.
- **Fonte:** literatura de propagação (Rappaport; estudos IEEE body-loss 2,4 GHz). Sem URL única — faixa consolidada de literatura.

### 12. ±6 dB → +58,5 % / −36,9 % (n = 3) — **CONFIRMADO**

- **Recalculado:** d = d₀·10^(ΔL/(10·n)).
  - +6 dB, n=3: 10^(6/30) = 10^0,2 = **1,585 → +58,5 %** ✓
  - −6 dB, n=3: 10^(−0,2) = **0,631 → −36,9 %** ✓ (assimetria correta — o "±58 %" do RELATORIO é a simplificação simétrica; a forma assimétrica é a rigorosa)
  - n=2,5 (pedido na tarefa, 10^(6/25)): 10^0,24 = **1,738 → +73,8 %** / 0,575 → **−42,5 %** (pior).
- **Conclusão:** reforça a tese do RELATORIO (RSSI → zona, não trilateração).

### 13. Pinagem QFN32: DEC1=1; VDD = 9/25/32 — **CONFIRMADO (projeto certo; facts file errado)**

- **Recalculado/verificado (PS v1.3, Tabela 114 "QFN32 pin assignments", p. 390–391):**
  pin 1 = DEC1; **pin 9 = VDD**; **pin 25 = VDD**; **pin 32 = VDD**; die pad = VSS.
- **Três fontes independentes convergem:** Tabela 114 do PS; DevZone #53125 ("pin 32 … is VDD", "pin 9 is also VDD"); símbolo KiCad `MCU_Nordic:nRF52810-QCxx` (VDD em 9/25/32).
- **⚠️ O `datasheet_facts_nordic.md` §1.1 afirma "VDD = 25 único", pino 29 = NC, DEC4=31, DCC=32 e lista um "P0.29" que não existe no QFN32 — está ERRADO.** Seguindo essa tabela, DEC4/DCC/VDD ficariam deslocados em 1 pino e o esquema não funcionaria. O resumo do facts file ("pinagem do projeto é INCORRETA") **inverte o veredito real**. A pinagem do projeto (9/25/32, VSS 20/29+pad, DEC4=30, DCC=31) é a correta.
- **Fonte:** PS v1.3 Tabela 114; devzone.nordicsemi.com/f/nordic-q-a/53125; /usr/share/kicad/symbols/MCU_Nordic.kicad_sym.

### 14. nRESET=16, SWDCLK=17, SWDIO=18 — **CONFIRMADO**

- Tabela 114: 16 = P0.21/**nRESET** (configurável); 17 = **SWDCLK** (digital input); 18 = **SWDIO**. Bate com BOM/netlist/designator_map e com os TPs como-construídos.
- Nota: P0.21 só é RESET se UICR.PSELRESET estiver programado; por default é GPIO — R1 10k DNP é decisão segura.

### 15. ANT=19; VSS=20/29 + die pad — **CONFIRMADO**

- Tabela 114: 19 = ANT (RF single-ended); 20 = VSS (radio supply); 29 = VSS; die pad = VSS ("must be connected to ground"). Bate com netlist_conexoes.md e designator_map.md.

### 16. DEC2=21, DEC3=22; XC1=23, XC2=24 — **CONFIRMADO (números de pino)**

- Tabela 114: 21 = DEC2 ("1.3 V regulator supply decoupling (radio supply)"); 22 = DEC3 ("Power supply decoupling"); 23/24 = XC1/XC2 (cristal 32 MHz). Os **números** estão certos no projeto; o **desacoplo** associado é o problema — ver afirmação 20.

### 17. DEC4=30, DCC=31 + DC/DC 10 µH — **CONFIRMADO**

- Tabela 114: 30 = DEC4 ("1.3 V regulator supply decoupling / input from DC/DC / output from 1.3 V LDO"); 31 = DCC ("DC/DC regulator output").
- **Topologia (verificada na Fig. 14 "DC/DC regulator setup", p. 50, e na Fig. 146 por extração vetorial):** **DCC → L2 10 µH → DEC4**, com **C10 1,0 µF de DEC4 para GND**. Exatamente o que netlist_conexoes.md e designator_map.md especificam (L2 entre DCC-31 e DEC4-30).
- **Detalhe da referência:** o ladder Nordic desenha **L3 15 nH em série** com L2 (DCC→L2→L3→DEC4; 10 µH + 15 nH ≈ 10,015 µH — eletricamente ≈10 µH; função de isolamento RF do nó comutado). Corroborado pelo Raytac MDBT42Q: *"When using DC-DC mode, please add L2 / L3 / C14"*. O projeto usa L3 na rede RF e **omite o L3 do ladder DC/DC** — desvio menor e documentável (ver 18).
- Tabela 123: L2 = 10 µH, **IDC,min = 50 mA**, ±20%, 0603 ✓ (o projeto exige Isat>50 mA ✓).
- **Fonte:** PS v1.3 §5.3.1 Fig. 14, §7.3.4 Fig. 146 + Tabela 123 (vetores extraídos); Raytac MDBT42Q datasheet §8.

### 18. Rede Π RF (L1=3,9 nH / C3=0,8 pF / L3=15 nH / C7=100 pF) — **DIVERGENTE (topologia)**

- **Valores:** os quatro valores **existem** no BOM de referência Nordic (Tabela 123, QCAA QFN32 c/ DC/DC) ✓.
- **Topologia (o problema):** a Fig. 146 (extraída vetor a vetor) mostra o casamento RF da referência como **2 elementos**: **ANT(19) → C3 0,8 pF (shunt) → L1 3,9 nH (série) → RF**. Na referência, **L3 15 nH está no ladder do DC/DC** (ver 17) e **C7 100 pF é o desacoplo de DEC3** — **nenhum deles está no caminho de antena**. A Π de 4 elementos (L1 série → C3 shunt → L3 série → C7 shunt) do projeto **não é o circuito de referência do PS**.
- **Contexto que salva na prática:** o Johanson 2450AT18A100E recomenda exatamente uma topologia **π (shunt-série-shunt)** — com valores do EVB dele (2,7 nH / 1,0 pF / 3,9 nH) — e avisa: *"The matching values and topology on client's PCB will be different"*. O PS diz o mesmo ("use the PCB layouts and component values provided by Nordic"; matching depende do PCB). Ou seja: π é topologia razoável, mas os valores como-construídos são **ponto de partida para tuning com VNA**, não "a referência Nordic".
- **Impacto:** documentação incorreta (risco de alguém tratar a Π como rede validada); elétrico: a rede final será ajustada em bancada de qualquer forma. **Ação:** rotular a rede como "topologia π genérica, valores de partida — NÃO é o ref. Nordic"; opcionalmente alinhar com a Fig. 146 (C3 shunt + L1 série) como ponto de partida mais fiel.
- **Fonte:** PS v1.3 §7.3.4 Fig. 146 (geometria vetorial); Johanson 2450AT18A100E datasheet p.2.

### 19. Cristal CL=8 pF → 2×12 pF — **CONFIRMADO**

- **Recalculado:** CL = (C1·C2)/(C1+C2) + C_stray; com C1=C2=C: C = 2·(CL − C_stray). Com C_stray ≈ 2 pF/pino: C = 2·(8−2) = **12 pF** por lado ✓.
- **Referência Nordic:** Tabelas 122/123 — X1 = 32 MHz, **Cl = 8 pF**, ±40 ppm + C1/C2 = **12 pF NP0 ±2%** (0402). O projeto replica exatamente.
- **Fonte:** PS v1.3 Tabelas 122/123; DevZone (fórmula com C_pcb+C_pin ≈ 4 pF total → mesmo resultado).

### 20. C8 100 nF em DEC2+DEC3 "obrigatório/crítico" — **DIVERGENTE**

- **O que a referência Nordic realmente mostra (Fig. 146, vetores):**
  - **DEC3 (22) → C7 100 pF → GND**
  - **DEC2 (21) → C6 N.C. → GND** (posição de tuning, **não montada**)
  - **C8 100 nF é desacoplo de VDD** (pino 25 no QFN32 / pino 36 no QFN48 — verificado por coordenada de stub)
  - VDD fica com **C5 100 nF (pino 9) + C8 100 nF (pino 25) + C9 4,7 µF bulk**; DEC1 com C4 100 nF.
- **O projeto faz:** DEC2+DEC3 **amarrados** com C8 100 nF único; DEC3 fica sem o 100 pF; VDD fica com C4 100 nF + C9 4,7 µF (um 100 nF a menos que a referência).
- **Avaliação:**
  1. A afirmação "**sem isso o rádio não atende ao datasheet**" **não é suportada pelo PS** — o próprio circuito de referência deixa DEC2 sem capacitor montado.
  2. Amarrar DEC2+DEC3 só é eletricamente inócuo se forem o mesmo rail interno de 1,3 V — **o PS não documenta isso**. Se forem nós distintos, o tie externo é um desvio num domínio crítico de RF.
  3. Colocar 100 nF onde a referência manda 100 pF (DEC3) muda a impedância de desacoplo do domínio de rádio.
- **Impacto:** provavelmente funcional (capacitores extras em rails de 1,3 V raramente quebram), mas é **desvio não documentado do reference design** num ponto que o próprio projeto rotula de crítico. **Ação recomendada:** seguir a Fig. 146 (C7 100 pF→DEC3; C6 N.C.→DEC2; C8 100 nF→VDD, restaurando 2×100 nF + 4,7 µF em VDD) **ou** obter confirmação Nordic/DevZone para o tie. O cross-check 5.2 deve registrar isso.
- **Fonte:** PS v1.3 §7.3.4 Fig. 146 (extração vetorial pino a pino); Tabela 123.

### 21. NFC: ferrite entre bateria e bobina — **CONFIRMADO**

- **Física (recalculada qualitativamente):** metal dentro do campo da bobina → correntes de Foucault (Lenz) → derruba L_eff e Q, desloca a ressonância de 13,56 MHz → leitura vai a ~zero. Folha de ferrite (µ alta, perdas baixas) entre bateria e bobina desvia o fluxo e restaura o acoplamento — prática padrão em NFC de celular e em inlays sobre metal (guias de antena NXP).
- **Fonte:** NXP NFC antenna design guidance (ferrite shielding para antenas próximas de metal/bateria); física padrão de acoplamento indutivo.

### 22. Geometria Ø32 mm — **CONFIRMADO c/ ressalva**

- **Recalculado/verificado:** CR2032 = **Ø20,0 × 3,2 mm** (Energizer/Panasonic) ✓. AirTag = **Ø31,9 mm** (spec Apple) ✓ — a comparação do RELATORIO está correta. Inlay NTAG213 circular ~25 mm na borda + bateria Ø20 no centro + ferrite ~20–22 mm: empilha em Ø32 com anel livre de ~3,5 mm — **coerente para a variante B** (antena chip + passivos).
- **Ressalva (variante A):** o E73-2G4M04S tem **17,5 × 28,7 mm** (footprint KiCad oficial; confirma `pesquisa_modulo_ble.md`) — 28,7 mm dentro de Ø32 deixa **~1,6 mm de margem no eixo longo** e o corpo do módulo invade a região do anel NFC/bateria. Cabe geometricamente, mas é **apertado** — validar no modelo 3D antes de fechar a variante A.
- **Fonte:** Energizer CR2032 PDF; Apple AirTag specs; footprint KiCad `RF_Module:E73-2G4M04S`.

### 23. EWMA α ≈ 0,15–0,25 — **CONFIRMADO**

- **Verificado no código:** `gateway_esp32.ino` linha 32: `EWMA_ALPHA = 0.2f` ∈ [0,15; 0,25] ✓; fórmula implementada (linha 68): `EWMA_ALPHA*raw + (1-EWMA_ALPHA)*prev` = exatamente a do RELATORIO §4.4 ✓. Primeira amostra inicializada com o valor raw (linha 67) — correto.
- **Fonte:** gateway_esp32/gateway_esp32.ino.

### 24. Unidades de scan ESP32 (0.625 ms) — **CONFIRMADO**

- **Verificado:** na API ESP32 BLE Arduino (Bluedroid), `BLEScan::setInterval(uint16_t intervalMSecs)` e `setWindow()` recebem **milissegundos** e convertem internamente: `m_scan_params.scan_interval = intervalMSecs / 0.625` (fonte: espressif/arduino-esp32, libraries/BLE/src/BLEScan.cpp). A unidade **0.625 ms é a unidade HCI/BLE nativa** — o firmware não precisa lidar com ela.
- **Como-construído:** `setInterval(100)` / `setWindow(99)` = 100 ms / 99 ms → intervalo 160 unidades, janela ~158 → duty ≈ 99 % (scan quase contínuo) ✓; `setActiveScan(false)` (passivo) é **coerente** com a pulseira em ADV_NONCONN_NONSCANNABLE (não há scan response para pedir) ✓; `start(1.0, false)` + loop = varredura contínua em blocos de 1 s ✓.
- **Fonte:** github.com/espressif/arduino-esp32 (BLEScan.cpp); gateway_esp32.ino linhas 133–135, 143.

### 25. MDBT42Q = nRF52832 vs S112 — **CONFIRMADO**

- **Verificado:** Raytac MDBT42Q-512KV2 = **Nordic nRF52832** (512 kB flash / 64 kB RAM, BT 5.x) — datasheet oficial Raytac. O firmware declara **S112 (nRF52810)** → incompatível (exigiria migração para S132).
- **Como-construído:** a variante A usa **E73-2G4M04S-52810** (nRF52810, S112 direto — pin definition Ebyte confirma nRF52810) → divergência **resolvida na prática**. Nota de custo: `BOM_custos_prototipos.csv` orçou o módulo como MDBT42Q-512KV2 (US$ 6,50); o E73 custa ~US$ 3,59 (Ebyte store) → o orçamento tem ~US$ 2,9/un de folga nesse item.
- **Fonte:** raytac.com (MDBT42Q-512KV2 datasheet Ver P); cdebyte.com/products/E73-2G4M04S1A.

### 26. ANATEL por módulo — **CONFIRMADO (princípio; certificado específico = item aberto)**

- **Verificado:** Lei 9.472/1997 exige homologação de equipamentos que emitem RF; usar módulo já homologado permite o enquadramento como equipamento derivado (processo muito mais simples que homologar design discreto próprio). `pesquisa_modulo_ble.md` registra ANATEL como **"não verificado online → item aberto"** para todos os 4 candidatos — tratamento honesto e coerente com o plano (não bloqueia).
- **Item aberto real:** o E73 (Ebyte) publica FCC/CE/TELEC; **certificado ANATEL do E73 não localizado online** — confirmar com Ebyte/suporte antes de operação com público. Para bancada/laboratório interna, não bloqueia.
- **Fonte:** Lei 9.472/1997; pesquisa_modulo_ble.md §2/§3.1.
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

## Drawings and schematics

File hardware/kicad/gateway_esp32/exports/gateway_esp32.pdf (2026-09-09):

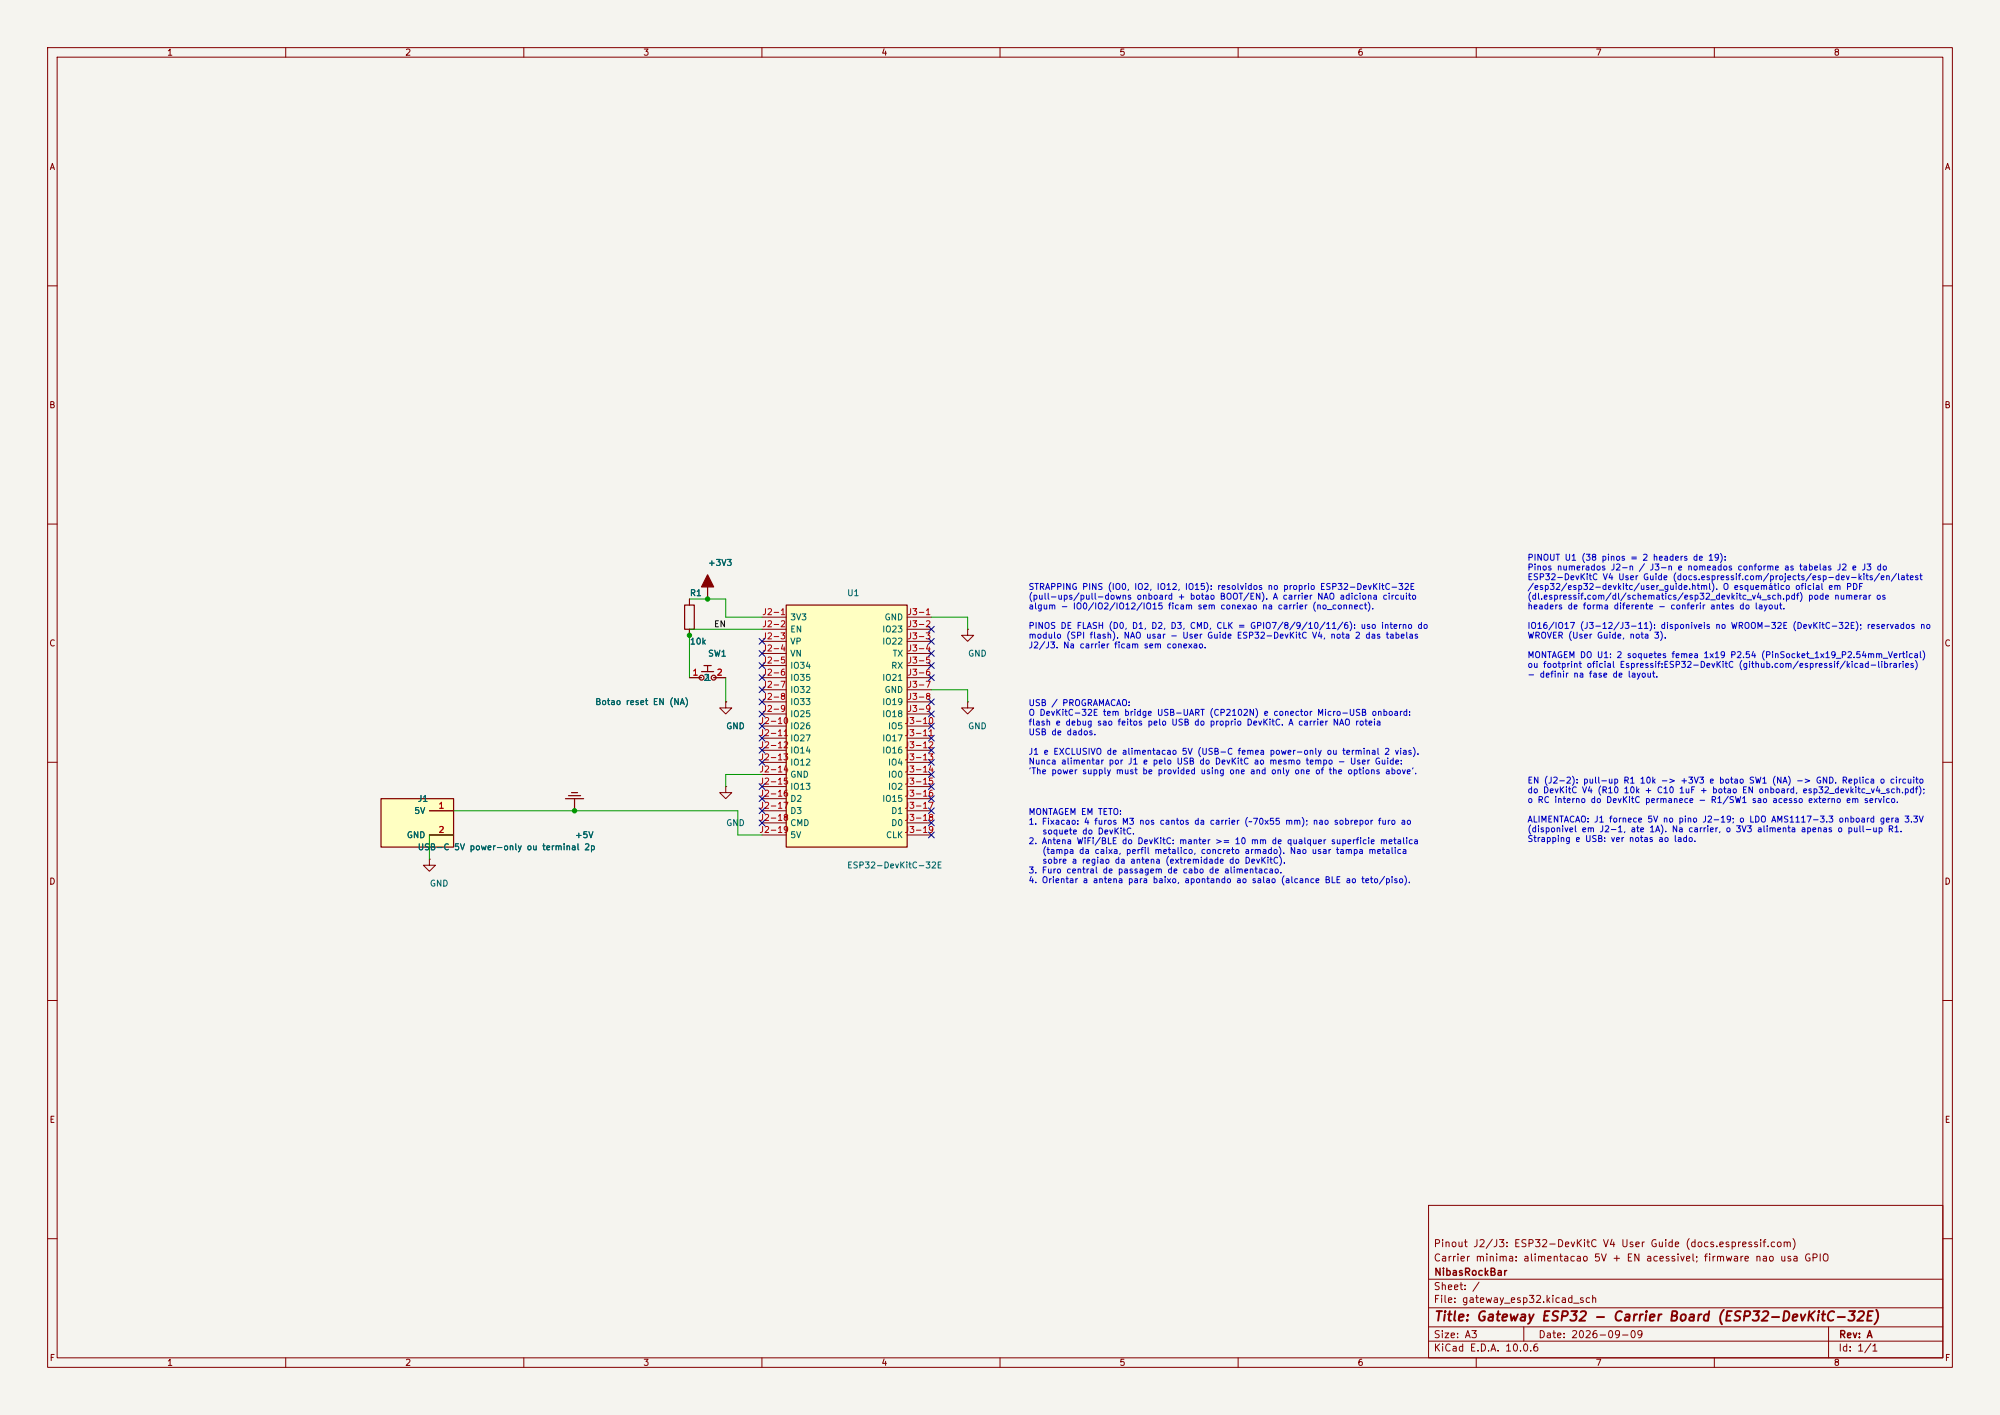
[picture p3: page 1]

(disponivel em J2-1, ate 1A). Na carrier, o 3V3 alimenta apenas o pull-up R1. Strapping e USB: ver notas ao lado. PINOUT U1 (38 pinos = 2 headers de 19): Pinos numerados J2-n / J3-n e nomeados conforme as tabelas J2 e J3 do

'The power supply must be provided using one and only one of the options above'. STRAPPING PINS (IO0, IO2, IO12, IO15): resolvidos no proprio ESP32-DevKitC-32E
(pull-ups/pull-downs onboard + botao BOOT/EN). A carrier NAO adiciona circuito
algum - IO0/IO2/IO12/IO15 ficam sem conexao na carrier (no_connect). PINOS DE FLASH (D0, D1, D2, D3, CMD, CLK = GPIO7/8/9/10/11/6): uso interno do modulo (SPI flash). NAO usar - User Guide ESP32-DevKitC V4, nota 2 das tabelas

ESP32-DevKitC V4 User Guide (docs.espressif.com/projects/esp-dev-kits/en/latest /esp32/esp32-devkitc/user_guide.html). O esquemático oficial em PDF

(dl.espressif.com/dl/schematics/esp32_devkitc_v4_sch.pdf) pode numerar os headers de forma diferente - conferir antes do layout.

IO16/IO17 (J3-12/J3-11): disponiveis no WROOM-32E (DevKitC-32E); reservados no WROVER (User Guide, nota 3). MONTAGEM DO U1: 2 soquetes femea 1x19 P2.54 (PinSocket_1x19_P2.54mm_Vertical) ou footprint oficial Espressif:ESP32-DevKitC (github.com/espressif/kicad-libraries) - definir na fase de layout. MONTAGEM EM TETO: 1. Fixacao: 4 furos M3 nos cantos da carrier (~70x55 mm); nao sobrepor furo ao

sobre a regiao da antena (extremidade do DevKitC). 3. Furo central de passagem de cabo de alimentacao. 4. Orientar a antena para baixo, apontando ao salao (alcance BLE ao teto/piso). USB / PROGRAMACAO: O DevKitC-32E tem bridge USB-UART (CP2102N) e conector Micro-USB onboard: flash e debug sao feitos pelo USB do proprio DevKitC. A carrier NAO roteia USB de dados. J1 e EXCLUSIVO de alimentacao 5V (USB-C femea power-only ou terminal 2 vias). Nunca alimentar por J1 e pelo USB do DevKitC ao mesmo tempo - User Guide:

EN (J2-2): pull-up R1 10k -> +3V3 e botao SW1 (NA) -> GND. Replica o circuito
do DevKitC V4 (R10 10k + C10 1uF + botao EN onboard, esp32_devkitc_v4_sch.pdf); o RC interno do DevKitC permanece - R1/SW1 sao acesso externo em servico. ALIMENTACAO: J1 fornece 5V no pino J2-19; o LDO AMS1117-3.3 onboard gera 3.3V

J1USB-C 5V power-only ou terminal 2p GND

soquete do DevKitC. 2. Antena WiFi/BLE do DevKitC: manter >= 10 mm de qualquer superficie metalica

(tampa da caixa, perfil metalico, concreto armado). Nao usar tampa metalica

Pinout J2/J3: ESP32-DevKitC V4 User Guide (docs.espressif.com)
Carrier minima: alimentacao 5V + EN acessivel; firmware nao usa GPIO
NibasRockBar
Sheet: /
File: gateway_esp32.kicad_sch
Title: Gateway ESP32 - Carrier Board (ESP32-DevKitC-32E)

Size: A3 | Rev: A | F Date: 2026-09-09
KiCad E.D.A. 10.0.6 | Id: 1/1

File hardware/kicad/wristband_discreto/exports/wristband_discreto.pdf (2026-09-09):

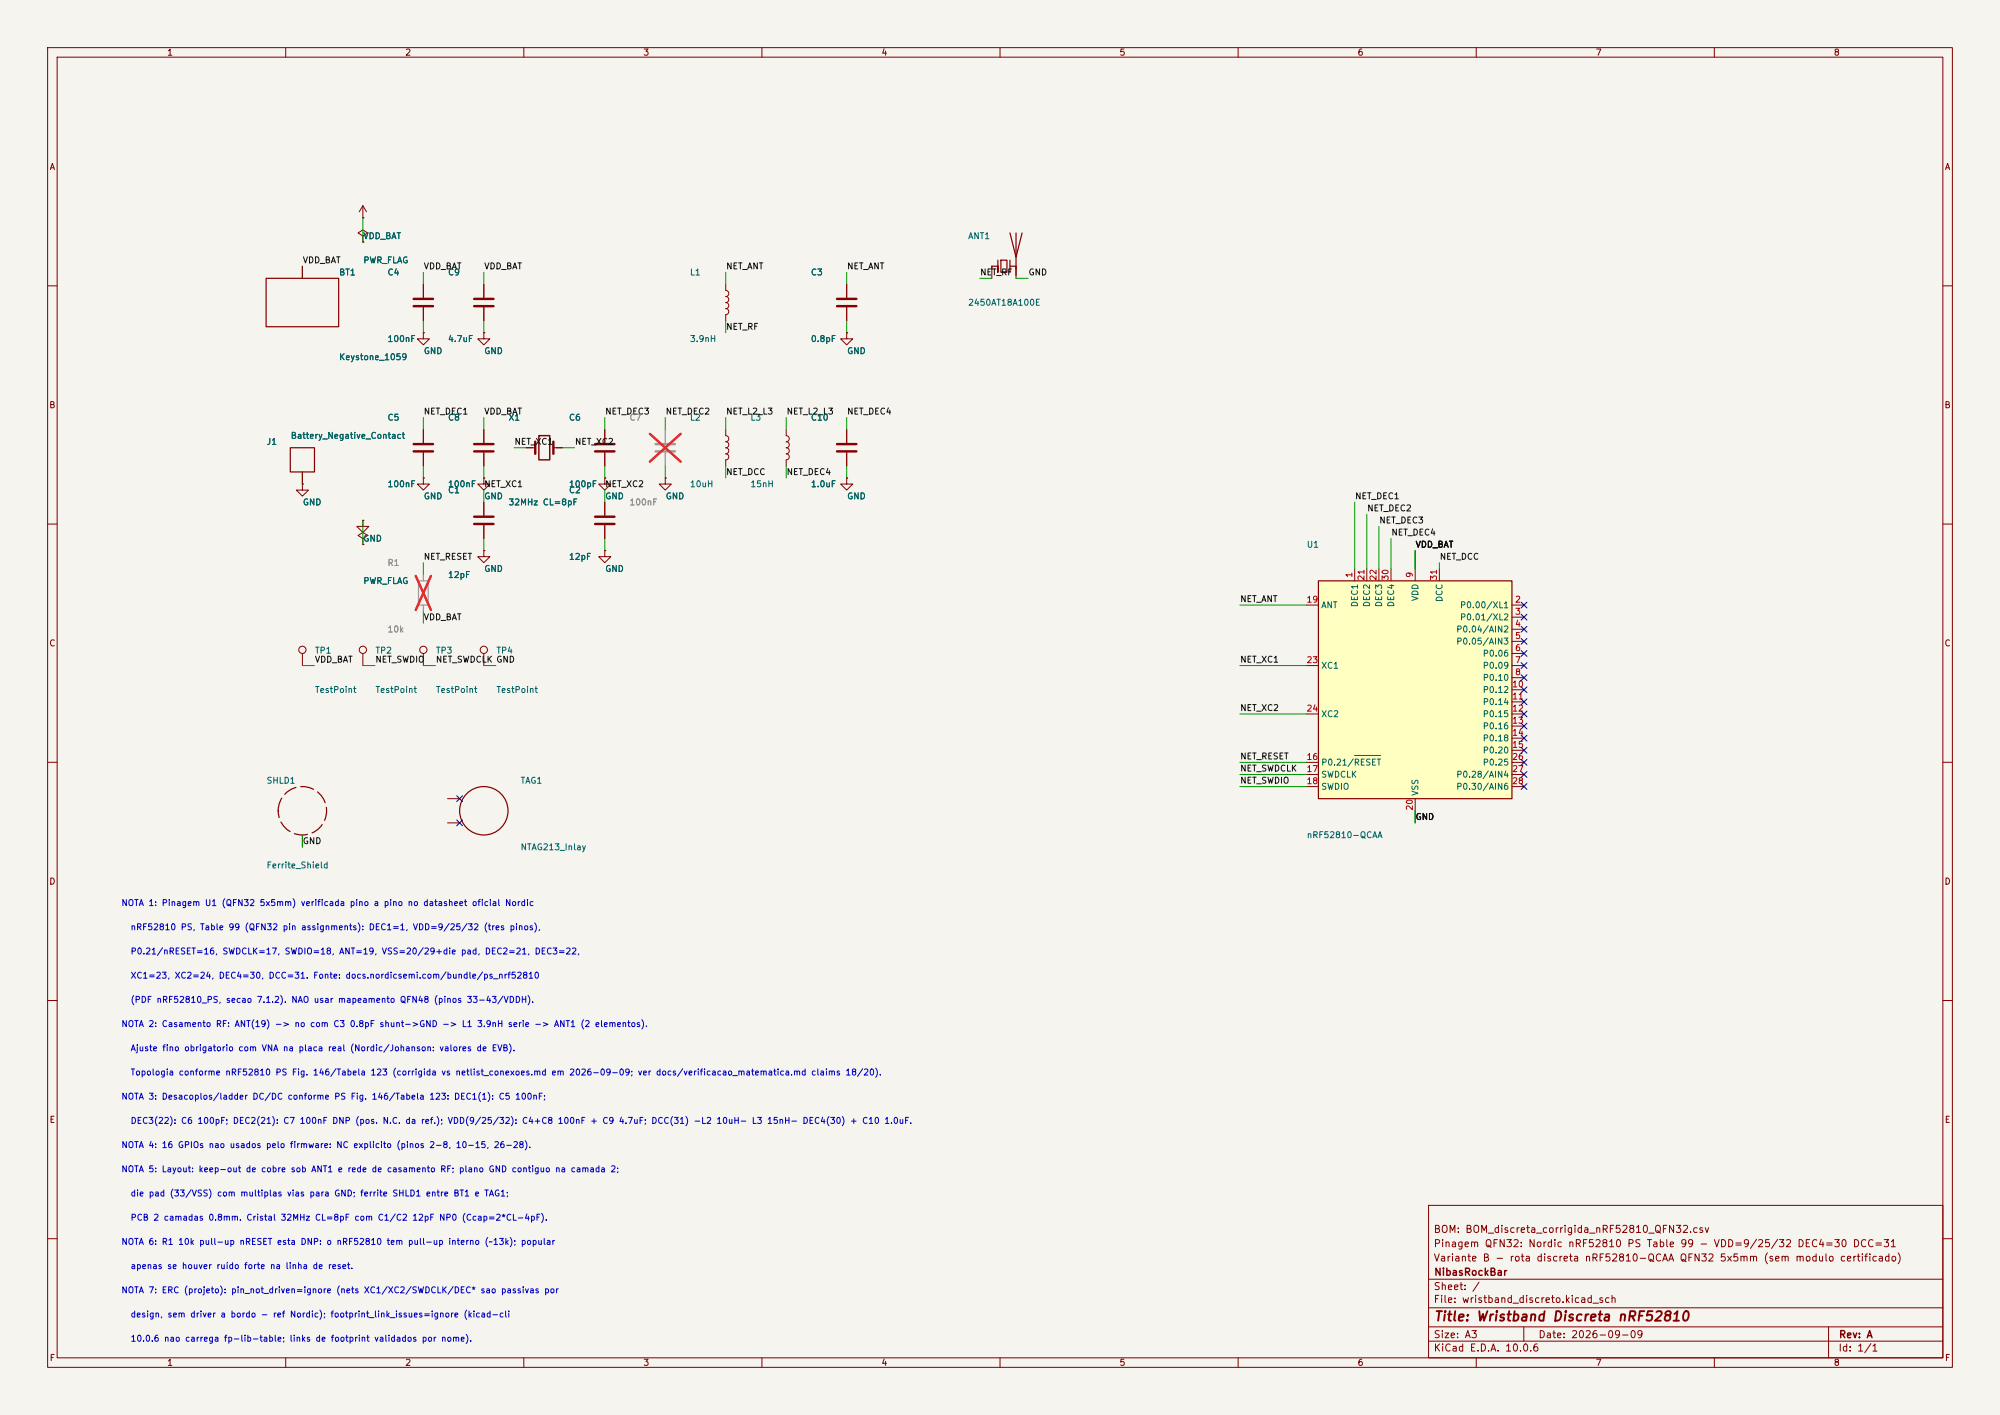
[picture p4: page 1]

Ajuste fino obrigatorio com VNA na placa real (Nordic/Johanson: valores de EVB). NOTA 3: Desacoplos/ladder DC/DC conforme PS Fig. 146/Tabela 123: DEC1(1): C5 100nF; NOTA 4: 16 GPIOs nao usados pelo firmware: NC explicito (pinos 2-8, 10-15, 26-28). PCB 2 camadas 0.8mm. Cristal 32MHz CL=8pF com C1/C2 12pF NP0 (Ccap=2*CL-4pF). NOTA 6: R1 10k pull-up nRESET esta DNP: o nRF52810 tem pull-up interno (~13k); popular NOTA 1: Pinagem U1 (QFN32 5x5mm) verificada pino a pino no datasheet oficial Nordic die pad (33/VSS) com multiplas vias para GND; ferrite SHLD1 entre BT1 e TAG1; apenas se houver ruído forte na linha de reset. NOTA 7: ERC (projeto): pin_not_driven=ignore (nets XC1/XC2/SWDCLK/DEC* sao passivas por design, sem driver a bordo - ref Nordic); footprint_link_issues=ignore (kicad-cli

nRF52810 PS, Table 99 (QFN32 pin assignments): DEC1=1, VDD=9/25/32 (tres pinos),

P0.21/nRESET=16, SWDCLK=17, SWDIO=18, ANT=19, VSS=20/29+die pad, DEC2=21, DEC3=22, NOTA 2: Casamento RF: ANT(19) -> no com C3 0.8pF shunt->GND -> L1 3.9nH serie -> ANT1 (2 elementos).

XC1=23, XC2=24, DEC4=30, DCC=31. Fonte: docs.nordicsemi.com/bundle/ps_nrf52810

(PDF nRF52810_PS, secao 7.1.2). NAO usar mapeamento QFN48 (pinos 33-43/VDDH).

Topologia conforme nRF52810 PS Fig. 146/Tabela 123 (corrigida vs netlist_conexoes.md em 2026-09-09; ver docs/verificacao_matematica.md claims 18/20).

DEC3(22): C6 100pF; DEC2(21): C7 100nF DNP (pos. N.C. da ref.); VDD(9/25/32): C4+C8 100nF + C9 4.7uF; DCC(31) -L2 10uH- L3 15nH- DEC4(30) + C10 1.0uF. NOTA 5: Layout: keep-out de cobre sob ANT1 e rede de casamento RF; plano GND contiguo na camada 2;

BOM: BOM_discreta_corrigida_nRF52810_QFN32.csv
Pinagem QFN32: Nordic nRF52810 PS Table 99 - VDD=9/25/32 DEC4=30 DCC=31
Variante B - rota discreta nRF52810-QCAA QFN32 5x5mm (sem modulo certificado)
NibasRockBar
Sheet: /
File: wristband_discreto.kicad_sch
Title: Wristband Discreta nRF52810

10.0.6 nao carrega fp-lib-table; links de footprint validados por nome).

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

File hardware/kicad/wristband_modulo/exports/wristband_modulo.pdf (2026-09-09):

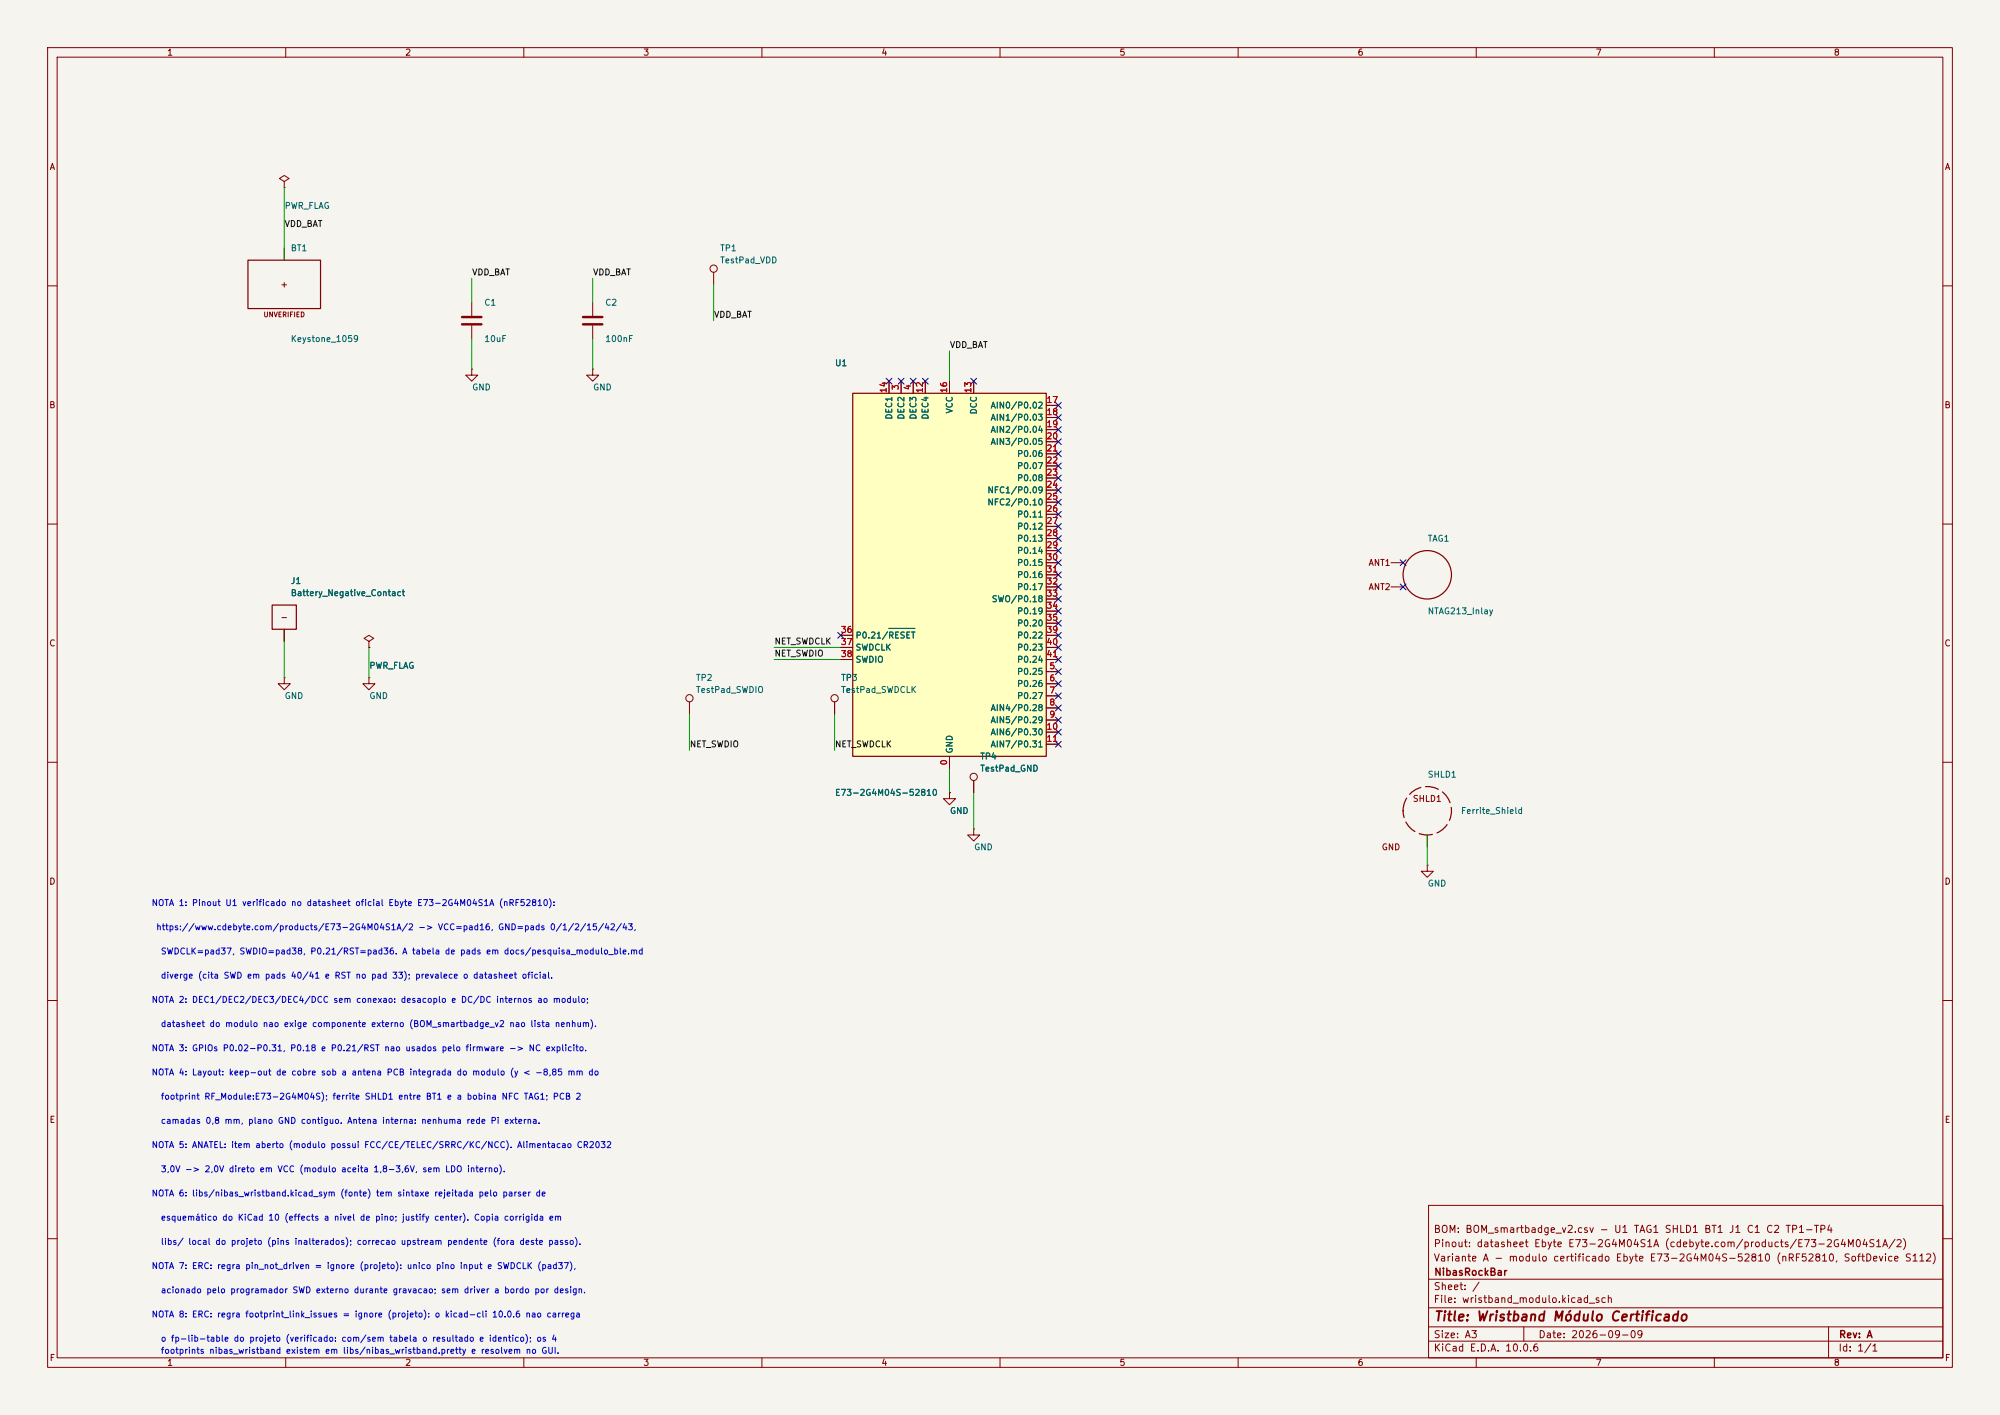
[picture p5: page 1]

NOTA 1: Pinout U1 verificado no datasheet oficial Ebyte E73-2G4M04S1A (nRF52810): PWR_FLAG

diverge (cita SWD em pads 40/41 e RST no pad 33); prevalece o datasheet oficial. https://www.cdebyte.com/products/E73-2G4M04S1A/2 -> VCC=pad16, GND=pads 0/1/2/15/42/43, NOTA 2: DEC1/DEC2/DEC3/DEC4/DCC sem conexao: desacoplo e DC/DC internos ao modulo; datasheet do modulo nao exige componente externo (BOM_smartbadge_v2 nao lista nenhum). NOTA 3: GPIOs P0.02-P0.31, P0.18 e P0.21/RST nao usados pelo firmware -> NC explicito. NOTA 4: Layout: keep-out de cobre sob a antena PCB integrada do modulo (y < -8,85 mm do

SWDCLK=pad37, SWDIO=pad38, P0.21/RST=pad36. A tabela de pads em docs/pesquisa_modulo_ble.md

footprint RF_Module:E73-2G4M04S); ferrite SHLD1 entre BT1 e a bobina NFC TAG1; PCB 2

camadas 0,8 mm, plano GND contiguo. Antena interna: nenhuma rede Pi externa. NOTA 5: ANATEL: item aberto (modulo possui FCC/CE/TELEC/SRRC/KC/NCC). Alimentacao CR2032

3,0V -> 2,0V direto em VCC (modulo aceita 1,8-3,6V, sem LDO interno). NOTA 6: libs/nibas_wristband.kicad_sym (fonte) tem sintaxe rejeitada pelo parser de

esquemático do KiCad 10 (effects a nivel de pino; justify center). Copia corrigida em

BOM: BOM_smartbadge_v2.csv - U1 TAG1 SHLD1 BT1 J1 C1 C2 TP1-TP4
Pinout: datasheet Ebyte E73-2G4M04S1A (cdebyte.com/products/E73-2G4M04S1A/2)
Variante A - modulo certificado Ebyte E73-2G4M04S-52810 (nRF52810, SoftDevice S112)
NibasRockBar
Sheet: /
File: wristband_modulo.kicad_sch
Title: Wristband Módulo Certificado

libs/ local do projeto (pins inalterados); correcao upstream pendente (fora deste passo). NOTA 7: ERC: regra pin_not_driven = ignore (projeto): unico pino input e SWDCLK (pad37), acionado pelo programador SWD externo durante gravacao; sem driver a bordo por design. NOTA 8: ERC: regra footprint_link_issues = ignore (projeto): o kicad-cli 10.0.6 nao carrega

o fp-lib-table do projeto (verificado: com/sem tabela o resultado e identico); os 4
footprints nibas_wristband existem em libs/nibas_wristband.pretty e resolvem no GUI.

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

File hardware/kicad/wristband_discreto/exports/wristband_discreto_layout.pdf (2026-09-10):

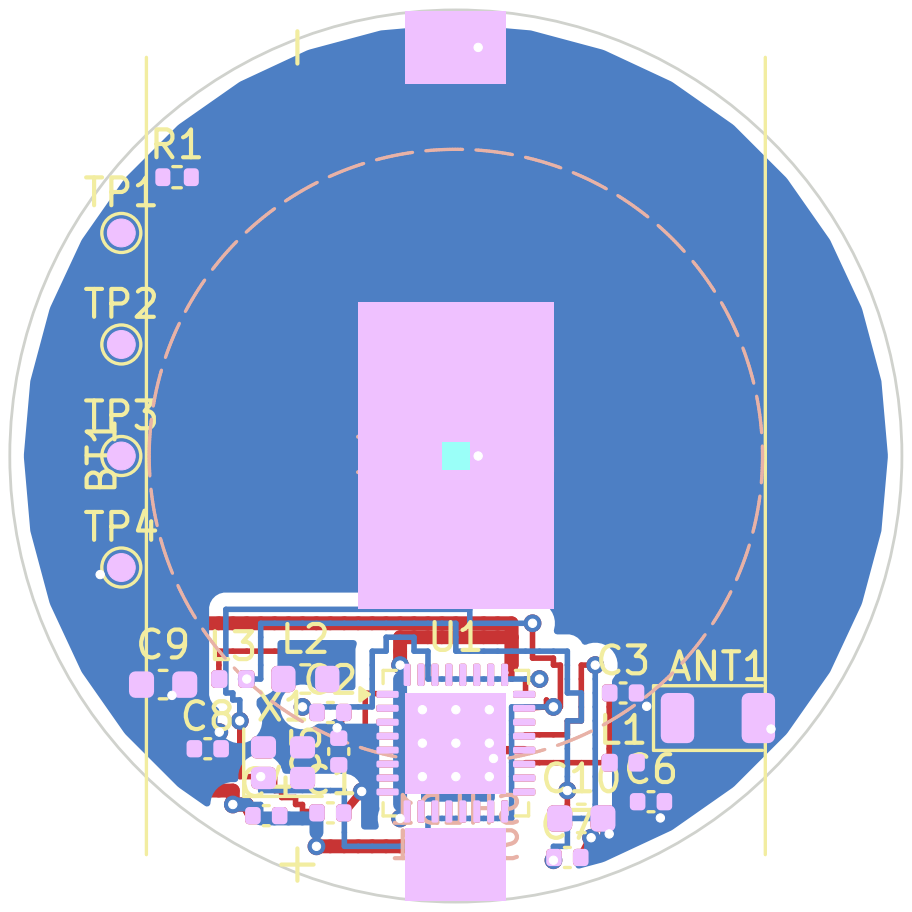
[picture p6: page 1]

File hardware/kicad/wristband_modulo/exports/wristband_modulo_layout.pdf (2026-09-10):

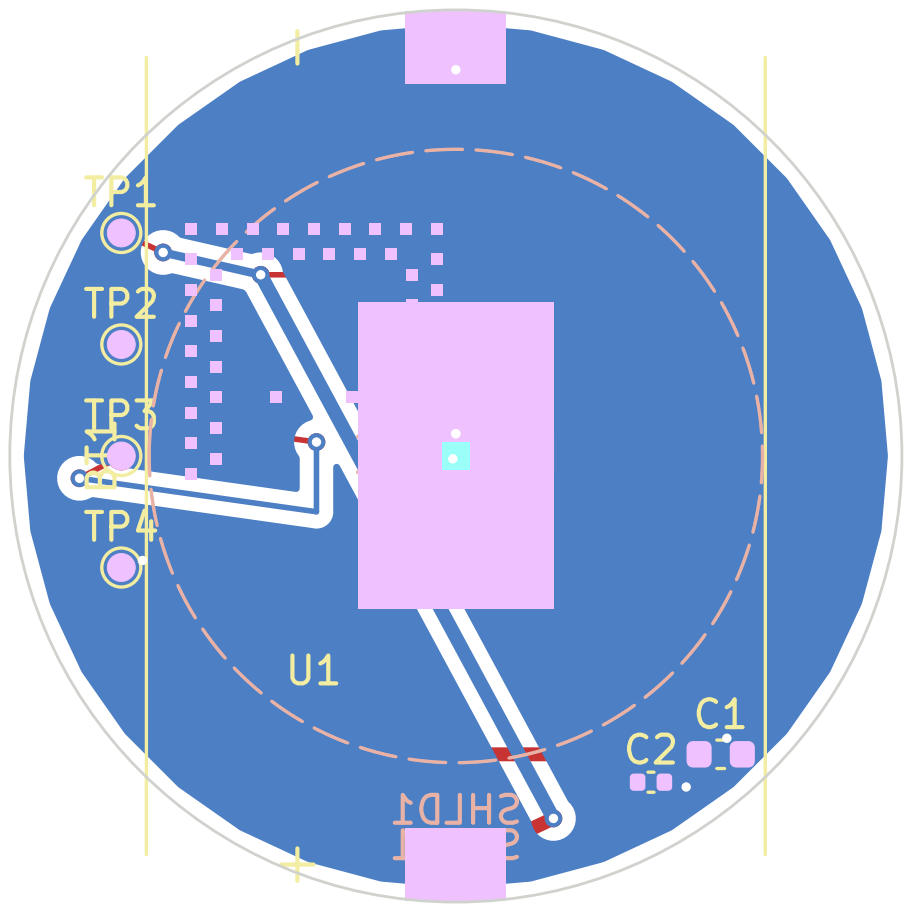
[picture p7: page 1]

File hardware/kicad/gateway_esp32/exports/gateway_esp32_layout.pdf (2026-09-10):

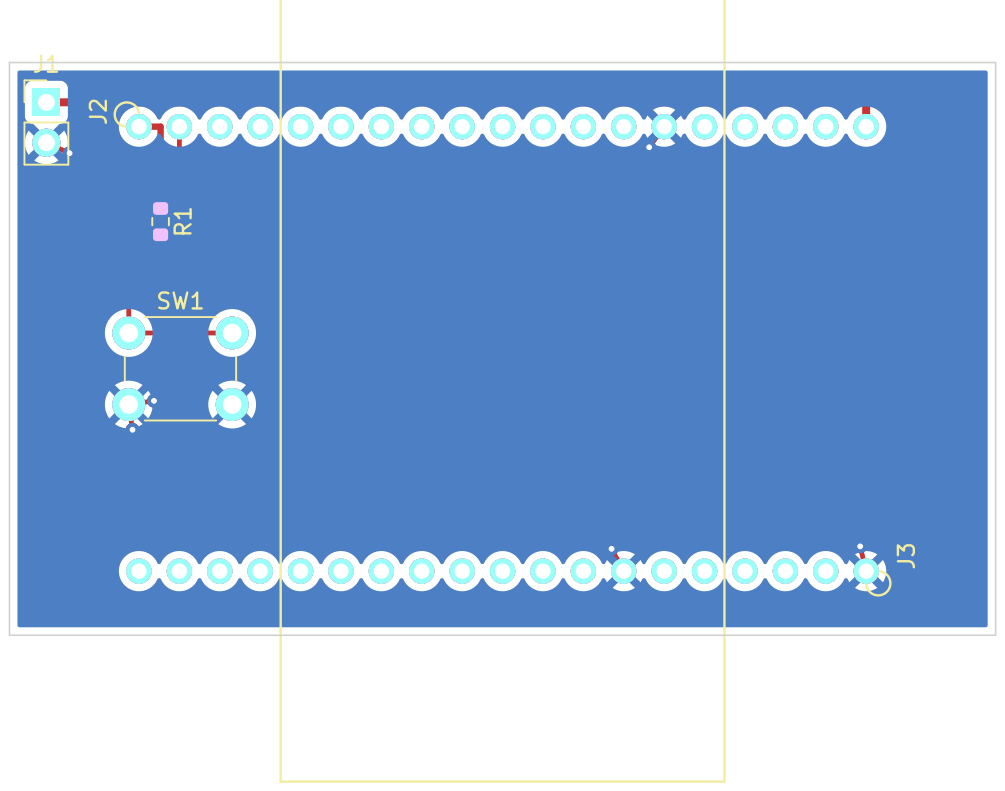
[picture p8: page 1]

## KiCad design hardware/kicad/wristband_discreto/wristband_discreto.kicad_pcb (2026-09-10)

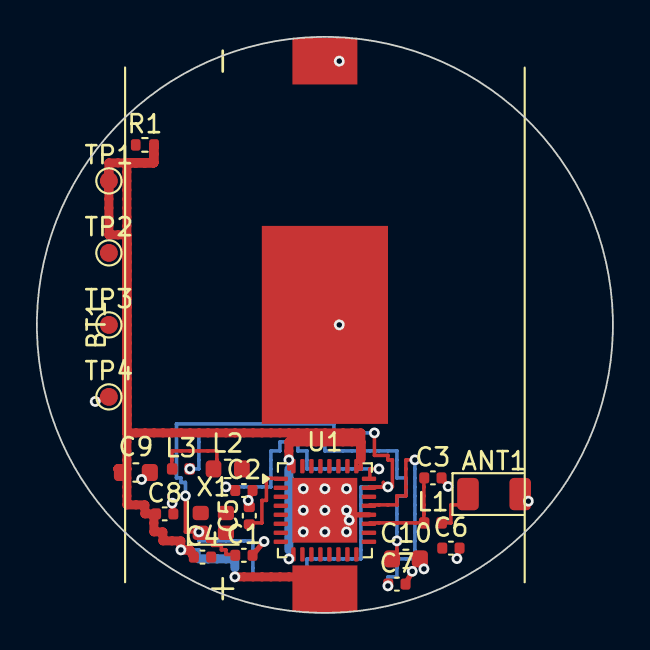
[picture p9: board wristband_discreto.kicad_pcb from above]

Board: 2 copper layers, 32.0 x 32.0 mm, 23 parts (1 on the bottom side), 15 nets.

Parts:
ANT1: Johanson_2450AT18x100
BT1: Keystone_1060; Keystone_1060_CR2032_SMT
C1, C2, C3, C4, C5, C6, C7, C8: C_0402_1005Metric
C9, C10: C_0603_1608Metric
L1, L3: L_0402_1005Metric
L2: L_0603_1608Metric
R1: R_0402_1005Metric
SHLD1: Ferrite_Shield_22mm; SHLD1_Ferrite_Shield_22mm
TP1, TP2, TP3, TP4: TestPoint_Pad_D1.0mm
U1: QFN-32-1EP_5x5mm_P0.5mm_EP3.6x3.6mm
X1: Crystal_SMD_2016-4Pin_2.0x1.6mm

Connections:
GND: ANT1.2, BT1.2, BT1.3, C1.2, C2.2, C3.2, C4.2, C5.2, C6.2, C7.2, C8.2, C9.2, C10.2, SHLD1.1, TP4.1, U1.20, U1.29, U1.33
NET_ANT: C3.1, L1.1, U1.19
NET_DCC: L2.2, U1.31
NET_DEC1: C5.1, U1.1
NET_DEC2: C7.1, U1.21
NET_DEC3: C6.1, U1.22
NET_DEC4: C10.1, L3.2, U1.30
NET_L2_L3: L2.1, L3.1
NET_RESET: R1.1, U1.16
NET_RF: ANT1.1, L1.2
NET_SWDCLK: TP3.1, U1.17
NET_SWDIO: TP2.1, U1.18
NET_XC1: C1.1, U1.23, X1.1
NET_XC2: C2.1, U1.24, X1.2
VDD_BAT: BT1.1, C4.1, C8.1, C9.1, R1.2, TP1.1, U1.9, U1.25, U1.32

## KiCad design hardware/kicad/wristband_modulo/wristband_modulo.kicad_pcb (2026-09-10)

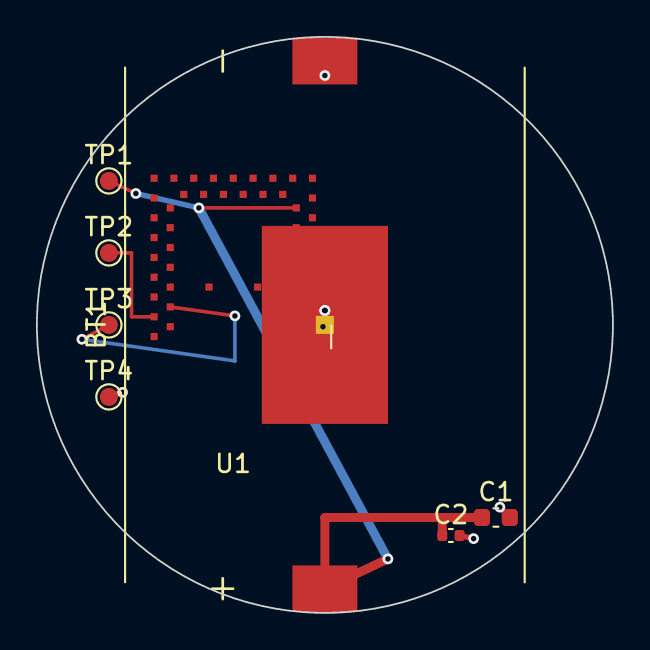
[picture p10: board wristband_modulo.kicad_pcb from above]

Board: 2 copper layers, 32.0 x 32.0 mm, 9 parts (1 on the bottom side), 4 nets.

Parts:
BT1: Keystone_1060; Keystone_1060_CR2032_SMT
C1: C_0603_1608Metric
C2: C_0402_1005Metric
SHLD1: Ferrite_Shield_22mm; SHLD1_Ferrite_Shield_22mm
TP1, TP2, TP3, TP4: TestPoint_Pad_D1.0mm
U1: BM832A

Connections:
GND: BT1.2, BT1.3, C1.2, C2.2, SHLD1.1, TP4.1, U1.1
NET_SWDCLK: TP3.1, U1.42
NET_SWDIO: TP2.1, U1.43
VDD_BAT: BT1.1, C1.1, C2.1, TP1.1, U1.14

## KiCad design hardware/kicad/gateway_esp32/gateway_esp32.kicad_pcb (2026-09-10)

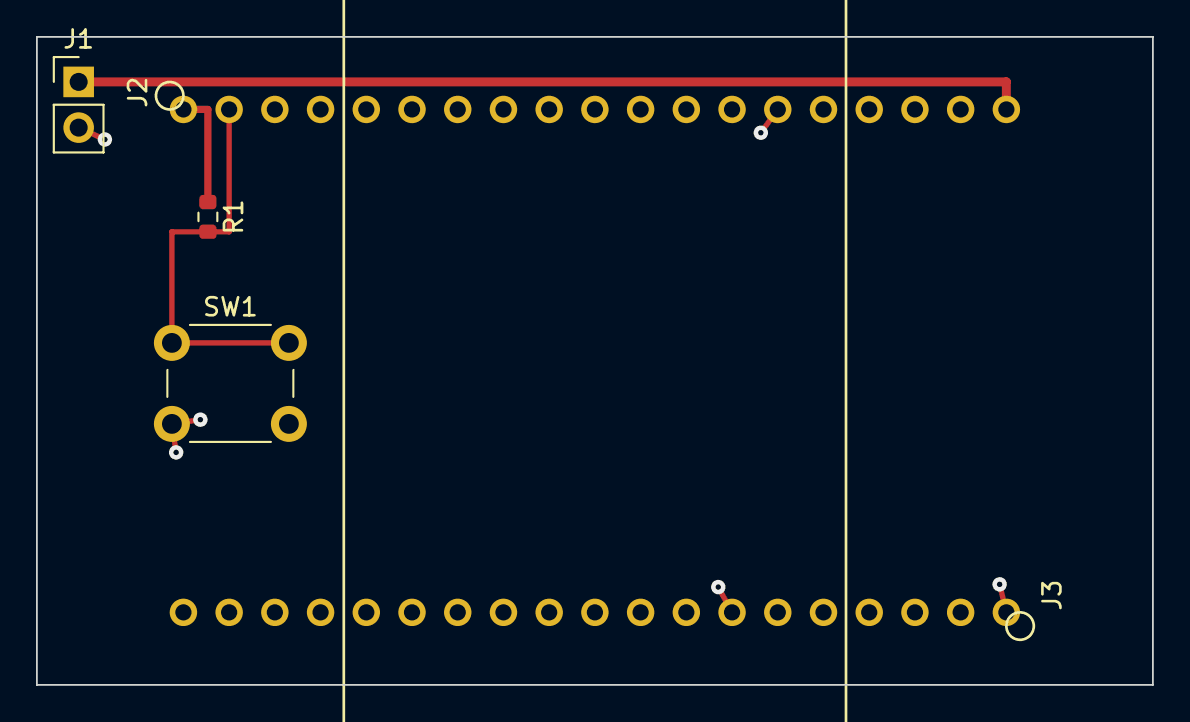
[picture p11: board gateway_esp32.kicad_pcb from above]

Board: 2 copper layers, 62.0 x 36.0 mm, 4 parts (0 on the bottom side), 4 nets.

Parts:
J1: PinHeader_1x02_P2.54mm_Vertical
R1: R_0603_1608Metric
SW1: SW_PUSH_6mm
U1: ESP32-DevKitC-32E; ESP32-DevKitC-32E_Carrier

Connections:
+3V3: R1.1, U1.1
+5V: J1.1, U1.19
EN: R1.2, SW1.1, U1.2
GND: J1.2, SW1.2, U1.14, U1.20, U1.26

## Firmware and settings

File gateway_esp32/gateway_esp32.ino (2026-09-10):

/*
 * Smart Badge Pub - Firmware do Gateway de Teto (ESP32 + Arduino framework)
 *
 * Bibliotecas necessarias (Library Manager do Arduino IDE):
 *   - "ESP32 BLE Arduino" (API classica: BLEDevice/BLEScan/BLEAdvertisedDevice).
 *     NAO instalar "NimBLE-Arduino" junto - tem nomes de classe diferentes
 *     (NimBLEScan, NimBLEAdvertisedDevice) e quebra este codigo se for usada no lugar.
 *   - "PubSubClient" (Nick O'Leary) para MQTT
 *   - "ArduinoJson" para montar o payload
 *
 * Funcao: varrer continuamente pacotes BLE advertising das pulseiras, filtrar o RSSI com
 * EWMA (media movel exponencial) para reduzir a flutuacao causada por corpos/reflexos, e
 * publicar no broker MQTT local.
 */

#include <BLEDevice.h>
#include <BLEScan.h>
#include <BLEAdvertisedDevice.h>
#include <WiFi.h>
#include <PubSubClient.h> // compilacao validada com PubSubClient 2.8 (nao trocar sem testar)
#include <ArduinoJson.h>  // compilacao validada com ArduinoJson 7.4.3; StaticJsonDocument e API v6 com deprecation na v7 (manter ate migracao dedicada para JsonDocument)
#include <Preferences.h>  // provisioning WiFi/MQTT via NVS (namespace "nibas")
#include <map>

// ---------- CONFIG (placeholders - fallback quando o NVS esta vazio) ----------
// Provisionamento por gateway via monitor serial (115200, com newline):
//   config ssid=<WIFI> pass=<SENHA> broker=<IP_OU_HOST> gw=<gateway_teto_XX>
// Exemplo:
//   config ssid=PUB_WIFI pass=troque_aqui broker=192.168.0.10 gw=gateway_teto_02
// Regras: salva no NVS (namespace "nibas", chaves ssid/pass/broker/gateway_id);
// vale por device e sobrevive a reflash (so apaga com erase flash). Sem espacos
// nos valores (parse simples por espaco). A senha NUNCA e ecoada de volta.
// Apos salvar, reinicie o ESP32 para reconectar com os novos valores.
// Provisioning via NVS implementado; ver bloco CONFIG.
char WIFI_SSID[33]     = "PUB_WIFI";       // NVS "nibas"/ssid (max 32 chars)
char WIFI_PASSWORD[64] = "SENHA_AQUI";     // NVS "nibas"/pass (max 63 chars)
char MQTT_BROKER[64]   = "192.168.0.10";   // NVS "nibas"/broker - IP do servidor local (Mosquitto)
const int   MQTT_PORT      = 1883;
// TODO: preencher por device antes do deploy; vazio = sem auth (comportamento atual).
const char* MQTT_USER      = "";
const char* MQTT_PASSWORD  = "";
char GATEWAY_ID[32]    = "gateway_teto_02";  // NVS "nibas"/gateway_id - TROCAR por gateway, identifica a zona
const char* MFG_COMPANY_ID_HEX = "FFFF";         // referencial: deve bater com MANUFACTURER_ID em firmware/main.c

// Filtro do manufacturer data - deve bater com MANUFACTURER_ID (0xFFFF) em firmware/main.c
const uint16_t EXPECTED_COMPANY_ID = 0xFFFF;
const uint8_t EXPECTED_PROTO = 1;

const unsigned long CONNECT_TIMEOUT_MS = 15000;  // timeout de conexao Wi-Fi/MQTT

const float  EWMA_ALPHA        = 0.2f;   // 0.1 (mais suave/lento) .. 0.3 (mais reativo)
const int    SCAN_WINDOW_MS    = 1000;   // janela de cada ciclo de scan
const int    PUBLISH_PERIOD_MS = 1000;   // periodicidade de publicacao por tag vista

WiFiClient   wifiClient;
PubSubClient mqttClient(wifiClient);
BLEScan*     pBLEScan;

struct TagState {
    float    rssi_ewma;
    uint32_t last_seen_ms;
    uint16_t seq;
};

std::map<std::string, TagState> g_tags; // chave = MAC address da pulseira

// ---------- Wi-Fi / MQTT ----------
// Conexoes com timeout (nunca travam o boot indefinidamente).
bool connectWiFi() {
    WiFi.begin(WIFI_SSID, WIFI_PASSWORD);
    uint32_t t0 = millis();
    while (WiFi.status() != WL_CONNECTED) {
        if (millis() - t0 >= CONNECT_TIMEOUT_MS) {
            // TODO: apos falhas repetidas, entrar em modo de configuracao (AP
            // proprio de provisioning) em vez de retentar no proximo loop.
            return false;
        }
        delay(300);
    }
    return true;
}

bool connectMQTT() {
    uint32_t t0 = millis();
    while (!mqttClient.connected()) {
        String clientId = String("gw_") + GATEWAY_ID;
        // Para TLS usar WiFiClientSecure no lugar de WiFiClient (fora do escopo: requer cert + NTP).
        bool ok;
        if (strlen(MQTT_USER) > 0) {
            ok = mqttClient.connect(clientId.c_str(), MQTT_USER, MQTT_PASSWORD);
        } else {
            ok = mqttClient.connect(clientId.c_str());
        }
        if (ok) return true;
        if (millis() - t0 >= CONNECT_TIMEOUT_MS) return false;
        delay(1000);
    }
    return true;
}

// ---------- Filtro EWMA ----------
// RSSI_filt[n] = alpha * RSSI_raw[n] + (1 - alpha) * RSSI_filt[n-1]
float applyEWMA(float previous, int raw_rssi, bool first_sample) {
    if (first_sample) return (float)raw_rssi;
    return EWMA_ALPHA * raw_rssi + (1.0f - EWMA_ALPHA) * previous;
}

// ---------- Callback de deteccao BLE ----------
class GatewayCallback : public BLEAdvertisedDeviceCallbacks {
    void onResult(BLEAdvertisedDevice advertisedDevice) override {
        // Filtra apenas pacotes com o Company ID esperado (manufacturer specific data)
        if (!advertisedDevice.haveManufacturerData()) return;

        // Core esp32 3.x: getManufacturerData() retorna String (binario preservado com length)
        String manuf = advertisedDevice.getManufacturerData();
        // company_id(2) + proto_version(1) + battery(1) + seq(2) = 6 bytes.
        // Indices acessados abaixo vao ate manuf[5], entao o minimo e' 6, nao 5.
        if (manuf.length() < 6) return;

        // company_id little-endian (mesma ordem escrita pelo ble_advdata_encode no firmware)
        uint16_t company_id = (uint8_t)manuf[0] | ((uint8_t)manuf[1] << 8);
        if (company_id != EXPECTED_COMPANY_ID) return; // advertiser desconhecido: descarta

        uint8_t proto_version = (uint8_t)manuf[2];
        if (proto_version != EXPECTED_PROTO) return; // versao de protocolo desconhecida: descarta

        std::string mac = advertisedDevice.getAddress().toString().c_str(); // toString() = String no core 3.x
        int rssi = advertisedDevice.getRSSI();
        uint8_t battery_pct = (uint8_t)manuf[3];
        uint16_t seq = (uint8_t)manuf[4] | ((uint8_t)manuf[5] << 8);

        uint32_t now = millis();
        auto it = g_tags.find(mac);
        bool first = (it == g_tags.end());

        // Rate-limit por tag: publica no maximo 1x a cada PUBLISH_PERIOD_MS.
        // Pacotes dentro do periodo sao descartados (last_seen_ms marca o ultimo
        // ciclo efetivamente medido/publicado pela tag).
        if (!first && (now - it->second.last_seen_ms) < PUBLISH_PERIOD_MS) return;

        float prev = first ? 0.0f : it->second.rssi_ewma;
        float filt = applyEWMA(prev, rssi, first);

        g_tags[mac] = { filt, now, seq };

        publishTelemetry(mac, filt, rssi, battery_pct, seq);
    }
};

void publishTelemetry(const std::string& mac, float rssi_filt, int rssi_raw,
                       uint8_t battery_pct, uint16_t seq) {
    StaticJsonDocument<256> doc;
    doc["wristband_mac"] = mac;
    doc["gateway_id"]     = GATEWAY_ID;
    doc["rssi_raw"]       = rssi_raw;
    doc["rssi_ewma"]      = rssi_filt;
    doc["battery_pct"]    = battery_pct;
    doc["seq"]            = seq;
    doc["ts_ms"]          = millis();

    char buffer[256];
    size_t n = serializeJson(doc, buffer);

    char topic[64];
    snprintf(topic, sizeof(topic), "pub/telemetria/%s", GATEWAY_ID);

    // Cast explicito: sem ele a overload (topic, payload, retained) e' escolhida e o
    // tamanho n vira flag retained. O correto e' o publish length-based.
    mqttClient.publish(topic, (const uint8_t*)buffer, (unsigned int)n);
}

// ---------- Provisioning via NVS (namespace "nibas") ----------
// Le os valores salvos; campo ausente ou vazio = mantem o placeholder do CONFIG.
void loadProvisioning() {
    Preferences prefs;
    if (!prefs.begin("nibas", true)) {
        Serial.println("NVS: sem namespace nibas - usando placeholders do CONFIG");
        return;
    }
    String v;
    v = prefs.getString("ssid", "");
    if (v.length() > 0) v.toCharArray(WIFI_SSID, sizeof(WIFI_SSID));
    v = prefs.getString("pass", "");
    if (v.length() > 0) v.toCharArray(WIFI_PASSWORD, sizeof(WIFI_PASSWORD));
    v = prefs.getString("broker", "");
    if (v.length() > 0) v.toCharArray(MQTT_BROKER, sizeof(MQTT_BROKER));
    v = prefs.getString("gateway_id", "");
    if (v.length() > 0) v.toCharArray(GATEWAY_ID, sizeof(GATEWAY_ID));
    prefs.end();
}

// Extrai "chave=<valor>" da linha (valor vai ate o proximo espaco ou fim).
String cfgArg(const String& line, const char* key) {
    int i = line.indexOf(key);
    if (i < 0) return String();
    i += strlen(key);
    int j = line.indexOf(' ', i);
    if (j < 0) return line.substring(i);
    return line.substring(i, j);
}

// Comando serial: config ssid=<..> pass=<..> broker=<..> gw=<..>
// Salva no NVS e aplica nos buffers ativos (reinicie para reconectar).
void handleSerialConfig() {
    if (!Serial.available()) return;
    String line = Serial.readStringUntil('\n');
    line.trim();
    if (!line.startsWith("config ")) return;
    String ssid   = cfgArg(line, "ssid=");
    String pass   = cfgArg(line, "pass=");
    String broker = cfgArg(line, "broker=");
    String gw     = cfgArg(line, "gw=");
    if (ssid.isEmpty() && pass.isEmpty() && broker.isEmpty() && gw.isEmpty()) {
        Serial.println("Uso: config ssid=<WIFI> pass=<SENHA> broker=<IP> gw=<gateway_teto_XX>");
        return;
    }
    Preferences prefs;
    if (!prefs.begin("nibas", false)) {
        Serial.println("NVS: falha ao abrir namespace nibas");
        return;
    }
    if (ssid.length() > 0) {
        prefs.putString("ssid", ssid);
        ssid.toCharArray(WIFI_SSID, sizeof(WIFI_SSID));
    }
    if (pass.length() > 0) {
        prefs.putString("pass", pass);
        pass.toCharArray(WIFI_PASSWORD, sizeof(WIFI_PASSWORD));
    }
    if (broker.length() > 0) {
        prefs.putString("broker", broker);
        broker.toCharArray(MQTT_BROKER, sizeof(MQTT_BROKER));
    }
    if (gw.length() > 0) {
        prefs.putString("gateway_id", gw);
        gw.toCharArray(GATEWAY_ID, sizeof(GATEWAY_ID));
    }
    prefs.end();
    // Confirmacao sem ecoar a senha.
    Serial.println("NVS: configuracao salva. Reinicie para reconectar.");
    Serial.print("ssid: "); Serial.println(WIFI_SSID);
    Serial.println("pass: *****");
    Serial.print("broker: "); Serial.println(MQTT_BROKER);
    Serial.print("gw: "); Serial.println(GATEWAY_ID);
}

// ---------- Setup / Loop ----------
void setup() {
    Serial.begin(115200);
    loadProvisioning(); // NVS "nibas" (read-only); vazio = placeholders do CONFIG
    // Aviso de credencial placeholder — nao trava o boot, so alerta via Serial.
    if (strcmp(WIFI_PASSWORD, "SENHA_AQUI") == 0) {
        Serial.println("ATENÇÃO: credenciais placeholder — configure antes do deploy");
    }
    if (!connectWiFi()) {
        // Timeout - nao trava o boot; reconnect e retomado no loop().
        Serial.println("WiFi: timeout na conexao - seguindo sem rede");
    }
    mqttClient.setServer(MQTT_BROKER, MQTT_PORT);

    BLEDevice::init("");
    pBLEScan = BLEDevice::getScan();
    pBLEScan->setAdvertisedDeviceCallbacks(new GatewayCallback(), true);
    pBLEScan->setActiveScan(false);   // scan passivo - nao gasta tempo de radio pedindo scan response
    pBLEScan->setInterval(100);
    pBLEScan->setWindow(99);
}

void loop() {
    handleSerialConfig(); // provisioning via monitor serial (nao-bloqueante)
    if (WiFi.status() != WL_CONNECTED) connectWiFi();
    if (!mqttClient.connected()) connectMQTT();
    mqttClient.loop();

    pBLEScan->start(SCAN_WINDOW_MS / 1000.0, false);
    pBLEScan->clearResults();
}

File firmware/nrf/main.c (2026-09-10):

/*
 * Smart Badge Pub - Firmware da pulseira (nRF52810, nRF5 SDK v17.x, SoftDevice S112)
 *
 * Escopo deste arquivo: esqueleto de referencia, NAO e um projeto compilavel standalone.
 * Precisa ser integrado a um projeto nRF5 SDK real (pca10040e/blank + S112) com os
 * arquivos sdk_config.h, ble_advdata, nrf_pwr_mgmt, etc. do SDK da Nordic.
 *
 * Responsabilidades deste firmware:
 *   1. Habilitar o regulador DC/DC (economiza energia vs. LDO interno)
 *   2. Emitir pacotes de advertising BLE nao-conectaveis a cada ADV_INTERVAL_MS
 *   3. Incluir no payload: MAC address (automatico), nivel de bateria, numero de sequencia
 *   4. Dormir em System ON low-power entre eventos
 *
 * O NFC (NTAG213) e 100% passivo - nao precisa nem pode ser controlado por este firmware,
 * ele funciona por acoplamento indutivo com o leitor, sem consumir energia da bateria.
 */

#include "nrf_sdh.h"
#include "nrf_sdh_ble.h"
#include "nrf_pwr_mgmt.h"
#include "ble_advdata.h"
#include "nrf_drv_saadc.h"
#include "app_timer.h"

#define ADV_INTERVAL_MS         1500                    // intervalo entre pacotes de advertising
#define ADV_INTERVAL_UNITS      MSEC_TO_UNITS(ADV_INTERVAL_MS, UNIT_0_625_MS)
#define DEVICE_NAME             "PUBBADGE"
#define MANUFACTURER_ID         0xFFFF                  // trocar por ID registrado se for a mercado
#define APP_BLE_CONN_CFG_TAG    1                       // tag de conn_cfg usada nas chamadas sd_ble_*

APP_TIMER_DEF(m_battery_timer);

typedef struct __attribute__((packed))
{
    uint16_t company_id;
    uint8_t  proto_version;
    uint8_t  battery_pct;      // 0-100
    uint16_t seq;              // numero de sequencia (detecta pacotes perdidos no gateway)
} adv_payload_t;

static adv_payload_t m_payload = { .company_id = MANUFACTURER_ID, .proto_version = 1 };
static ble_gap_adv_params_t m_adv_params;
static ble_gap_adv_data_t   m_adv_data;
static uint8_t              m_enc_advdata[BLE_GAP_ADV_SET_DATA_SIZE_MAX];
static uint8_t              m_adv_handle = BLE_GAP_ADV_SET_HANDLE_NOT_SET; // handle do advertising set

/* --- 0. SoftDevice: habilita a pilha BLE (S112) --- */
static void ble_stack_init(void)
{
    ret_code_t err_code = nrf_sdh_enable_request();
    APP_ERROR_CHECK(err_code);

    uint32_t ram_start = 0;
    err_code = nrf_sdh_ble_default_cfg_set(APP_BLE_CONN_CFG_TAG, &ram_start);
    APP_ERROR_CHECK(err_code);

    err_code = nrf_sdh_ble_enable(&ram_start);
    APP_ERROR_CHECK(err_code);
}

/* --- 1. Energia: habilita DC/DC interno no boot (apos o SoftDevice) --- */
static void power_init(void)
{
    // Ativa o conversor DC/DC do nRF52810 (requer L2=10uH, C10=1.0uF no hardware - ver BOM)
    ret_code_t err_code = sd_power_dcdc_mode_set(NRF_POWER_DCDC_ENABLE);
    APP_ERROR_CHECK(err_code);
}

/* --- 2. Leitura de bateria via SAADC (VDD direto, sem divisor resistivo) ---
 * Canal 0 = NRF_SAADC_INPUT_VDD; gain 1/6 com referencia interna 0.6V ->
 * full-scale = 0.6V * 6 = 3.6V (CR2032 ~3.0V cabe com folga).
 * Mapa 3.0V=100% .. 2.0V=0% (curva de descarga da CR2032 e' bem plana, entao esse
 * mapeamento e' grosseiro por natureza - suficiente para "bateria fraca/ok").
 * Matematica em mV inteiros (nRF52810 roda soft-float por padrao no SDK).
 */
#define SAADC_CH_VDD            0                       // canal 0 ligado ao VDD
#define BATTERY_EMPTY_MV        2000                    // 0% do mapa
#define BATTERY_FULL_MV         3000                    // 100% do mapa
#define SAADC_FULL_SCALE_MV     3600                    // ref 0.6V / gain 1/6
#define SAADC_MAX_COUNTS        4096                    // resolucao 12 bits

static void battery_saadc_init(void)
{
    nrf_drv_saadc_config_t saadc_cfg = NRF_DRV_SAADC_DEFAULT_CONFIG;
    saadc_cfg.resolution = NRF_SAADC_RESOLUTION_12BIT;
    saadc_cfg.oversample = NRF_SAADC_OVERSAMPLE_4X;

    // Config SE padrao do SDK: gain 1/6 + referencia interna 0.6V + acq 10us
    nrf_saadc_channel_config_t ch_cfg =
        NRF_DRV_SAADC_DEFAULT_CHANNEL_CONFIG_SE(NRF_SAADC_INPUT_VDD);
    ch_cfg.burst = NRF_SAADC_BURST_ENABLED; // com burst, 1 gatilho de SAMPLE entrega a media das 4 amostras

    ret_code_t err_code = nrf_drv_saadc_init(&saadc_cfg, NULL); // handler NULL = modo bloqueante
    APP_ERROR_CHECK(err_code);

    err_code = nrf_drv_saadc_channel_init(SAADC_CH_VDD, &ch_cfg);
    APP_ERROR_CHECK(err_code);
}

static uint8_t read_battery_percent(void)
{
    nrf_saadc_value_t raw;
    ret_code_t err_code = nrf_drv_saadc_sample_convert(SAADC_CH_VDD, &raw);
    APP_ERROR_CHECK(err_code);

    int32_t vbat_mv = ((int32_t)raw * SAADC_FULL_SCALE_MV) / SAADC_MAX_COUNTS;
    if (vbat_mv > BATTERY_FULL_MV)  vbat_mv = BATTERY_FULL_MV;
    if (vbat_mv < BATTERY_EMPTY_MV) vbat_mv = BATTERY_EMPTY_MV;
    return (uint8_t)(((vbat_mv - BATTERY_EMPTY_MV) * 100) / (BATTERY_FULL_MV - BATTERY_EMPTY_MV));
}

/* --- 3. Monta e atualiza o payload de advertising --- */
static void advdata_update(void)
{
    static uint16_t seq_counter = 0;

    m_payload.battery_pct = read_battery_percent();
    m_payload.seq         = seq_counter++;

    ble_advdata_manuf_data_t manuf_data;
    manuf_data.company_identifier = MANUFACTURER_ID;
    manuf_data.data.p_data        = (uint8_t *)&m_payload.proto_version;
    manuf_data.data.size          = sizeof(m_payload) - sizeof(m_payload.company_id);

    ble_advdata_t advdata;
    memset(&advdata, 0, sizeof(advdata));
    advdata.name_type          = BLE_ADVDATA_SHORT_NAME;
    advdata.short_name_len     = 4; // "PUBB"
    advdata.p_manuf_specific_data = &manuf_data;

    uint16_t len = sizeof(m_enc_advdata);
    ret_code_t err_code = ble_advdata_encode(&advdata, m_enc_advdata, &len);
    APP_ERROR_CHECK(err_code);

    m_adv_data.adv_data.p_data = m_enc_advdata;
    m_adv_data.adv_data.len    = len;

    // S112 7.x: atualiza o payload do advertising set ja configurado (params NULL mantem os atuais)
    err_code = sd_ble_gap_adv_set_configure(&m_adv_handle, &m_adv_data, NULL);
    APP_ERROR_CHECK(err_code);
}

/* --- 4. Configura advertising nao-conectavel (economiza energia vs. conectavel) --- */
static void advertising_init(void)
{
    memset(&m_adv_params, 0, sizeof(m_adv_params));
    m_adv_params.properties.type = BLE_GAP_ADV_TYPE_NONCONNECTABLE_NONSCANNABLE_UNDIRECTED;
    m_adv_params.p_peer_addr     = NULL;
    m_adv_params.filter_policy   = BLE_GAP_ADV_FP_ANY;
    m_adv_params.interval        = ADV_INTERVAL_UNITS; // unidades de 0.625 ms
    m_adv_params.duration        = 0; // sem limite de tempo

    advdata_update();

    // S112 7.x: cria o advertising set com dados + params em uma chamada
    ret_code_t err_code = sd_ble_gap_adv_set_configure(&m_adv_handle, &m_adv_data, &m_adv_params);
    APP_ERROR_CHECK(err_code);
}

/* --- 5. Timer que atualiza bateria/sequencia a cada ciclo de advertising --- */
static void battery_timer_handler(void *p_context)
{
    advdata_update();
}
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

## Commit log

2026-09-08 Initial commit: NibasRockBar smart badge project
    Firmware, gateway, backend, Deli integration docs, and prototyping budget/BOM.
    Claude-Session: https://claude.ai/code/session_01EY1M7XN71ocW2X9edA6m3N
    [BOM_discreta_corrigida_nRF52810_QFN32.csv, BOM_smartbadge_v2.csv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]
2026-09-09 Add KiCad schematics, PCB layouts, verification docs and session report
    [gateway_esp32.kicad_pcb, gateway_esp32.kicad_sch, gateway_esp32_layout.step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]
2026-09-09 Fix firmware bugs: real SAADC battery read, WiFi/MQTT timeouts, company ID filter, publish rate limit
    [gateway_esp32.ino, main.c]
2026-09-10 Fix security audit findings: backend API key auth, MQTT credentials support, input validation, no upstream error echo, gitignore coverage, dep hygiene
    [gateway_esp32.ino]
2026-09-10 Layouts finish, BM832A migration, fab package, quote, docs and status report
    [bom.csv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]
2026-09-10 Fix pre-fab punch list: regenerate stale DRC tracks JSON, Keystone 1059->1060 in BOMs, Fanstel BM832A URL
    [BOM_discreta_corrigida_nRF52810_QFN32.csv, BOM_smartbadge_v2.csv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]
2026-09-10 Manual routing discreta, module nudge, paho-mqtt 2.x, NVS provisioning, ANATEL scope fix
    [wristband_discreto.kicad_pcb, wristband_modulo.kicad_pcb, wristband_modulo_layout.step]
2026-09-10 Refresh discreta DRC/PDF/STEP post-r4, remove stale NVS TODO
    [wristband_discreto.kicad_pcb, wristband_discreto_layout.step]
2026-09-11 4-layer discreta migration, board_builder 4L support, ESP32 NVS provisioning, AirTag shell research, docs update
2026-09-11 Fix stale route count in layout_status (13→7 post-4L)
